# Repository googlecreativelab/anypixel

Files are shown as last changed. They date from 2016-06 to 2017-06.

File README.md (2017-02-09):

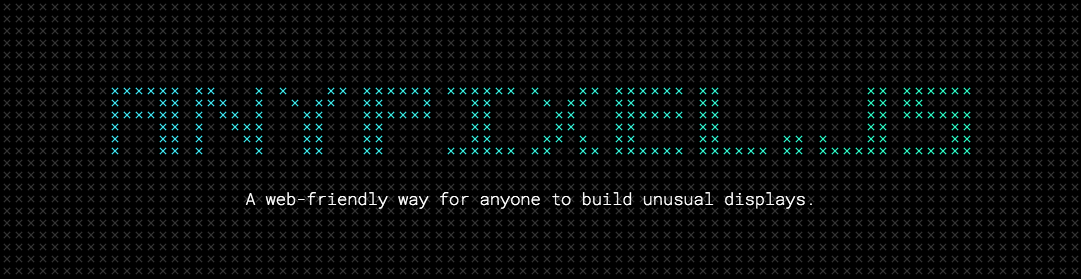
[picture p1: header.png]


[AnyPixel.js](http://googlecreativelab.github.io/anypixel) is an open-source software and hardware library that makes it possible to use the web to create big, unusual, interactive displays. Anyone can fork the code and the schematics to create their own display at any scale.

The first display using this platform is in the 8th Avenue lobby at the Google NYC office. To create this installation, we used 5880 off-the-shelf arcade buttons with LEDs inside them as our pixels. AnyPixel.js’ straightforward hardware/software framework makes it easy to build any display where each pixel is an interactive element.

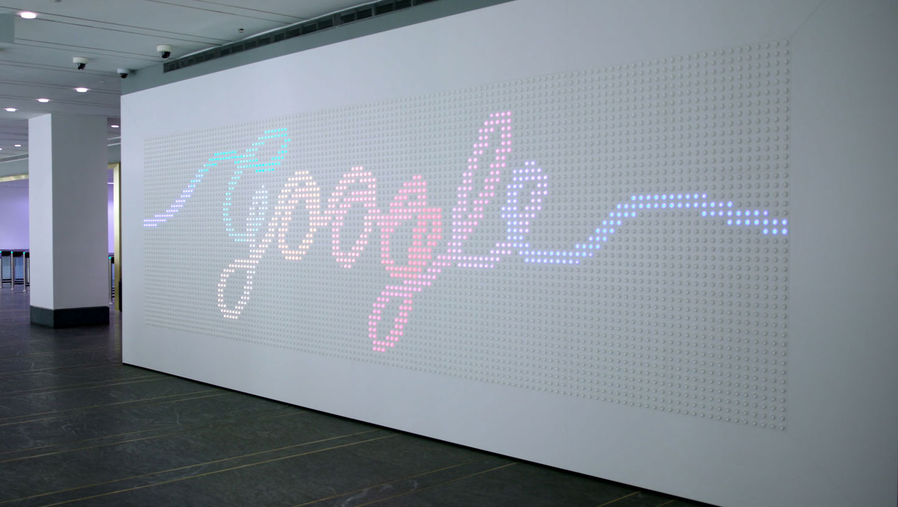
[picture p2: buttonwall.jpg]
buttonwall


## What You'll Find
- **/hardware** - EAGLE schematics, board layouts, CAD files, wiring diagrams, and blueprints.
- **/firmware** - microcontroller code, written for the STM32 family of devices.
- **/backend** - node.js and chrome applications for communicating with the hardware.
- **/frontend** - the app framework, an in-browser previewer, and 12 example apps written by Googlers and friends worldwide.
- **/rpi-example** - a simple starter example connecting a Raspberry Pi with AnyPixel to a single button for round trip communication.

## Getting Started

### Check out the examples 
We've included 12 example apps written by Googlers and friends for the 8th Avenue lobby display in NYC. To check them out, install the [previewer](https://github.com/googlecreativelab/anypixel/tree/master/frontend/previewer) and run one of the [examples](https://github.com/googlecreativelab/anypixel/tree/master/frontend/examples).

### Build your own app 
Building your own app is easy with the Anypixel framework. To get started, check out the [framework documentation](https://github.com/googlecreativelab/anypixel/tree/master/frontend/framework) and the [example app](https://github.com/googlecreativelab/anypixel/tree/master/frontend/examples/getting-started):

```js
var anypixel = require('anypixel'); 
var ctx = anypixel.canvas.getContext2D();

var colors = ['#F00', '#0F0', '#00F'];

/**  
 * * Listen for onButtonDown events and draw a 2x2 rectangle at the event site
 */
document.addEventListener('onButtonDown', function(event) {   
	ctx.fillStyle = colors[Math.floor(Math.random() * colors.length)];
	ctx.fillRect(event.detail.x - 1, event.detail.y - 1, 2, 2);
}); 
```

## Contributors
- [Jeremy Abel](https://github.com/jeremyabel)
- [Kyle Phillips](https://github.com/hapticdata)
- [Nick Fox-Gieg](https://github.com/n1ckfg)
- [Jeramy Morrill](https://github.com/theceremony)
- [Manny Tan](https://github.com/mannytan)
- [Felix Woitzel](https://github.com/flexi23)
- [Anders Hoff](https://github.com/inconvergent)
- [Dimitry Bentsionov](https://github.com/dimitry)
- [Nick Stahlnecker](https://github.com/Stahlneckr)
- [Nick Jonas](https://github.com/nick-jonas)
- [Patrick Miller](https://github.com/patrickdmiller)

## Note
Third party directories may have different (non-Apache 2.0) licenses.

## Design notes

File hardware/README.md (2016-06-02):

## Hardware

- **/mechanical** - CAD files, engineering drawings, and assembly diagrams for the buttonwall installation in NYC.
- **/pcb** - EAGLE files and PDFs for 7x7 LED grid and network controller board.
- **/wiring** - Wiring harness and power diagrams for buttonwall installation in NYC.

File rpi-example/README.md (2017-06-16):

# Starter Example: AnyPixel with Raspberry Pi (1st gen)

We heard your requests for a starter example using the AnyPixel framework. This documentation outlines how to connect a Raspberry Pi to a single LED button for roundtrip communication. 

By the end of this documentation, your Raspberry Pi with AnyPixel will control a red blinking LED and upon interaction turn the light blue. Simple and straightforward.

We hope you scale this project to make other more complex grids at home. If you do, please share!

# Getting Started

You will need to create an LED button [using these steps from Adafruit](https://learn.adafruit.com/neopixel-arcade-button?view=all).

With one LED button, your hardware setup should look like this:

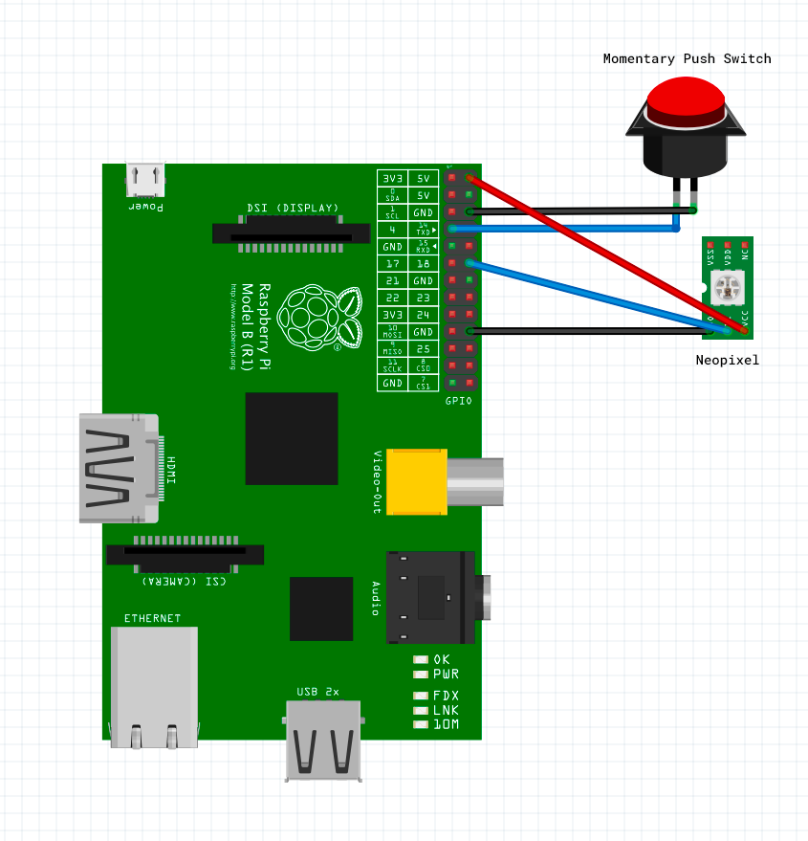
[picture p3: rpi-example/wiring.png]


*<b>NOTE:</b> this example is only known to work on the first generation Raspberry Pi, the libraries used for controlling the WS281x LEDs has not been confirmed to work with Pi 2 hardware.*

*<b>NOTE:</b> If you plan on scaling this example, keep in mind that you may require additional hardware - port expander(s), level shifter(s), and possibly a power supply that supplies a higher amperage (here we're using 5 volts, 2 amps).*

# 1. Setting up Raspberry Pi

### 1. Flash Raspbian

Link for Raspbian images & instructions can be found [here](https://www.raspberrypi.org/downloads/raspbian/)

### 2. Install node.js

#### Download Node.js source Raspberry Pi Model A, B, B+
```
wget https://nodejs.org/dist/v4.0.0/node-v4.0.0-linux-armv6l.tar.gz 
tar -xvf node-v4.0.0-linux-armv6l.tar.gz 
cd node-v4.0.0-linux-armv6l
```

### 3. Run the application

Take the ```/rpi-example``` directory and transfer it to your RPi. You can simply clone this repo on your RPi to get it there easily.  
Run ```npm install``` in that directory.  This will install the GPIO driver dependencies for the app.  
Then run ```sudo node unit.js``` to start listening to the UDP packets that will be sent in the next step.   

# 2. Running the app from host computer

### Install Sample App
Copy and paste ```frontend/examples/getting-started-rpi``` into ```appserver/public/apps/``` and then:

```
cd appserver/public/apps/getting-started-rpi
npm install
npm run build
```

### Install Emulator

```
cd /backend/emulator
npm run build
```
Open Chrome and visit chrome://extensions and click "Load unpackaged extension", and navigate to & select the ```/backend/emulator``` folder.  This should enable the extension with confirmation in Chrome as follows:



### Install & Run UDP Manager

```
cd /backend/udp-manager
npm install
npm start
```

### Install & Run App Server

```
cd /backend/appserver 
mkdir -p public/js
npm install
npm install anypixel
npm run build
npm start
```

### Install ChromeBridge

```
cd /backend/chromebridge
npm install
```

Open Chrome and visit chrome://extensions and click "Load unpackaged extension", and navigate to & select the ```/backend/chromebridge``` folder.  This should enable the extension with confirmation in Chrome as follows:
##### ChromeBridge Enabled


When you launch ChromeBridge, you should see the "Getting Started RPi" application in the dropdown menu, with a black square that turns blue every second.  When you launch the emulator, it should also show up there.
##### ChromeBridge Working
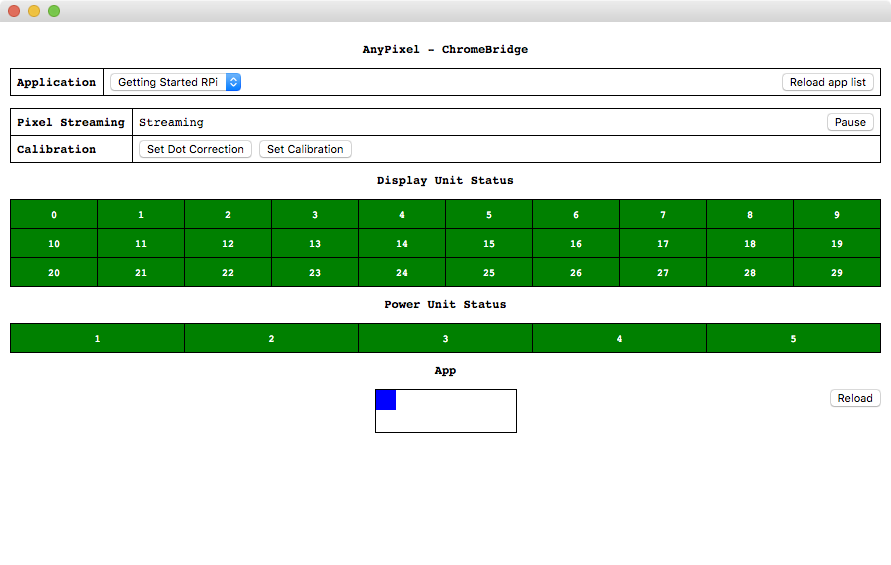
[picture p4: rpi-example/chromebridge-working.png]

##### Emulator Working
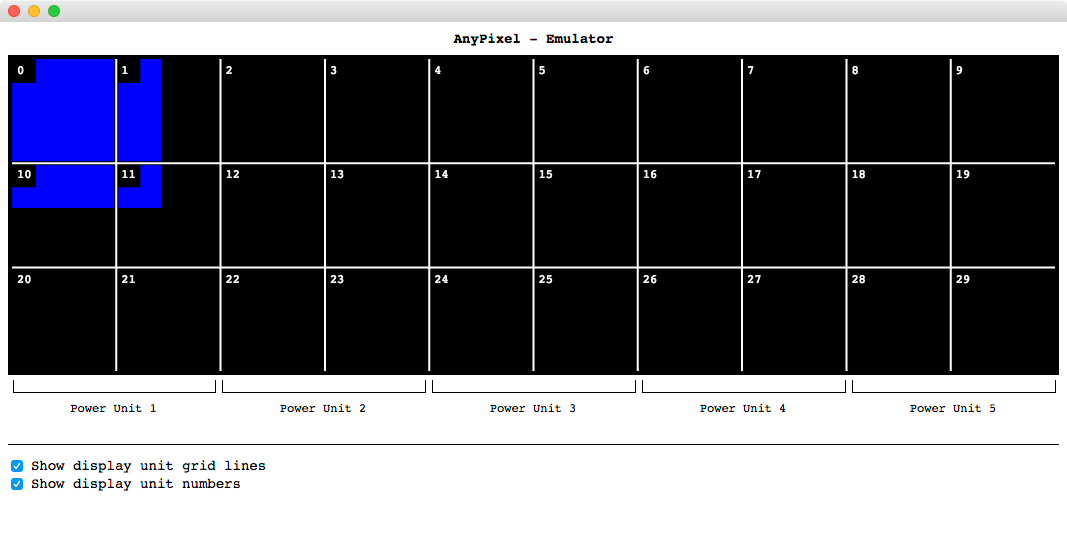
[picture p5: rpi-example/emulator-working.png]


### Point data to Raspberry Pi
Once you confirm that the emulator is working, you can quit it. Now we will start to point messages to the Raspberry Pi.  

Once you have the IP address of the RPi, change out the first unit address in ```backend/config/config.emulator.js```, and match the port set on the RPi server (unless changed, it's set to 3001).  It should look like this, but with your IP address for the first entry:

```
var EmulatorConfig = module.exports = {

  unitAddresses: [
    [
      {ip: '10.0.1.4', port: 3001},
      {ip: '127.0.0.1', port: 3002},
      {ip: '127.0.0.1', port: 3003},
      {ip: '127.0.0.1', port: 3004},
      {ip: '127.0.0.1', port: 3005},
      {ip: '127.0.0.1', port: 3006},
      {ip: '127.0.0.1', port: 3007},
      {ip: '127.0.0.1', port: 3008},
      {ip: '127.0.0.1', port: 3009},
      {ip: '127.0.0.1', port: 3010}
    ],
    [
      {ip: '127.0.0.1', port: 3011},
      {ip: '127.0.0.1', port: 3012},
      {ip: '127.0.0.1', port: 3013},
      {ip: '127.0.0.1', port: 3014},
      {ip: '127.0.0.1', port: 3015},
      {ip: '127.0.0.1', port: 3016},
      {ip: '127.0.0.1', port: 3017},
      {ip: '127.0.0.1', port: 3018},
      {ip: '127.0.0.1', port: 3019},
      {ip: '127.0.0.1', port: 3020}
    ],
    [
      {ip: '127.0.0.1', port: 3021},
      {ip: '127.0.0.1', port: 3022},
      {ip: '127.0.0.1', port: 3023},
      {ip: '127.0.0.1', port: 3024},
      {ip: '127.0.0.1', port: 3025},
      {ip: '127.0.0.1', port: 3026},
      {ip: '127.0.0.1', port: 3027},
      {ip: '127.0.0.1', port: 3028},
      {ip: '127.0.0.1', port: 3029},
      {ip: '127.0.0.1', port: 3030}
    ]
  ],

  powerUnitAddresses: [
    {ip: '127.0.0.1', port: 3031},
    {ip: '127.0.0.1', port: 3032},
    {ip: '127.0.0.1', port: 3033},
    {ip: '127.0.0.1', port: 3034},
    {ip: '127.0.0.1', port: 3035}
  ]
};
```

*<b>NOTE</b>: Normally, the previous step requires changing ```config.physical.js``` instead of ```config.emulator.js```. However, there is a bug at the moment that prevents this. We are working on resolving that bug but it will work as described.*

Rebuild the chromebridge by running ```npm run build``` in ```/backend/chromebridge```, and reload the ChromeBridge app in Chrome.  You should now see your LED button blink blue. When you press it, the button turns red for 1 second. You should also see a red square show up at the top left of your ChromeBridge.   

## At this point you have a full, round-trip connection!  Hack away friends.

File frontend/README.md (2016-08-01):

# Anypixel - Frontend 
The AnyPixel frontend consists of the interactive apps which run on the AnyPixel display, and the framework used for building them. Because the display is a physical installation, a previewer is also provided for testing your apps. The previewer simulates the look and feel of the physical buttonwall in the 8th Avenue lobby in NYC.

## Getting Started

### Check out the examples 
We've included 12 example apps written by Googlers and friends for the 8th Avenue lobby display in NYC. To check them out, install the [previewer](https://github.com/googlecreativelab/anypixel/tree/master/frontend/previewer) and run one of the [examples](https://github.com/googlecreativelab/anypixel/tree/master/frontend/examples).

### Build your own app 
Building your own app is easy with the Anypixel framework. To get started, check out the [framework documentation](https://github.com/googlecreativelab/anypixel/tree/master/frontend/framework) and the [example app](https://github.com/googlecreativelab/anypixel/tree/master/frontend/examples/getting-started):

``` js
var anypixel = require('anypixel'); 
var ctx = anypixel.canvas.getContext2D();

var colors = ['#F00', '#0F0', '#00F'];

/**  
 * * Listen for onButtonDown events and draw a 2x2 rectangle at the event site
 */
document.addEventListener('onButtonDown', function(event) {   
	ctx.fillStyle = colors[Math.floor(Math.random() * 3)];
	ctx.fillRect(event.detail.x - 1, event.detail.y - 1, 2, 2);
}); 
```

## What You'll Find 
- **/examples** - 12 example apps written by Googlers and friends 
- **/framework** - the framework for building your own Anypixel apps 
- **/previewer** - an in-browser previewer for testing your apps

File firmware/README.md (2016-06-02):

# Anypixel - Firmware

## What You'll Find
- **/controller** - firmware for the controller PCB, written for the STM32F407 microcontroller
- **/display** - firmware for the LED grid display PCB, written for the STM32F030 microcontroller

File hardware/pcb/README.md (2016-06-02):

# Electronics Overview

## Power

24v power is delivered from the power supply boxes to the LED boards through a 4A fuse. On each LED
board the 24v rail powers three identical 5v buck converters (or alternatively a single 1/4 brick
supply with the three 5v rails bridged together) which provide power to the LEDs and is further
stepped down to 3.3v to power the microcontrollers.  There is also a power supply that steps the 24v
down to 12v to power the cooling fan. The 24v rail is also connected to the RJ12 connection which
goes to the IP controller.

The IP controller has a diode ORing arrangement, accepting power from any of the 4 LED boards and/or
an additional external supply via a barrel connector. There are two switching supplies on the IP
controller board, one with a 3.3v output to power all the onboard electronics, and a 5v output
device for powering accessories through a 2 pin header.

## Data Flow

The IP controller board contains a 3 port 100Mbit Ethernet switch with two ports exposed as RJ45
connectors which allows for daisy chaining boards together eliminating the need for long cable runs
back to a single large switch. The third port of this switch is connected to the STM32F407
microcontroller on the IP controller which takes in packets containing data for a complete 14x14
button panel. The firmware divides this data into 4 smaller packets and send these to the 4
connected 7x7 LED boards.

Communication to the LED boards is over asynchronous serial with a baud rate of 1Mbit.  There are 5
STM32F030 microcontrollers on each LED board that each control 9 or 10 RGB LEDs and have the same
number of thermistors and switches as input.  The thermistors are used to report the temperature of
each LED, and the switch is used for user input. The microcontrollers are connected in a chain, with
the TX from the IP controller connected to the first microcontroller's RX, and then the first
microcontroller's TX to the second microcontroller's RX and so on until the 5th microcontroller's TX
connects back to the IP controller's RX.  This configuration and the firmware make the LED board
behave like a large shift register, with each processor gathering its input and replacing it with
its output in the appropriate location in each packet based on its address as the stream of data is
shifted through it.  The packets are delimited by an idle state on the serial line (no signal edges
occur in the time it takes to transmit a complete byte, or about 10 microseconds).

The interface from the STM32F030 microcontrollers to the two TLC59401 LED drivers it controls is
like a shift register as well.  The two TLC59401 chips are connected in series.  There are
additional connections to the TLC59401 to facilitate the PWM signal generation, these include a
grayscale clock and a blanking signal.

## LED drive

The TLC59401 chip is a 16 channel constant current supply PWM controlled LED driver.  The device has
a global reference resistor to set the maximum channel current.  Each channel then has an analog dot
correct circuit which controls the current reference in 64 steps.  This dot correction feature is
used for rough calibration and is not changed during operation.  The global reference combined with
the dot correction circuit provide for a constant current output to drive the LEDs.

The TLC59401 also has PWM to toggle the constant current outputs on and off with a programmable duty
cycle. This is a 12-bit PWM system yielding 4096 discrete intensities for the output on top of the
5-bit/64 value dot correction values, which provides a 17-bit range for the system.  The firmware
implements a lookup table for converting from the typical 8-bits per channel input media to the
12-bit PWM values. Due to memory constrains the lookup table has only 65 entries and uses linear
interpolation to map the complete 256-value/8-bit input range to appropriate output values.

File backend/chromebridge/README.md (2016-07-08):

# Backend - ChromeBridge

ChromeBridge is a [Chrome App](https://developer.chrome.com/apps) which acts as an interface between **Anypixel apps** and the **physical hardware**, as well as a user interface for monitoring and controlling the state of the physical hardware.

## Getting Started

To install:

1. **Install node components** - `$ npm install`

2. **Open the Chrome Extensions page** - In the Chrome browser, navigate to `chrome://extensions`

3. **Enable Developer mode:**


4. **Load the extension** - Click the "Load unpacked extension..." button and select the 
/chromebridge folder. The ChromeBridge app will be added to the top of the extensions list.

4. **Ensure the AppServer and the Emulator are running** - or plug in your physical display hardware.

5. **Launch the app** - click the "Launch" button under the extension title:


To build:

```sh
$ npm run build
```

# Hardware Interface

#### Pixel Data

Each frame, ChromeBridge receives a full frame of raw pixel data from the app currently hosted by the AppServer. This data is split up according to which **display unit** is responsible for displaying the corresponding section of the app canvas. 

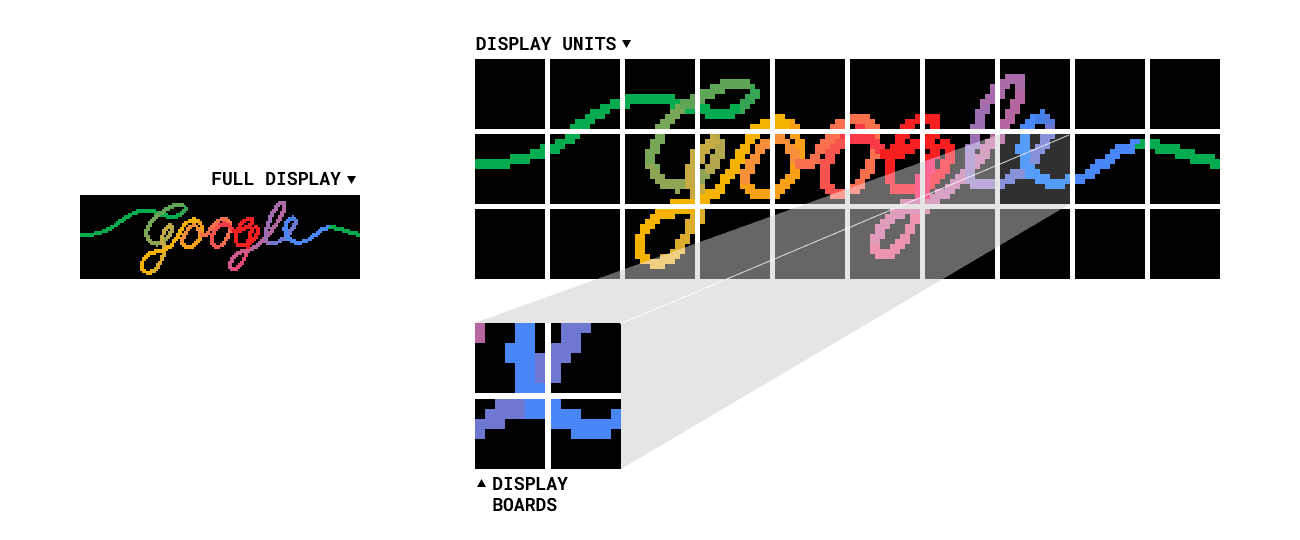
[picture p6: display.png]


Each display unit's pixel data is then moved into a data packet and assigned an IP address and a port corresponding to the address of the matching display unit controller board. To speed things up, several display units' packets are **bundled** into a single UDP packet and are sent to the **udp-manager** to be unbundled and distributed to the IP address stored in each packet.

#### Button Inputs

Every 33ms, the control boards send a list of button input states. ChromeBridge finds the inputs that have changed since the previous frame, and dispatches corresponding input events to the current app.

# User Interface

#### App Status Monitoring

The current application can be changed by choosing an option from the Application dropdown. The dropdown list is populated when ChromeBridge first starts, so if you add any new apps, click the **Reload app list** button to update the list.

#### Pixel Streaming

Pause or resume the sending of pixel data to the display hardware using the **Pause** button. Sometimes pixel streaming will be automatically paused to allow the transmission of calibration or dot correction data.  

#### Hardware Status Monitoring

Every second or so, the hardware will send status data containing information about the overall health of each piece of the system. This includes information like the temperature of each LED, the MAC address of each board, how long each board has been running for, and whether the power supplies are working correctly.

#### Display Unit Monitoring / Control

The overall health of each display unit is shown in a grid. Display units which are not working correctly will be colored in red, while ones that are stable are in green. 

Clicking on a display unit will bring up more detailed information, including a per-pixel temperature display, board MAC addresses, and uptime information. You can also set the dot correction and calibration data for the individual display unit.

#### Power Unit Monitoring / Control

Below the display unit grid is the power unit status display. Each power unit powers the 6 display units above it. Like the display units, green = good, red = bad. Clicking on a power unit will bring up more detailed information about the state of each part of the power supply, and provides controls for switching the power relays on and off.

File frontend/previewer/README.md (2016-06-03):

# Anypixel - Previewer
An in-browser previewer which simulates the look and feel of the physical LED button wall. 
It emulates button events using both mouse and touch inputs, including multi-touch.

### Installation
```sh
$ npm install -g browserify
$ npm install -g https://anypixel-storage.appspot.com/npm/anypixel-previewer.tar.gz
```

### Check out the examples 
We've included 12 example apps written by Googlers and friends for the 8th Avenue lobby display in NYC. After installing the previewer, run one of the [examples](https://github.com/googlecreativelab/anypixel/tree/master/frontend/examples).

### Usage
```
Usage:
  preview [OPTIONS] [ARGS]
  
Options: 
  -f, --file [FILE]        Use this file as the entry point. File path is relative 
                           to the current working directory  (Default is index.js)
  -p, --port [NUMBER]      Run the server on this port  (Default is 9000)
  -b, --background [FILE]  Use this file as the background image. File path is 
                           relative to the current working directory  (Default is lobby.jpg)
  -s, --spacing [NUMBER]   Space between the centers of each button, in pixels  (Default is 14)
  -r, --radius [NUMBER]    Radius of each button, in pixels  (Default is 4.4)
  -x [NUMBER]              Horizontal starting position for the button grid, in 
                           pixels  (Default is 418)
  -y [NUMBER]              Vertical starting position for the button grid, in 
                           pixels  (Default is 470)
  -h, --help               Displays this message
```

### In The Browser

- The page will automatically refresh when the entry file is changed.

- The **Pointer** button is the default input mode: one cursor, one button input at a time.

- The **Hand** button simulates a flat hand pushing against the wall. The shape of the hand is 
randomly generated in a 5x5 grid, and the timing of the inputs is fuzzed to simulate the variations 
of human behavior.

- The **Eye** button toggles an overlay which displays the button events as black squares.

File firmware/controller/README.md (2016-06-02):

# Firmware - Controller

You have to set the correct memory layout for your device in the linker script.
Please check the FLASH and SRAM length.

e.g.

```
MEMORY
{
  FLASH (rx) : ORIGIN = 0x08000000, LENGTH = 0x08000   /* 32k */
  RAM (rwx)  : ORIGIN = 0x20000000, LENGTH = 0x01000   /*  4k */
}
```

This project contains the following third party software located in the ThirdParty subdirectory

- LwIP Lightweight TCP/IP protocol stack
- ST STM32F4 Standard Peripheral Library
- ST STM32F4x7 Ethernet driver (See Application Note AN3966)
- ARM csmis header files (provided with ST Standard Peripheral Library)

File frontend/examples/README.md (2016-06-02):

# Anypixel - Examples

## Getting Started 
To run an example, make sure you install the [previewer app](https://github.com/googlecreativelab/anypixel/tree/master/frontend/previewer), then open any example and do: 

``` 
$ npm install 
$ npm run build 
$ preview 
```

## The Examples
In alphabetical order...

* **Automata** by [Nick Fox-Gieg](https://github.com/n1ckfg) - A simple cellular-automota experiment.

* **Ballpit** by [Kyle Phillips](https://github.com/hapticdata) - A 2d ballpit mural with physics simulation.
	
* **Blocksquish** by [Jeremy Abel](https://github.com/jeremyabel) - The Google logo redrawn as giant squishy rectangles. Touch a letter and it will spring to life.

* **Bouncetype** by [Jeremy Abel](https://github.com/jeremyabel) - Each letter in this bouncy Google logo grow and shrink on 
touch.

* **Heatmap** by [Jeremy Abel](https://github.com/jeremyabel) - An interactive fluid and convention simulation. Touch a button to increase the temperature and watch the fluid curl around the Google logo.

* **Hyperspace** by [Jeremy Abel](https://github.com/jeremyabel) - A leisurely flight through the cosmos. Tap to generate a 
shower of stars or hold to jump to hyperspeed.

* **Inconvergent** by [Anders Hoff](https://github.com/inconvergent) - Randomly spawning particles interact with a colorful wave-like particle spawn generated on touch.

* **Iridescent Life** by [Felix Woitzel](https://github.com/flexi23) - A Bezier spline script drawing animation that writes a scripted Google mixed with an implementation of Conway’s Game of Life and a fluid simulation in WebGL shader code.

* **Reaction** by [Jeremy Abel](https://github.com/jeremyabel) - A simulation of two virtual chemicals interacting according to the rules of a Reaction-Diffusion system.

* **Rope** by [Jeremy Abel](https://github.com/jeremyabel) - A colorful rope traces an undulating hand-drawn “Google” script 
across the screen. Touch and the rope forms a loop around your finger.

* **Squishy** by [Jeramy Morrill](https://github.com/theceremony) - A liquid simulation creates gelatinous, squishy letters that can be thrown around the board. Built using Box2D and Liquidfun.

* **Subway** by [Manny Tan](https://github.com/mannytan) - MTA Subway map inspired design. Press to reroute the trains.

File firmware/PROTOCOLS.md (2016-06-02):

# Comms Protocols

16-bit header, followed by the payload

## PC to Controllers

### Header

| Offset | Size (Bytes) | Field Name | Purpose |
|---|---|---|---|
| 0x00 | 1 | Command ID | Identifies the command to be performed, listed below. |
| 0x01 | 7 | Reserved | Reserved (see command 0x05) |
| 0x08 | 1 | Unit Address | Physical address of the target control board, calculated as 20 + 10 * row + column (zero indexed)
| 0x09 | 1 | Sequence Number | TODO |
| 0x0A | 4 | IP Address | IP address of the target board |
| 0x0C | 2 | Port | TODO |

### Commands

#### 0x01 - Set RGB (8-bit)
**Description:** Sets the colors of all 49 LEDs on a board, using the calibration mapping. Order is 
top-left to bottom-right, row by row. Format is RGB888 (8-bit RGB).

**Payload:**

| Byte | 0 | 1 | 2 | 3 | 4 | 5 | 6 | ... |
|---|:-:|:-:|:-:|:-:|:-:|:-:|:-:|:---:|
| | R | G | B | R | G | B | R | ... |

----------

#### 0x02 - Set RGB (12-bit)
**Description:** Sets the colors of all 49 LEDs on a board, using the calibration mapping. Order is 
top-left to bottom-right, row by row. Format is compacted 12-bit

----------

#### 0x03 - Dot correction (12-bit)
**Description:**

----------

#### 0x04 - Set RGB raw (8-bit)
**Description:**

----------

#### 0x05 - Set calibration lookup table
**Description:**

----------

#### 0x06 - Dot correction (8-bit)
**Description:**

----------

#### 0x07 - Dot correction (6-bit)
**Description:**

----------

#### 0x08 - Calibration lookup table request
**Description:**

----------

#### 0x09 - Set fan speed / mode
**Description:**

----------

#### 0x10 - Relay enable
_Only applies to the control boards in the power box_

**Description:** Flags for enabling the two AC power relays. Set to enable, clear to disable.

**Payload:**

| Byte | 0 | 1 |
|---|:---:|:---:|
| | Relay 1 EN | Relay 2 EN |

----------

#### 0xF0 - Reboot board
**Description:** Triggers a reboot of the controller and/or LED boards. The first four bytes are a 
checksum to prevent accidental reboots. The last byte contains 5 flags: 

|Bit|  7  |  6  |  5  | 4  | 3 | 2 | 1 | 0 |
|---|:---:|:---:|:---:|:----:|:---:|:---:|:---:|:---:|
| |  -  |  -  |  -  | CTRL | LED NW | LED SW | LED SE | LED NE |

Setting the **CTRL** flag will reboot the target control board. Setting each **LED** flag will 
reboot the LED board in the given quadrant.

**Payload:**

| Byte | 0  | 1  | 2  | 3  | 4 |
|---|:----:|:----:|:----:|:----:|:---:|
| |`0x81`|`0x6A`|`0x4E`|`0xB2`|`0b000xxxxx`|

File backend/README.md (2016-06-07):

# AnyPixel - Backend
The AnyPixel backend consists of four applications which work together to provide an interface 
between the javascript-driven AnyPixel apps (the [_frontend_](https://github.com/googlecreativelab/anypixel/tree/master/frontend)) and the physical display 
[hardware](https://github.com/googlecreativelab/anypixel/tree/master/hardware). 

- **AppServer** - A node.js server which locally hosts the AnyPixel apps.

- **ChromeBridge** - A Chrome app which displays AnyPixel apps and handles the communication between the AppServer apps and the physical display hardware. 

- **UdpManager** - A node.js app which distributes data packets from ChromeBridge to the individual hardware components.

- **Emulator** - A Chrome app for debugging, which simulates the network communications 
between ChromeBridge and the physical display hardware.

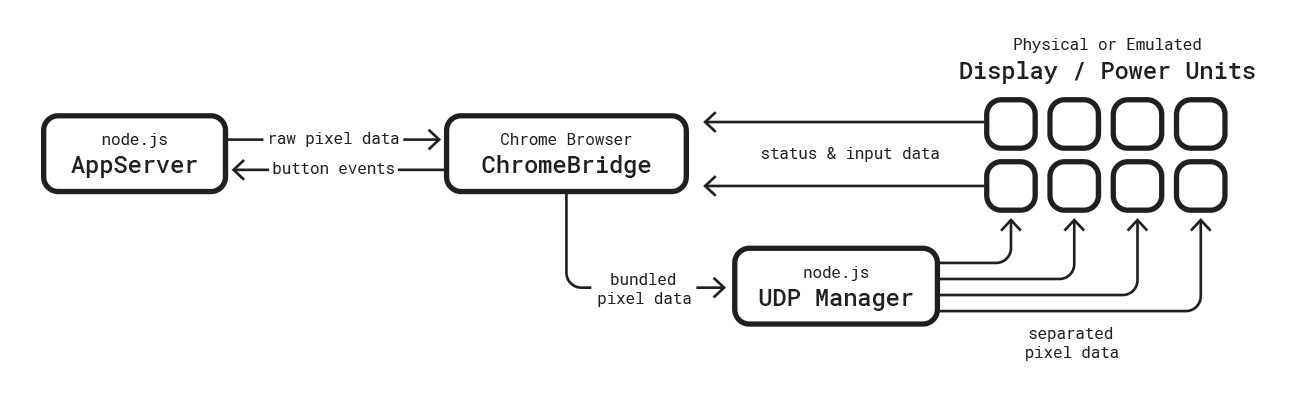
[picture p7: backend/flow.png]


## Installation & Startup
_These instructions assume a basic familiarity with the command line of your particular system. 
For a good introduction to the command line, check out 
[The Command Line Crash Course](http://cli.learncodethehardway.org/book/)._

### Getting Started
1. **Download and install [node.js](https://nodejs.org/en/).**

2. **Install [browserify](http://browserify.org/)** - `$ npm install -g browserify`

---------

### AppServer
1. **Install node components** - In the /appserver directory, do: `$ npm install`

2. **Start the server** - In the /appserver directory, do `$ npm start`

To stop the server, do `$ npm stop`

_For more info on adding your own apps to the AppServer, see the [AppServer README](https://github.com/googlecreativelab/anypixel/tree/master/backend/appserver)._

---------

### UdpManager
1. **Install node components** - In the /udp-manager directory, do: `$npm install`

2. **Start the manager** - In the /udp-manager directory, do `$ npm start`

To stop the manager, do `$ npm stop` 

---------

### Emulator
1. **Install node components** - In the /emulator directory, do: `$ npm install`

2. **Install and launch the Chrome app** - Follow the ChromeBridge installation instructions above, 
except when loading the extension, select the **/emulator** folder instead.

---------

### ChromeBridge
1. **Install node components** - In the /chromebridge directory, do: `$ npm install`

2. **Open the Chrome Extensions page** - In the Chrome browser, navigate to `chrome://extensions`

3. **Enable Developer mode:**


4. **Load the extension** - Click the "Load unpacked extension..." button and select the 
/chromebridge folder. The ChromeBridge app will be added to the top of the extensions list.

4. **Ensure the AppServer and the Emulator are running** - or plug in your physical display hardware.

5. **Launch the app** - click the "Launch" button under the extension title:


_For more info on using the ChromeBridge app, see the [ChromeBridge README](https://github.com/googlecreativelab/anypixel/tree/master/backend/chromebridge)_.

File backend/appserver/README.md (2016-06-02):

# Backend - AppServer
AppServer is a node.js app which runs Anypixel apps from an [Express](http://expressjs.com/) server. This is what holds the canvas that your Anypixel app will draw on. Each frame it will send the pixel data from this canvas to ChromeBridge, where it will be sent on to the physical display itself. It also provides a RESTful API for changing the current app and for listing the available apps.

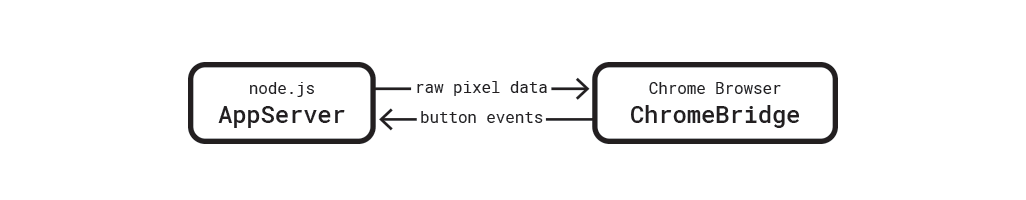
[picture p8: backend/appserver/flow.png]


## Getting Started

1. **Install node components** - `$ npm install`

2. **Start the server** - `$ npm start`

To stop the server, do `$ npm stop` <br />

**To add your own apps:** <br />
Copy your app folder into `/public/apps` and make sure you have an index.js file in your root app directory.

## API

### Get App
Renders an HTML page containing the requested app.

* **URL:** <br />
  /app/:app_name

* **Method:** <br />
  `GET`

* **URL Parameters:** <br />
  `app_name=[string]`

* **Success Response:**
  * **Code:** 200 <br />
    **Content:** Rendered EJS template HTML containing the requested app.
    
* **Error Response:**
  * **Code:** 404 <br />
    **Content:** `Invalid app name`

### Get Available Apps
Returns an array of the valid app names and directories

* **URL:** <br />
  /api/apps

* **Method:** <br />
  `GET`

* **URL Parameters:** <br />
  None

* **Success Response:**
  * **Code:** 200 <br />
   **Content:** <br />
   ```
   {
	    success: true,
	    apps: [
		    {
			    name: "My App",
			    path: "myApp"
		    }
	   ]
   }
   ```

* **Error Response:** <br />
None

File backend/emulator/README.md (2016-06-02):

# Backend - Emulator

The emulator is a [Chrome App](https://developer.chrome.com/apps) which simulates the network communications of the physical display hardware. Each [display unit](#TODO) listens for UDP packets on a separate port, just as the physical display units each have individual IP addresses.

To configure the IP address and port settings for the emulator, see [config/config.emulator.js](https://github.com/googlecreativelab/anypixel/blob/master/backend/config/config.emulator.js). Changes to the config files will require rebuilding both the emulator and [ChromeBridge](https://github.com/googlecreativelab/anypixel/tree/master/backend/chromebridge).

## Getting Started

To install:

1. **Install node components** - `$ npm install`

2. **Open the Chrome Extensions page** - In the Chrome browser, navigate to `chrome://extensions`

3. **Enable Developer mode:**


4. **Load the extension** - Click the "Load unpacked extension..." button and select the 
/emulator folder. The Emulator app will be added to the top of the extensions list.

4. **Launch the app** - click the "Launch" button under the extension title:


To build:

```sh
$ npm run build
```

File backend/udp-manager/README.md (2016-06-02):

# Backend - UDP Manager
UDP Manager is a node.js app which receives pixel data from ChromeBridge and distributes it to each [display unit](#).

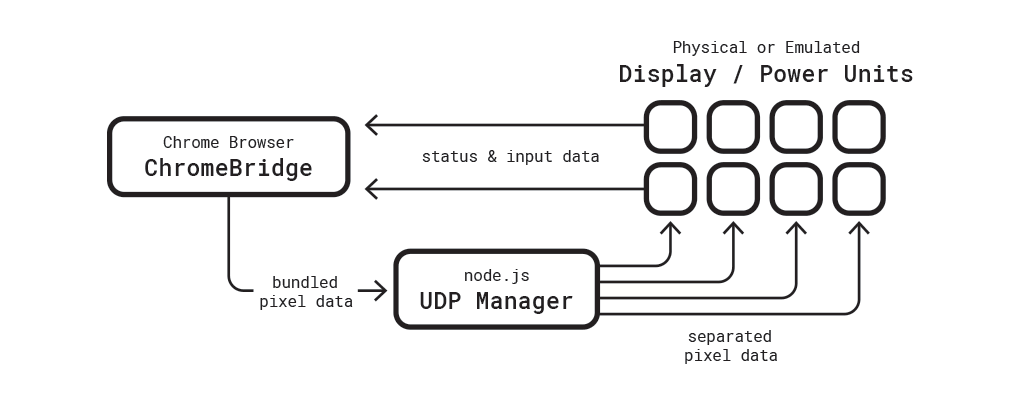
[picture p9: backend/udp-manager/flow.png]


Multiple display unit data is bundled into the packets from ChromeBridge, and these packets are unbundled and sent off to the correct display unit here.

## Getting Started

1. **Install node components** - `$npm install`

2. **Start the manager** - `$ npm start`

To stop the manager, do `$ npm stop`

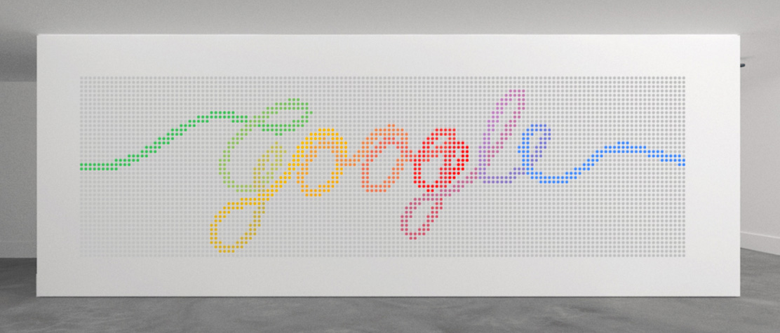
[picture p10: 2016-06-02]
frontend/examples/rope/preview.jpg

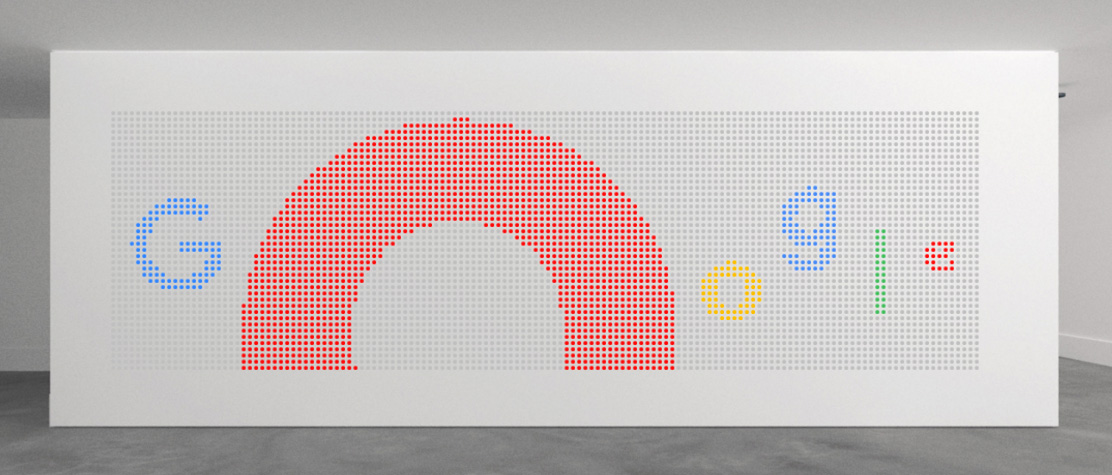
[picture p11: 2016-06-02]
frontend/examples/bouncetype/preview.jpg

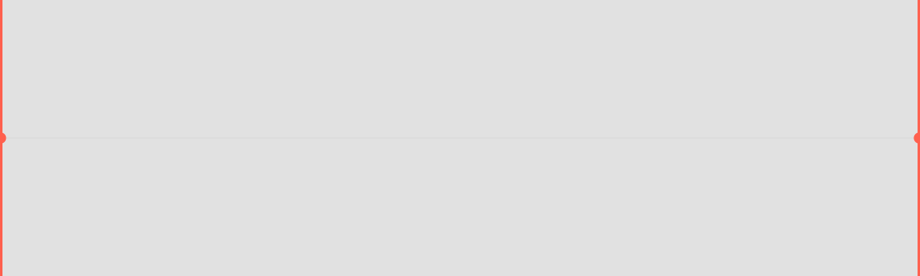
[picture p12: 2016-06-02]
frontend/examples/rope/tangentcircle.gif

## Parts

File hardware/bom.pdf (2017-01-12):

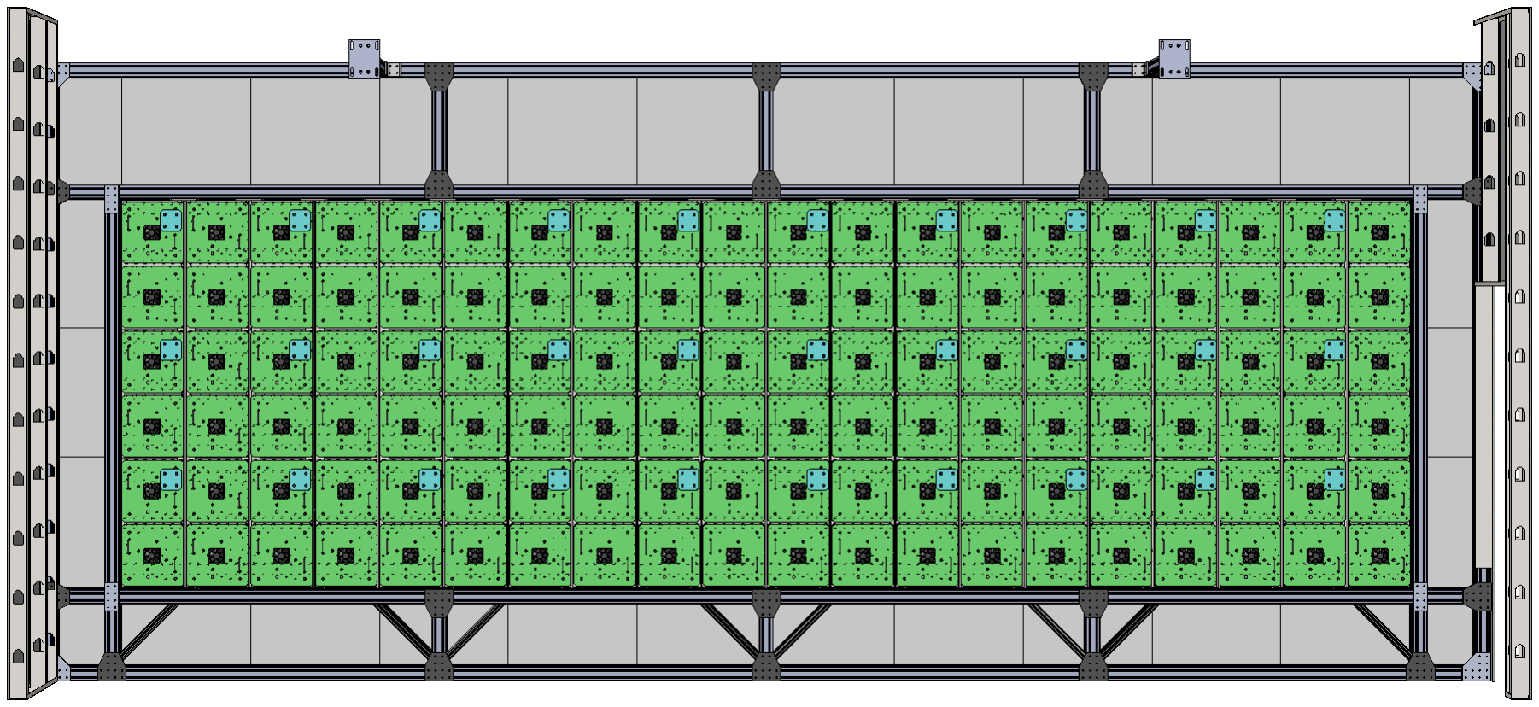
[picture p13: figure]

### GBW - 110 Assembly : Total System

Model Name | MFG Part # | Description | QTY
GBW-102 GBW-200 | GBW-209 GBW-200 | Main Structural Frame Assembly 14 X 14 Button Array Assembly | 1 30

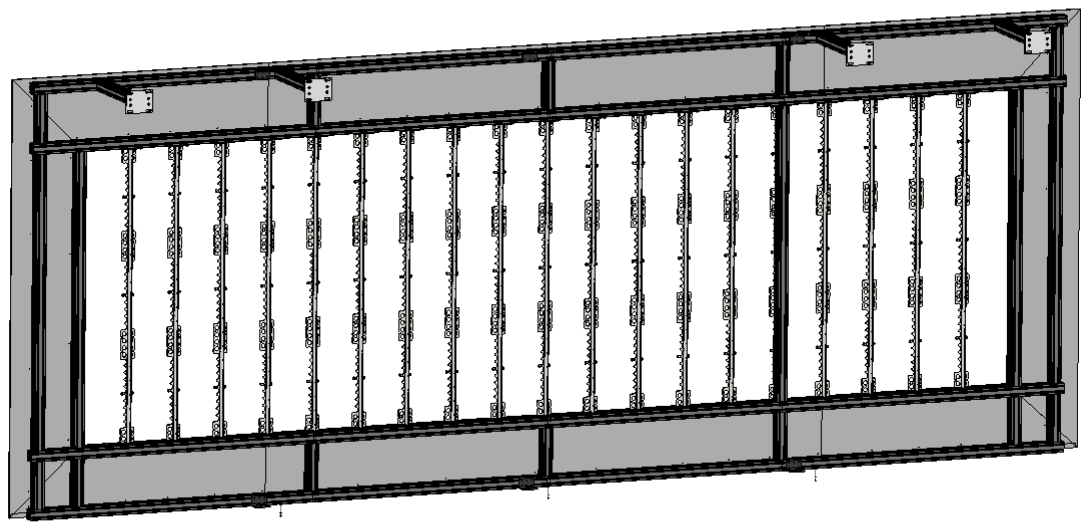
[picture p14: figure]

### GBW - 209 Assembly : Main Structural Frame

| Model Name | MFG Part # | Description | Link | QTY
DEEPLOCAL | GBW-308 GBW-204 | GBW-308 GBW-204 | Corian Wall Face Sheets (see cutlist) Vertical Panel Mount Rib Assembly | | 1 20
8020 | GBW-320 GBW-321 3370 3097 2410 2577 | GBW-320 GBW-321 3370 - Black 3097 2410 - Black 2577 - Black | End Strucutral Section Assembly (see cutlist) Middle Strucutral Section Assembly (see cutlist) Butt Fastner Assembly Long Double Anchor Assembly Mounting Base 45deg Support | link (https://8020.net/3370-black.html) link (https://8020.net/3097.html) link (https://8020.net/2410-black.html) link (https://8020.net/2577-black.html) | 2 2 48 78 2 8

McMasterCarr

Client | GBW-309 GBW-311 & 310 | | Drywall Return Walls + Doorway C- Strut Wall Studs

### GBW - 200 Assembly : 14 x 14 Button Array w/Control PCBs and Corian Face (QTY: 30 in total system)

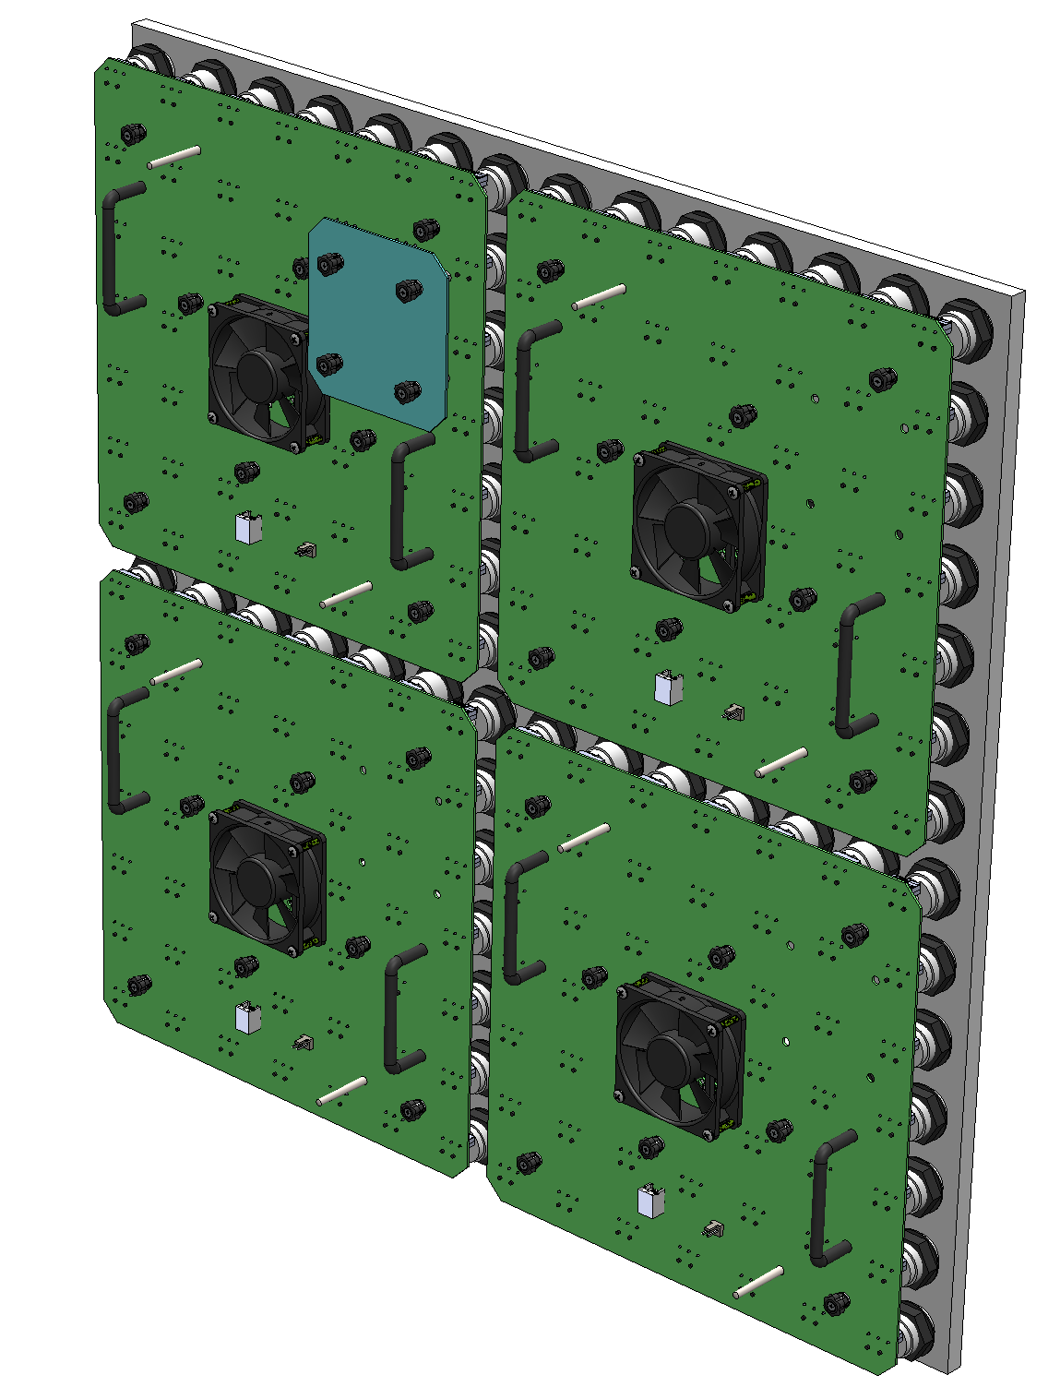
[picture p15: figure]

| Model Name | MFG Part # | Description | Link | QTY
DEEPLOCAL | GBW-001 GBW-002 GBW-002 | | 7x7 Array Main PCB Assembly IP Module PCB Assembly Glacier White Corian® (700 x 700 x 12.7)mm Machined Panel | N/A N/A N/A | 120 30 30
CWC | Delta AUB0812VH (http://partner.delta-corp.com/Products/FANUploads/Specification/AUB0812VH-SP00-REV05.pdf) | AUB0812VH | 80mm Fan 42CFM 39dBA (4-pin) | link (http://www.cwc-group.com/) | 120

McMasterCarr

93505A129 | 93505A129 | Panel Standoff #6-32 x 1.5" | link (http://www.mcmaster.com/mv1447969258/#93505A127) | 960
93505A446 | 93505A446 | IP Module Standoff #6-32 x 1" | link (http://www.mcmaster.com/mv1447360089/#93505A446) | 120
96562A201 | 96562A201 | Fan Screws #8-32 x 1 1/4" | link (http://www.mcmaster.com/mv1447360089/#96562A201) | 480
92284A255 | 92284A255 | PCB Alignment Pins | link (http://www.mcmaster.com/mv1447360089/#92284A255) | 240
93505A027 | 93505A027 | Standoffs for Alignment Pins | link (http://www.mcmaster.com/mv1447969258/#93505A027) | 240

92395A515 | 92395A515 | #10-32 Threaded Inserts | link (http://www.mcmaster.com/mv1447969258/#92395A515) | 480
92395A113 | 92395A113 | #6-32 Threaded Inserts | link (http://www.mcmaster.com/#92395a113/=zydga1) | 960
1568A43 | 1568A43 | PCB Handles | link (http://www.mcmaster.com/mv1447360089/#1568A43) | 240
96562A192 | 96562A192 | Handle Screws | link (http://www.mcmaster.com/mv1447360089/#96562A192) | 480
SuzzoHapp | 58-0091-SH | 58-0091-SH | Bezel Assembly with Nut, No Switch | link (https://na.suzohapp.com/products/arcade_game_parts/58-0091-SH) | 5880
Elma | 1216.1005 | 1216.1005 | Mentor 5mm Light Pipe and Holder (cut to length) | link (http://www.mentor-bauelemente.de/produktpdf/?katalog=ll&pdf=ll13-40.pdf&id=33) | 5880
PEM Engineering | PSHP-632-0L001 SMTSO-832-2ET SMTSO-632-2ET | SMTPR-6-1 PSHP-632-0L001 SMTSO-832-2ET SMTSO-632-2ET | Panel Screw Retainer Panel Screw Fan Screw Mounts IP Module Mounts | link (http://catalog.pemnet.com/keyword/?plpver=1018&key=all&keycateg=100&SchType=1&keyword=smtpr-6-1) link (http://catalog.pemnet.com/keyword/?plpver=1018&key=all&keycateg=100&SchType=1&keyword=PSHP-632) link (http://catalog.pemnet.com/item/uts-and-spacers-standoffs-surface-mount-type-smtso/t-nuts-and-spacers-standoffs-br-type-smtso-unified/smtso-832-2et) link (http://catalog.pemnet.com/item/uts-and-spacers-standoffs-surface-mount-type-smtso/t-nuts-and-spacers-standoffs-br-type-smtso-unified/smtso-632-2et) | 1080 1080 480 120

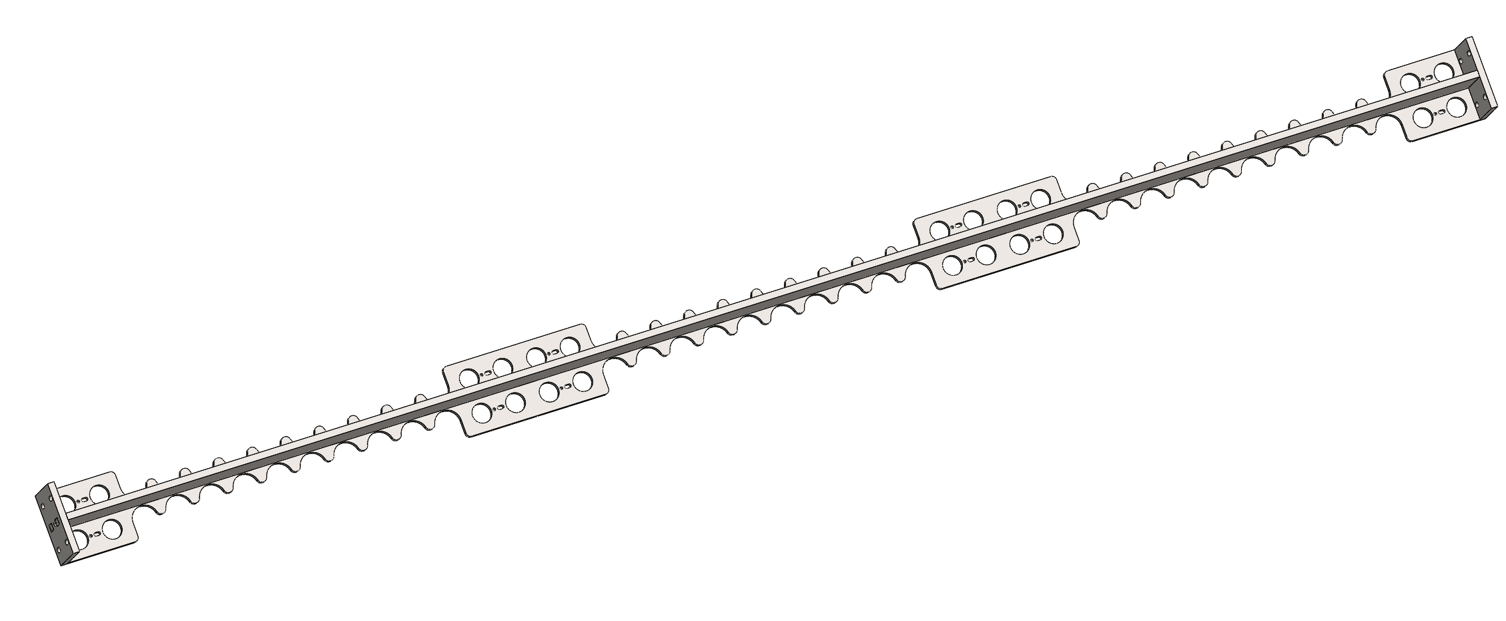
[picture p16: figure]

### GBW - 204 Assembly : Vertical Panel Mount Rib (QTY: 20 in total system)

| Model Name | Sub Part # | Description | Link | QTY
DEEPLOCAL | GBW-300 | End Plates Flange Plate Wed Plate | 1/4" Plate w/mounting holes 1/4" Plate w/button cutouts + tabs 1/4" Plate w/tabs | | 40 20 20
Weldment Fabrication | | | | | 20
Powdercoating | | | | | 20
McMasterCarr | 94579A300 91255A265 92845A335 | 94579A300 91255A265 92845A335 | #10-32 Weld Nut #10-32 x 1/2" Button Screw #10-32 x 3/8" Set Screw | link (http://www.mcmaster.com/mv1447969258/#94579A300) link (http://www.mcmaster.com/mv1447969258/#91255A265) link (http://www.mcmaster.com/mv1447969258/#92845A335) | 240 240 240

### GBW -EE - 200 Assembly : Power Box Assembly (QTY: 5 in total system)

| Model Name | MFG Part # | Description | Link | QTY
Deeplocal | GBW-EE-200 | GBW-EE-200 | Power Box Assembly | GBW_EE_200 | 5
Digi-Key | Molex Molex Qualtek | 50579410 16020103 08172 | 10 Pin locking Connector 24-22AWG Crimp 14" DIN Rail Fan Finger Guard | Digikey (http://www.digikey.com/product-search/en?vendor=0&keywords=50579410) Digikey (http://www.digikey.com/product-search/en?keywords=WM2512-ND) DK (http://www.digikey.com/product-detail/en/08172/CR229-ND/50307) | 10 100 10 5
Powerwerx | Anderson Power | 1462G1 | Powerpole Panel Bracket | Powerwerx (http://www.powerwerx.com/powerpole-accessories/1463G1-75-amp-mounting-clamp-set.html) | 10
McMaster | 7335K24 7335K44 | 7335K24 7335K44 | Fibox Power Box Enclosure Enclosure Panel | link (http://www.mcmaster.com/#7335k24/=10a6gp9) link (http://www.mcmaster.com/#catalog/121/891/=10a6ioh) | 5 5
SF Cable | GBW_EE_104 | SF-1618-06B | Nema 6-20P to IEC C19 | SF Cable (http://www.sfcable.com/SF-1618-06B.html) | 5

### GBW_EE_101/2/3 Assembly : Panel Power Harness (QTY: 30 in total system)

| Model Name | MFG Part # | Description | Link | QTY
DEEPLOCAL | GBW_EE_101 GBW_EE_102 GBW_EE_103 | GBW_EE_101 GBW_EE_102 GBW_EE_103 | Short Panel Power Wire Harness Medium Panel Power Wire Harness Long Panel Power Wire Harness | GBW_EE_101 GBW_EE_102 GBW_EE_103 | 5 5 5

### GBW_EE_105 Assembly : LED PCB Power Harness (QTY: 30 in total system)

| Model Name | MFG Part # | Description | Link | QTY
DEEPLOCAL | GBW_EE_105 | GBW_EE_105 | Panel Harness | GBW_EE_105 | 30

### GBW_EE_10X Assembly : Wire Harness List

| Model Name | MFG Part # | Description | Link | QTY
Cable Wholesale | GBW_EE_106 | 8102-66101 | Control Harness NW - 12" RJ12 6P6C Straight | | 30
Cables on Demand | GBW_EE_107/8 GBW_EE_109 GBW_EE_110 | MP-5FRJ12STWS-002 Control Harness SW/NE - 24" RJ12 6P6C Straight MP-5FRJ12STWS-003 Control Harness SE - 36" RJ12 6P6C Straight MP-5ERJ45UNNK-003 Control to Control Ethernet Jumper | | | 60 30 30

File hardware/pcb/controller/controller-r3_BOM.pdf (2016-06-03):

Qty | Value | Part Num | Package | Parts | Mfg Name | VID | Vendor Part Num | Description | Pkg Code
24 | .1uF | CGA3E2X7R1H104K080A | C0603B | C5, C6, C8, C9, C10, C11, C15, C16, C18, C20, C21, C24, C25, C27, C28, C33, C34, C35, C36, C39, C42, C43, C44, C45 | TDK Corporation | DK | 445-5666-1-ND | CAP CER 0.1UF 50V 10% X7R 0603 | 0603 (1608 Metric)
1 | 0R | CRCW06030000Z0EA | R0603B | R24 | Vishay Dale | DK | 541-0.0GCT-ND | RES 0.0 OHM 1/10W JUMP 0603 SM | 0603 (1608 Metric)
1 | 1A fuse | 0001.2504 | * | PH1 | Schurter Inc. | DK | 486-1782-ND | FUSE CERM 1A 250VAC 300VDC 5X | 5mm x 20mm
1 | 1X2_70543 | 0705430001 | MOLEX_70543-000 | J5 | Molex, LLC | DK | WM4800-ND | CONN HEADER 2POS .100 VERT GO | None
5 | 1k | CRCW06031K00FKEA | R0603B | R10, R16, R20, R27, R30 | Vishay Dale | DK | 541-1.00KHCT-ND | RES 1.00K OHM 1/10W 1% 0603 SMD | 0603 (1608 Metric)
1 | 1k1 | CRCW06031K10FKEA | R0603B | R33 | Vishay Dale | DK | 541-1.10KHCT-ND | RES SMD 1.1K OHM 1% 1/10W 0603 | 0603 (1608 Metric)
2 | 1uF | CGA3E3X5R1H105K080A | C0603B | C23, C26 | TDK Corporation | DK | 445-7878-1-ND | CAP CER 1UF 50V 10% X5R 0603 | 0603 (1608 Metric)
2 | 2.2uF | C1608X5R1V225K080AC | C0603B | C22, C32 | TDK Corporation | DK | 445-8025-1-ND | CAP CER 2.2UF 35V 10% X5R 0603 | 0603 (1608 Metric)
1 | 2x1 housing | 0050579402 | * | PH6 | Molex, LLC | DK | WM2900-ND | CONN HOUSING 2POS .100 W/LATC | None
1 | 2x8 header | SBH11-PBPC-D08-ST-BK | ML16 | J2 | Sullins Connector Solutions | DK | S9171-ND | CONN HEADER 2.54MM 16POS GOL | None
1 | 2x8 ribbon cable | H3CCH-1606G | * | PH7 | Assmann WSW Components | DK | H3CCH-1606G-ND | IDC CABLE - HKC16H/AE16G/HKC16 | None
6 | 4k75 | CRCW06034K75FKEA | R0603B | R12, R13, R15, R17, R29, R31 | Vishay Dale | DK | 541-4.75KHCT-ND | RES 4.75K OHM 1/10W 1% 0603 SMD | 0603 (1608 Metric)
2 | 5pF | CGA3E2C0G1H050C080A | C0603B | C29, C30 | TDK Corporation | DK | 445-5622-1-ND | CAP CER 5PF 50V NP0 0603 | 0603 (1608 Metric)
1 | 5x20 | 64900001039 | 649 | FUSE1 | Littelfuse Inc | DK | WK0011-ND | FUSE BLOCK CART 250V 6.3A PCB | None
2 | 10X1_70553-0009 | 0705530009 | MOLEX_70553-(10) | J1, J3 | Molex, LLC | DK | WM4908-ND | CONN HEADER 10POS .100 R/A GOL | None
14 | 10k | CRCW060310K0FKEA | R0603B | R11, R32, R41, R42, R43, R44, R45, R46, R47, R48, R49, R50, R51, R52 | Vishay Dale | DK | 541-10.0KHCT-ND | RES 10.0K OHM 1/10W 1% 0603 SMD | 0603 (1608 Metric)
5 | 10uF | C1608X6S1A106M080AC | C0603B | C2, C7, C13, C38, C40 | TDK Corporation | DK | 445-9019-1-ND | CAP CER 10UF 10V 20% X6S 0603 | 0603 (1608 Metric)
2 | 10uF 50v | CL31A106KBHNNNE | C1206B | C37, C41 | Samsung Electro-Mechanics America, In | DK | 1276-2876-1-ND | CAP CER 10UF 50V 10% X5R 1206 | 1206 (3216 Metric)
2 | 10x1 housing | 0050579410 | * | PH2 | Molex Inc | DK | WM2908-ND | CONN HOUSING 10POS .100 W/LAT | None
1 | 12k1 | CRCW060312K1FKEA | R0603B | R1 | Vishay Dale | DK | 541-12.1KHCT-ND | RES 12.1K OHM 1/10W 1% 0603 SMD | 0603 (1608 Metric)
2 | 18pF | CGA3E2C0G1H180J080A | C0603B | C12, C14 | TDK Corporation | DK | 445-5631-1-ND | CAP CER 18PF 50V 5% NP0 0603 | 0603 (1608 Metric)
1 | 20MHz | 7A-20.000MAHE-T | 5X3.2 | Y2 | TXC CORPORATION | DK | 887-1766-1-ND | CRYSTAL 20MHZ 12PF SMD | 2-SMD
5 | 22uF | 293D226X96R3B2TE3 | B/3528-21R | C3, C4, C17, C19, C31 | Vishay Sprague | DK | 718-1140-1-ND | CAP TANT 22UF 6.3V 10% 1411 | 1411 (3528 Metric)
1 | 24AA02E48T-I/OT | 24AA02E48T-I/OT | SOT-23-5 | IC3 | Microchip Technology | DK | 24AA02E48T-I/OTCT-N | IC EEPROM 2KBIT 400KHZ SOT23-5 | SC-74A, SOT-753
1 | 25MHz | 7A-25.000MAHE-T | 5X3.2 | Y1 | TXC CORPORATION | DK | 887-1771-1-ND | CRYSTAL 25MHZ 12PF SMD | 2-SMD
2 | 33R2 | CRCW060333R2FKEA | R0603B | R14, R18 | Vishay Dale | DK | 541-33.2HCT-ND | RES 33.2 OHM 1/10W 1% 0603 SMD | 0603 (1608 Metric)
1 | 47R5 | CRCW060347R5FKEA | R0603B | R21 | Vishay Dale | DK | 541-47.5HCT-ND | RES 47.5 OHM 1/10W 1% 0603 SMD | 0603 (1608 Metric)
8 | 49R9 | CRCW060349R9FKEA | R0603B | R2, R3, R4, R5, R6, R7, R8, R9 | Vishay Dale | DK | 541-49.9HCT-ND | RES 49.9 OHM 1/10W 1% 0603 SMD | 0603 (1608 Metric)
6 | 61k9 | CRCW060361K9FKEA | R0603B | R19, R22, R23, R25, R26, R28 | * | * | * | * | *
5 | 100R | MPZ1608S101A | R0603B | L1, L2, L3, L4, L5 | TDK Corporation | DK | 445-1564-1-ND | FERRITE CHIP 100 OHM 3A 0603 | 0603 (1608 Metric)
1 | 100uF | EEU-FM1H101 | E3,5-8 | C100 | Panasonic Electronic Components | DK | P12392-ND | CAP ALUM 100UF 20% 50V RADIAL | Radial, Can
4 | 120R | CRCW1206120RFKEA | R1206B | R37, R38, R39, R40 | Vishay Dale | DK | 541-120FCT-ND | RES SMD 120 OHM 1% 1/4W 1206 | 1206 (3216 Metric)
1 | 220R | 742C083221JP | CTS_742-4 | RN1 | CTS Resistor Products | DK | 742C083221JPCT-ND | RES ARRAY 220 OHM 4 RES 1206 | 1206 (3216 Metric), Concave, Long Side Terminals
3 | 475R | CRCW0603475RFKEA | R0603B | R34, R35, R36 | Vishay Dale | DK | 541-475HCT-ND | RES 475 OHM 1/10W 1% 0603 SMD | 0603 (1608 Metric)
5 | 1000 Ohm | MMZ1608R102A | R0603B | L6, L7, L8, L9, L10 | TDK Corporation | DK | 445-1548-1-ND | FERRITE CHIP 1000 OHM 400MA 060 | 0603 (1608 Metric)
1 | 1000pF 2kV | 202R18W102KV4E | C1206B | C1 | Johanson Dielectrics Inc | DK | 709-1036-1-ND | CAP CER 1000PF 2KV 10% X7R 1206 | 1206 (3216 Metric)
7 | CDBM140-G | CDBM140-G | SOD-123 | D2, D10, D11, D12, D13, D14, D15 | Comchip Technology | DK | 641-1325-1-ND | DIODE SCHOTTKY 40V 1A MINISMA | SOD-123F
1 | KSZ8863MLLI | KSZ8863MLLI | TQFP48 | IC1 | Microchip Technology | DK | 576-3751-ND | IC ETHERNET SWITCH 3PORT 48-L | 48-LQFP
4 | LTC2863 | LTC2863IS8-1#PBF | SO08 | IC4, IC5, IC6, IC7 | Linear Technology | DK | LTC2863IS8-1#PBF-ND | IC TRANSCEIVER RS485 8-SOIC | 8-SOIC (0.154"", 3.90mm Width)
2 | MAGJACK-SI-60062-F | SI-60062-F | SI-60062-F | J102, J103 | Stewart Connector | DK | 380-1106-ND | CONN MAGJACK 1PORT 100 BASE- | None
2 | NFET-IRLML0060-SOT23 | IRLML0060TRPBF | SOT-23 | Q2, Q9 | Infineon Technologies Americas Corp. | DK | IRLML0060TRPBFCT-N | MOSFET N-CH 60V 2.7A SOT-23-3 | TO-236-3, SC-59, SOT-23-3
1 | OKI-78SR-3.3/1.5-W36-C | OKI-78SR-3.3/1.5-W36-C | OKI-78SR-V | IC101 | Murata Power Solutions Inc. | DK | 811-2195-5-ND | CONV DC/DC 4.95W 36VIN 3.3VOUT | 3-SIP Module
1 | OKI-78SR-5/1.5-W36-C | OKI-78SR-5/1.5-W36-C | OKI-78SR-V | IC100 | Murata Power Solutions Inc. | DK | 811-2196-5-ND | CONV DC/DC 7.5W 36VIN 5VOUT | 3-SIP Module
1 | PJ-102AH | PJ-102AH | PJ-102(DC_JACK) | J100 | CUI Inc | DK | CP-102AH-ND | CONN PWR JACK 2.1X5.5MM HIGH | None
4 | RJ-12 plug | 940-SP-3066 | * | PH4 | Stewart Connector | DK | 380-1004-ND | CONN MOD PLUG 6P6C UNSHIELDE | None
1 | RJ-12 wire | * | * | PH5 | * | * | * | * | *
1 | RJ12-QUAD | SS-666604-NF | SS-666604-NF | J101 | Stewart Connector | DK | 380-1032-ND | CONN MOD JACK 6P6C R/A UNSHL | None
4 | SCREW-632-0-PSHP | * | SMTPR-6-1 | SCREW1, SCREW2, SCREW3, SCREW4 | * | * | * | * | *
2 | SH-7050TA | SH-7050TA | SH-7050TA | S1, S2 | Copal Electronics Inc | DK | 563-1213-1-ND | SWITCH ROTARY HEX 16POS SMD | None
1 | STM32-SW-DF13V | DF13C-6P-1.25V(20) | DF13-6P-1.25V | J4 | Hirose Electric Co Ltd | DK | H2211-ND | CONN HEADER 6POS 1.25MM SMD | None
1 | STM32F407VGT6 | STM32F407VGT6 | LQFP-100 | IC2 | STMicroelectronics | DK | 497-11605-ND | IC MCU 32BIT 1MB FLASH 100LQFP | 100-LQFP
22 | contact for c-grid 22-24awg gol | 0016020103 | * | PH3 | Molex, LLC | DK | WM2512-ND | CONN TERM FEMALE 22-24AWG GO | None
8 | green | LTST-C190KGKT | CHIPLED_0603 | LED1, LED3, LED4, LED5, LED6, POWER, POWER1, POWER2 | Lite-On Inc | DK | 160-1435-1-ND | LED GREEN CLEAR 0603 SMD | 0603 (1608 Metric)
1 | red | LTST-C190KRKT | CHIPLED_0603 | LED2 | Lite-On Inc | DK | 160-1436-1-ND | LED SUPER RED CLEAR 0603 SMD | 0603 (1608 Metric)

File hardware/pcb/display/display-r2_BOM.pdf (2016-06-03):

Qty | Value | Part Num | Package | Parts | Mfg Name | VID | Vendor Part Num | Description | Pkg Code
6 | | LTW-006DCG-E2 | LTW-006DCG | LED50, LED51, LED52, LED53, LED54, LED55 | Lite-On Inc. | DK | 160-1870-1-ND | LED WHITE 2SMD R/A | 2-SMD, No Lead
3 | .1uF | * | C0603B | C23, C26, C80 | * | * | * | * | *
40 | .1uF | CGA3E2X7R1H104K080AA | C0603B | C1, C2, C4, C8, C9, C10, C11, C14, C24, C25, C36, C38, C40, C42, C43, C44, C45, C47, C50, C51, C52, C53, C55, C59, C60, C62, C66, C67, C68, C69, C71, C78, C79, C83, C84, C86, C90, C91, C92, C93 | TDK Corporation | DK | 445-5666-1-ND | CAP CER 0.1UF 50V 10% X7R 0603 | 0603 (1608 Metric)
9 | 1R5 | CRCW06031R50FKEA | R0603B | R19, R20, R24, R29, R36, R37, R84, R86, R92 | Vishay Dale | DK | 541-1.50HHCT-ND | RES SMD 1.5 OHM 1% 1/10W 0603 | 0603 (1608 Metric)
1 | 1X2-MTA156 | 640445-2 | 640445-2 | J1 | TE Connectivity | DK | A1971-ND | CONN HEADER VERT 2POS .156 TIN | None
11 | 1uF | CGA3E3X5R1H105K080AB | C0603B | C12, C17, C18, C31, C32, C41, C54, C73, C74, C75, C94 | TDK Corporation | DK | 445-7878-1-ND | CAP CER 1UF 50V 10% X5R 0603 | 0603 (1608 Metric)
3 | 2.2uF | C1608X5R1V225K080AC | C0603B | C16, C33, C72 | TDK Corporation | DK | 445-8025-1-ND | CAP CER 2.2UF 35V 10% X5R 0603 | 0603 (1608 Metric)
10 | 2k2 | CAY16-2201F4LF | CAY16 | RN1, RN2, RN3, RN4, RN5, RN6, RN7, RN8, RN9, RN10 | Bourns Inc. | DK | CAY16-2201F4LFCT-N | RES ARRAY 4 RES 2.2K OHM 1206 | 1206 (3216 Metric), Convex, Long Side Terminals
11 | 2k2 | CRCW06032K20FKEA | R0603B | R2, R14, R15, R38, R39, R65, R66, R80, R81, R105, R106 | Vishay Dale | DK | 541-2.20KHCT-ND | RES SMD 2.2K OHM 1% 1/10W 0603 | 0603 (1608 Metric)
3 | 2k49 | CRCW06032K49FKEA | R0603B | R25, R28, R90 | Vishay Dale | DK | 541-2.49KHCT-ND | RES SMD 2.49K OHM 1% 1/10W 0603 | 0603 (1608 Metric)
5 | 3.3V | TC2185-3.3VCTTR | SOT-23-5 | IC1, IC8, IC11, IC16, IC23 | Microchip Technology | DK | TC2185-3.3VCCT-ND | IC REG LDO 3.3V 0.15A SOT23-5 | SC-74A, SOT-753
3 | 3.3uH | SRP1265A-3R3M | SRP1265A | L1, L2, L3 | Bourns Inc. | DK | SRP1265A-3R3MCT-N | FIXED IND 3.3UH 18A 6.8 MOHM SMD | Nonstandard
6 | 4.7uF | UMK316AB7475KL-T | C1206NT | C20, C21, C28, C29, C76, C77 | Taiyo Yuden | DK | 587-2994-1-ND | CAP CER 4.7UF 50V X7R 1206 | 1206 (3216 Metric)
1 | 4A | 64900001039 | 649 | FUSE1 | Littelfuse Inc | DK | WK0011-ND | FUSE BLOCK CART 250V 6.3A PCB | None
1 | 4A Fuse | BK1-S505H-4-R | * | PH1 | Eaton Bussmann | DK | 283-3533-ND | FUSE CERM 4A 600VAC 400VDC 5X20 | 5mm x 20mm
3 | 4k75 | CRCW06034K75FKEA | R0603B | R51, R52, R54 | Vishay Dale | DK | 541-4.75KHCT-ND | RES 4.75K OHM 1/10W 1% 0603 SMD | 0603 (1608 Metric)
56 | 10k | CRCW060310K0FKEA | R0603B | R4, R5, R6, R7, R9, R10, R11, R12, R13, R17, R22, R23, R30, R31, R32, R33, R40, R42, R43, R45, R46, R47, R49, R50, R55, R56, R57, R58, R59, R60, R61, R62, R64, R68, R71, R72, R73, R74, R76, R77, R78, R79, R82, R85, R87, R88, R95, R96, R97, R98, R100, R101, R102, R103, R104, R108 | Vishay Dale | DK | 541-10.0KHCT-ND | RES 10.0K OHM 1/10W 1% 0603 SMD | 0603 (1608 Metric)
49 | 10k | NCP18XH103F03RB | R0603Y | RT1, RT2, RT3, RT4, RT5, RT6, RT7, RT8, RT9, RT10, RT11, RT12, RT13, RT14, RT15, RT16, RT17, RT18, RT19, RT20, RT21, RT22, RT23, RT24, RT25, RT26, RT27, RT28, RT29, RT30, RT31, RT32, RT33, RT34, RT35, RT36, RT37, RT38, RT39, RT40, RT41, RT42, RT43, RT44, RT45, RT46, RT47, RT48, RT49 | Murata Electronics North America | DK | 490-4800-1-ND | THERMISTOR 10K OHM NTC 0603 SMD | 0603 (1608 Metric)
10 | 10uF | C1608X6S1A106M080AC | C0603B | C3, C5, C35, C37, C46, C48, C61, C63, C85, C87 | TDK Corporation | DK | 445-9019-1-ND | CAP CER 10UF 10V 20% X6S 0603 | 0603 (1608 Metric)
1 | 10uF 16v | CGA4J1X5R1C106K125AC | C0805B | C57 | TDK Corporation | DK | 445-7883-1-ND | CAP CER 10UF 16V 10% X5R 0805 | 0805 (2012 Metric)
1 | 10uF 50V | CL31A106KBHNNNE | C1206B | C58 | Samsung Electro-Mechanics America, In | DK | 1276-2876-1-ND | CAP CER 10UF 50V 10% X5R 1206 | 1206 (3216 Metric)
1 | 12V | P7805-Q24-S12-S | P7805 | IC15 | CUI Inc. | DK | 102-2708-ND | CONVERT DC/DC 0.5A 12V OUT | 3-SIP Module
1 | 24V | 4.0SMDJ24A | SMC/DO214AB | TVS1 | Littelfuse Inc. | DK | F6499CT-ND | TVS DIODE 24VWM 38.9VC DO-214AB | DO-214AB, SMC
5 | 47R5 | CRCW060347R5FKEA | R0603B | R3, R44, R48, R70, R89 | Vishay Dale | DK | 541-47.5HCT-ND | RES 47.5 OHM 1/10W 1% 0603 SMD | 0603 (1608 Metric)
3 | 68uF | PLV1H680MDL1 | E5-10,5 | C19, C30, C82 | Nichicon | DK | 493-14182-ND | CAP POLYMER 68UF 20% 50V T/H | Radial, Can
1 | 120R | CRCW1206120RFKEA | R1206B | R94 | Vishay Dale | DK | 541-120FCT-ND | RES SMD 120 OHM 1% 1/4W 1206 | 1206 (3216 Metric)
3 | 220uF | 16SEPC220MD | E3,5-8 | C15, C34, C70 | Panasonic Electronic Components | DK | P16296-ND | CAP POLYMER 220UF 20% 16V T/H | Radial, Can
1 | 274R | CRCW0805274RFKEA | R0805B | R1 | Vishay Dale | DK | 541-274CCT-ND | RES SMD 274 OHM 1% 1/8W 0805 | 0805 (2012 Metric)
10 | 324R | CRCW0603324RFKEA | R0603B | R8, R16, R18, R41, R67, R69, R75, R83, R99, R107 | Vishay Dale | DK | 541-324HCT-ND | RES SMD 324 OHM 1% 1/10W 0603 | 0603 (1608 Metric)
3 | 475R | CRCW0603475RFKEA | R0603B | R26, R27, R91 | Vishay Dale | DK | 541-475HCT-ND | RES 475 OHM 1/10W 1% 0603 SMD | 0603 (1608 Metric)
1 | 1000 Ohm | MMZ1608R102A | R0603B | L4 | TDK Corporation | DK | 445-1548-1-ND | FERRITE CHIP 1000 OHM 400MA 0603 | 0603 (1608 Metric)
10 | 1000uF | EKZN160ELL102MJ16S | E5-10,5 | C6, C7, C13, C39, C49, C56, C64, C65, C88, C89 | United Chemi-Con | DK | 565-4236-ND | CAP ALUM 1000UF 20% 16V RADIAL | Radial, Can
1 | COMP_FAN-47053 | 0470531000 | 47053 | J8 | Molex, LLC | DK | WM4330-ND | CONN 4 PIN HEADER | None
1 | DS2411R or 11AA02E48 | 11AA02E48T-I/TT | SOT-23 | IC20 | Microchip Technology | DK | 11AA02E48T-I/TTCT-N | IC EEPROM 2KBIT 100KHZ SOT23-3 | TO-236-3, SC-59, SOT-23-3
49 | LED_RGB-LRTB-D | LRTBC9TP-CWD5-1+D5E7-25+ | LRTB_C9TP-D | LED1, LED2, LED3, LED4, LED5, LED6, LED7, LED8, LED9, LED10, LED11, LED12, LED13, LED14, LED15, LED16, LED17, LED18, LED19, LED20, LED21, LED22, LED23, LED24, LED25, LED26, LED27, LED28, LED29, LED30, LED31, LED32, LED33, LED34, LED35, LED36, LED37, LED38, LED39, LED40, LED41, LED42, LED43, LED44, LED45, LED46, LED47, LED48, LED49 | OSRAM Opto Semiconductors Inc. | DK | 475-2898-1-ND | LED RED/GREEN/BLUE DIFF SMD | 6-SMD, No Lead
1 | LTC2863 | LTC2863IS8-1#PBF | SO08 | IC22 | Linear Technology | DK | LTC2863IS8-1#PBF-ND | IC TRANSCEIVER RS485 8-SOIC | 8-SOIC (0.154"", 3.90mm Width)
3 | MIC26901 | MIC26901YJL-TR | MLF28_5X6 | IC6, IC7, IC21 | Microchip Technology | DK | 576-3957-1-ND | IC REG BUCK ADJ 9A SYNC 28MLF | 28-PowerVQFN Variant, 28-MLF®
5 | MMZ1608R102A | MMZ1608R102A | R0603B | FB1, FB2, FB3, FB4, FB5 | TDK Corporation | DK | 445-1548-1-ND | FERRITE CHIP 1000 OHM 400MA 0603 | 0603 (1608 Metric)
1 | NFET-2N7002P,215-SOT2 | 2N7002P,215 | SOT-23 | Q1 | NXP Semiconductors | DK | 568-5818-1-ND | MOSFET N-CH 60V 0.36A SOT-23 | TO-236-3, SC-59, SOT-23-3
4 | NUTSMTSO-632 | * | SMTSO-632-2ET | NUT1, NUT2, NUT3, NUT4 | * | * | * | * | *
4 | NUTSMTSO-832 | * | SMTSO-832-2ET | NUT5, NUT6, NUT7, NUT8 | * | * | * | * | *
1 | RJ12-JACK-RJE01 | RJE0166001 | RJE01-660-01 | J2 | Amphenol Commercial Products | DK | RJE0166001-ND | CONN MOD JACK 6P6C R/A UNSHLD | None
8 | SCREW-632-0-PSHP | * | SMTPR-6-1 | SCREW1, SCREW2, SCREW3, SCREW4, SCREW5, SCREW6, SCREW7, SCREW8 | * | * | * | * | *
3 | SD103AW | SD103AWS-7-F | SOD-323 | D1, D2, D3 | Diodes Incorporated | DK | SD103AWS-FDICT-ND | DIODE SCHOTTKY 40V 350MA SOD323 | SC-76, SOD-323
49 | SPDTDB2CC1AA | DB2CC1AA | DB2CC1AA | S1, S2, S3, S4, S5, S6, S7, S8, S9, S10, S11, S12, S13, S14, S15, S16, S17, S18, S19, S20, S21, S22, S23, S24, S25, S26, S27, S28, S29, S30, S31, S32, S33, S34, S35, S36, S37, S38, S39, S40, S41, S42, S43, S44, S45, S46, S47, S48, S49 | Cherry | DK | CH883-ND | SWITCH SNAP SPDT 10A PC MNT 125V | None
5 | STM32F030C8 | STM32F030C8T6 | LQFP-48 | IC3, IC9, IC13, IC18, IC25 | STMicroelectronics | DK | 497-14043-ND | IC MCU ARM 64K FLASH 48LQFP | 48-LQFP
10 | TLC59401PWP | TLC59401PWPR | TSSOP28_PAD | IC2, IC4, IC5, IC10, IC12, IC14, IC17, IC19, IC24, IC26 | Texas Instruments | DK | 296-25565-1-ND | IC LED Driver Linear 120mA Backlight, Signage 28-HTSS | REF374
5 | TP-CIR30 | * | SMD_CIR30 | TP1, TP2, TP3, TP4, TP5 | * | * | * | * | *
1 | Wire mount connector | 3-644465-2 | * | PH2 | TE Connectivity AMP Connectors | DK | A31372-ND | CONN RECEPT 2POS 18AWG MTA156 | None
3 | dnp | * | C0603B | C22, C27, C81 | * | * | * | * | *
1 | dnp | * | PWR-1/4-BRICK | PWR1 | * | * | * | * | *
4 | dnp | * | R0603B | R21, R34, R53, R93 | * | * | * | * | *
2 | dnp | * | R0805B | R35, R63 | * | * | * | * | *
5 | dnp | * | TC2030-IDC-NL | J3, J4, J5, J6, J7 | * | * | * | * | *
3 | red | LTST-C190KRKT | CHIPLED_0603 | 5V-A_FAIL, 5V-B_FAIL, 5V-C_FAIL | Lite-On Inc | DK | 160-1436-1-ND | LED SUPER RED CLEAR 0603 SMD | 0603 (1608 Metric)
1 | strain relief | 643071-2 | * | PH3 | TE Connectivity AMP Connectors | DK | A19780-ND | CONN STRAIN RELIEF COVER 2POS | None

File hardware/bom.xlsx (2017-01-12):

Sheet: BOM
GBW - 110 Assembly : Total System
 | Model Name | MFG Part # | Description | QTY
 | GBW-102 | GBW-209 | Main Structural Frame Assembly | 1
 | GBW-200 | GBW-200 | 14 X 14 Button Array Assembly | 30
GBW - 209 Assembly : Main Structural Frame
 | Model Name | MFG Part # | Description | Link | QTY
DEEPLOCAL | GBW-308 | GBW-308 | Corian Wall Face Sheets (see cutlist) |  | 1
 | GBW-204 | GBW-204 | Vertical Panel Mount Rib Assembly |  | 20
8020 | GBW-320 | GBW-320 | End Strucutral Section Assembly (see cutlist) |  | 2
 | GBW-321 | GBW-321 | Middle Strucutral Section Assembly (see cutlist) |  | 2
 | 3370 | 3370 - Black | Butt Fastner Assembly | link (https://8020.net/3370-black.html) | 48
 | 3097 | 3097 | Long Double Anchor Assembly | link (https://8020.net/3097.html) | 78
 | 2410 | 2410 - Black | Mounting Base | link (https://8020.net/2410-black.html) | 2
 | 2577 | 2577 - Black | 45deg Support | link (https://8020.net/2577-black.html) | 8
McMasterCarr
Client | GBW-309 |  | Drywall Return Walls + Doorway
 | GBW-311 & 310 |  | C- Strut Wall Studs
GBW - 200 Assembly : 14 x 14 Button Array w/Control PCBs and Corian Face (QTY: 30 in total system)
 | Model Name | MFG Part # | Description | Link | QTY
DEEPLOCAL | GBW-001 |  | 7x7 Array Main PCB Assembly | N/A | 120
 | GBW-002 |  | IP Module PCB Assembly | N/A | 30
 | GBW-002 |  | Glacier White Corian® (700 x 700 x 12.7)mm Machined Panel | N/A | 30
CWC | Delta AUB0812VH (http://partner.delta-corp.com/Products/FANUploads/Specification/AUB0812VH-SP00-REV05.pdf) | AUB0812VH | 80mm Fan 42CFM 39dBA (4-pin) | link (http://www.cwc-group.com/) | 120
McMasterCarr | 93505A129 | 93505A129 | Panel Standoff #6-32 x 1.5" | link (http://www.mcmaster.com/mv1447969258/) | 960
 | 93505A446 | 93505A446 | IP Module Standoff #6-32 x 1" | link (http://www.mcmaster.com/mv1447360089/) | 120
 | 96562A201 | 96562A201 | Fan Screws #8-32 x 1 1/4" | link (http://www.mcmaster.com/mv1447360089/) | 480
 | 92284A255 | 92284A255 | PCB Alignment Pins | link (http://www.mcmaster.com/mv1447360089/) | 240
 | 93505A027 | 93505A027 | Standoffs for Alignment Pins | link (http://www.mcmaster.com/mv1447969258/) | 240
 | 92395A515 | 92395A515 | #10-32 Threaded Inserts | link (http://www.mcmaster.com/mv1447969258/) | 480
 | 92395A113 | 92395A113 | #6-32 Threaded Inserts | link (http://www.mcmaster.com/) | 960
 | 1568A43 | 1568A43 | PCB Handles | link (http://www.mcmaster.com/mv1447360089/) | 240
 | 96562A192 | 96562A192 | Handle Screws | link (http://www.mcmaster.com/mv1447360089/) | 480
SuzzoHapp | 58-0091-SH | 58-0091-SH | Bezel Assembly with Nut, No Switch | link (https://na.suzohapp.com/products/arcade_game_parts/58-0091-SH) | 5880
Elma | 1216.1005 | 1216.1005 | Mentor 5mm Light Pipe and Holder (cut to length) | link (http://www.mentor-bauelemente.de/produktpdf/?katalog=ll&pdf=ll13-40.pdf&id=33) | 5880
PEM Engineering | PSHP-632-0L001 | SMTPR-6-1 | Panel Screw Retainer | link (http://catalog.pemnet.com/keyword/?plpver=1018&key=all&keycateg=100&SchType=1&keyword=smtpr-6-1) | 1080
 |  | PSHP-632-0L001 | Panel Screw | link (http://catalog.pemnet.com/keyword/?plpver=1018&key=all&keycateg=100&SchType=1&keyword=PSHP-632) | 1080
 | SMTSO-832-2ET | SMTSO-832-2ET | Fan Screw Mounts | link (http://catalog.pemnet.com/item/uts-and-spacers-standoffs-surface-mount-type-smtso/t-nuts-and-spacers-standoffs-br-type-smtso-unified/smtso-832-2et) | 480
 | SMTSO-632-2ET | SMTSO-632-2ET | IP Module Mounts | link (http://catalog.pemnet.com/item/uts-and-spacers-standoffs-surface-mount-type-smtso/t-nuts-and-spacers-standoffs-br-type-smtso-unified/smtso-632-2et) | 120
GBW - 204 Assembly : Vertical Panel Mount Rib (QTY: 20 in total system)
 | Model Name | Sub Part # | Description | Link | QTY
DEEPLOCAL | GBW-300 | End Plates | 1/4" Plate w/mounting holes |  | 40
 |  | Flange Plate | 1/4" Plate w/button cutouts + tabs |  | 20
 |  | Wed Plate | 1/4" Plate w/tabs |  | 20
Weldment Fabrication |  |  |  |  | 20
Powdercoating |  |  |  |  | 20
McMasterCarr | 94579A300 | 94579A300 | #10-32 Weld Nut | link (http://www.mcmaster.com/mv1447969258/) | 240
 | 91255A265 | 91255A265 | #10-32 x 1/2" Button Screw | link (http://www.mcmaster.com/mv1447969258/) | 240
 | 92845A335 | 92845A335 | #10-32 x 3/8" Set Screw | link (http://www.mcmaster.com/mv1447969258/) | 240
GBW -EE - 200 Assembly : Power Box Assembly (QTY: 5 in total system)
 | Model Name | MFG Part # | Description | Link | QTY
Deeplocal | GBW-EE-200 | GBW-EE-200 | Power Box Assembly | GBW_EE_200 | 5
Digi-Key | Molex | 50579410 | 10 Pin locking Connector | Digikey (http://www.digikey.com/product-search/en?vendor=0&keywords=50579410) | 10
 | Molex | 16020103 | 24-22AWG Crimp | Digikey (http://www.digikey.com/product-search/en?keywords=WM2512-ND) | 100
 |  |  | 14" DIN Rail |  | 10
 | Qualtek | 08172 | Fan Finger Guard | DK (http://www.digikey.com/product-detail/en/08172/CR229-ND/50307) | 5
Powerwerx | Anderson Power | 1462G1 | Powerpole Panel Bracket | Powerwerx (http://www.powerwerx.com/powerpole-accessories/1463G1-75-amp-mounting-clamp-set.html) | 10
McMaster | 7335K24 | 7335K24 | Fibox Power Box Enclosure | link (http://www.mcmaster.com/) | 5
 | 7335K44 | 7335K44 | Enclosure Panel | link (http://www.mcmaster.com/) | 5
SF Cable | GBW_EE_104 | SF-1618-06B | Nema 6-20P to IEC C19 | SF Cable (http://www.sfcable.com/SF-1618-06B.html) | 5
GBW_EE_101/2/3 Assembly : Panel Power Harness (QTY: 30 in total system)
 | Model Name | MFG Part # | Description | Link | QTY
DEEPLOCAL | GBW_EE_101 | GBW_EE_101 | Short Panel Power Wire Harness | GBW_EE_101 | 5
 | GBW_EE_102 | GBW_EE_102 | Medium Panel Power Wire Harness | GBW_EE_102 | 5
 | GBW_EE_103 | GBW_EE_103 | Long Panel Power Wire Harness | GBW_EE_103 | 5
GBW_EE_105 Assembly : LED PCB Power Harness (QTY: 30 in total system)
 | Model Name | MFG Part # | Description | Link | QTY
DEEPLOCAL | GBW_EE_105 | GBW_EE_105 | Panel Harness | GBW_EE_105 | 30
GBW_EE_10X Assembly : Wire Harness List
 | Model Name | MFG Part # | Description | Link | QTY
Cable Wholesale | GBW_EE_106 | 8102-66101 | Control Harness NW - 12" RJ12 6P6C Straight |  | 30
Cables on Demand | GBW_EE_107/8 | MP-5FRJ12STWS-002 | Control Harness SW/NE - 24" RJ12 6P6C Straight |  | 60
 | GBW_EE_109 | MP-5FRJ12STWS-003 | Control Harness SE - 36" RJ12 6P6C Straight |  | 30
 | GBW_EE_110 | MP-5ERJ45UNNK-003 | Control to Control Ethernet Jumper |  | 30

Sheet: CutLists
GBW-320 Cut List (QTY:2 in total system)
GBW-320 Cut List
ITEM NO. | QTY. | DESCRIPTION | Vendor PN | Link | LENGTH
1 | 3 | Vertical Members (long) | 3030-S-Black | link (https://8020.net/3030-s-black-fb-1.html) | 83.1832
2 | 3 | Vertical Members (short) | 3030-S-Black | link (https://8020.net/3030-s-black-fb-1.html) | 13.41
3 | 2 | Horizontal Members | 3030-S-Black | link (https://8020.net/3030-s-black-fb-1.html) | 84.6476
4 | 2 | Vertical Members (top) | 3030-S-Black | link (https://8020.net/3030-s-black-fb-1.html) | 23
5 | 2 | Horizontal Members | 3030-S-Black | link (https://8020.net/3030-s-black-fb-1.html) | 84.6476
6 | 2 | Back Wall Support Member | 3030-S-Black | link (https://8020.net/3030-s-black-fb-1.html) | 24.5
GBW-321 Cut List (QTY:2 in total system)
GBW-321 Cut List
ITEM NO. | QTY. | DESCRIPTION | Vendor PN | Link | LENGTH
1 | 3 | Horizontal Members | 3030-S-Black | link (https://8020.net/3030-s-black-fb-1.html) | 69.6476
2 | 1 | Vertical Members (top) | 3030-S-Black | link (https://8020.net/3030-s-black-fb-1.html) | 23
3 | 1 | Vertical Members (bottom/short) | 3030-S-Black | link (https://8020.net/3030-s-black-fb-1.html) | 13.4114
4 | 1 | Horizontal Members | 3030-S-Black | link (https://8020.net/3030-s-black-fb-1.html) | 69.6476

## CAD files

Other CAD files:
hardware/mechanical/GBW-300-2.DWG
hardware/mechanical/GBW-323.DWG
hardware/mechanical/GBW-300-1.DWG
hardware/mechanical/GBW-003.DWG
hardware/mechanical/GBW-300-3.DWG

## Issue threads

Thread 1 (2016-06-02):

Suggest hardware steps

alexgorbatchev, 2016-06-02:
Having amazing specs for hardware, it would be useful to have suggestions about what to do with me for software-only folks like myself. I would like to see:
1. Possible places, URLs or at least type of places that can manufacture this stuff
2. Approximate costs (obviously this would be locale specific, but any data is better than no data)
3. Assembly instructions or at least a video walk through of this wall internals

Thank you so much for your incredible efforts!

cjgammon, 2016-06-03:
+1
I would love to do something like this as a project but have no idea where to start with hardware. I'm worried I'd buy the wrong thing or be missing parts I didn't anticipate.

A shopping list of the bare necessities to get this working would be great (like do i need special LED's?).
Once I new I had exactly what I need I feel like maybe I could maybe research the assembly of it.
Although having a general step by step build instructions or even as mentioned a video would be phenomenal.

very cool idea.

Bre77, 2016-06-03:
Give it a few weeks and the likes of Adafruit will likely have hardware tutorials and kits up.

ZerofeniX, 2016-06-03:
For a short term answer, this stuff is *really* expensive. They included BOMs (Bill of Materials) for everything from the looks of it. The circuit board component BOMs all have part numbers, vendor part numbers, and they list VID which I'm guessing is short for Vendor ID, the one I looked at has a VID of "DK" which I am fairly certain is digikey. There are other electronics suppliers such as Arrow and Newark. All of these components are relatively cheap but you'd have to solder it all yourself or get someone to assemble the boards for you which is where it gets tricky.

PCBs (printed circuit boards) are expensive and most of the places that do PCBs are all about doing as many as possible. They typically make them in large batches and the surface area of the PCB plays a key roll in the cost. Anecdotally, I had 6 PCBs about the size of a sheet of a paper made and it cost $500, that doesn't include components which you would either have to source to a manufacturer in a package that their machines can use, or solder a few hundred components yourself per board without melting them or destroying your PCB.

Like @Bre77 said, your best bet is to hope that one of the hobbyist electronics sites like Adafruit or Sparkfun decide to sell some sort of assembled board or kit.

jarrydfillmore, 2016-06-03:
+1. I totally agree!

PatrickFranken, 2016-06-05:
This project has already been indexed by AISLER.

https://aisler.net/googlecreativelab/anypixel/display-r2
BOM price is about 219EUR for 439 parts, difficulty level is expert because of some parts which are hard to solder by hand.

Same applies to
https://aisler.net/googlecreativelab/anypixel/controller-r3
BOM price is about 87EUR for 154 parts.

Disclaimer: I'm one of the founders of AISLER.

PS: We'll provide the detailed description on how to solder it by hand soon.

sahunt, 2016-06-06:
+1. Would love to see a list of compatible microcontrollers. Hoping there's a STM32 controller (mentioned in readme) which would work.

awesomephant, 2016-06-06:
Correct me if I'm wrong, but the budgets on AISLER seem very far off. The arcade buttons alone are about $1 a piece (according to [the website listed in the BOM ](https://na.suzohapp.com/products/arcade_game_parts/58-0091-SH)), which works out to $5880 - even assuming you can get these cheaper in bulk, you're looking at thousands rather than hundreds of dollars.

PatrickFranken, 2016-06-06:
Our budgets only include the electric components (PCB + parts). If you are curious what the costs of the parts are have a look under https://aisler.net/googlecreativelab/anypixel/display-r2/bom and https://aisler.net/googlecreativelab/anypixel/controller-r3/bom
Wether you use the arcade buttons or anything else depends on your installation. AISLER delivers the DIY kit, the specific physical installation is up to you.

ryburke, 2016-06-07:
Thank you all so much for your interest and excitement for the AnyPixel.js project. You've surfaced some great questions  - with varying degrees of difficulty in answering.

Let me just say as a macro level point that we are aware that implementing AnyPixel.js in-full, at-scale is complex and not a day's work. Our hope in sharing every bit and bolt was to inspire and provide a reference from which ideas, parts, etc. could be cherry-picked from. For those who can do, we hope you do do. But at minimum, we hope you get excited about what's possible.

In AnyPixel.js' exploratory phase, we did create a form and interaction prototype (it does not run the software framework) - [seen here](http://googlecreativelab.github.io/anypixel/img/carousel_01.jpg). In the coming weeks, we will be adding documentation to outline that build process.

We are also looking at possibly developing a lighter version - perhaps a single board. This is time and resource dependent but it's definitely on the table. Even better, someone from this great community could take the reins!

jeremyabel, 2016-06-07:
We've been thinking about this a bit, and we have some ideas we'd like to share in an effort to spur some thinking in what might be a good direction.

We're imagining a combination of the control board and the 7x7 grid board. One board with both the control chip, network hardware, and the LED driver chips. But instead of putting the LEDs directly on the board, it would have a large array of output pins so you could plug in / solder up your own LEDs.

Some additional thoughts:

* Can the LED driver chip be used to drive non-LED things? It's just PWM output after all.

* Is there a more generic PWM driver chip that has a similar comms protocol that might be better suited to driving all sorts of outputs, not just LEDs?

ryburke, 2017-01-12:
This morning we released a simple starter example with AnyPixel running on a first gen Raspberry Pi controlling a single neopixel button. Check it out at [/rpi-example](https://github.com/googlecreativelab/anypixel/tree/master/rpi-example).

Closed 2017-01-12.

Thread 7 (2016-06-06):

Specify LED compatibility and grid definition

sahunt, 2016-06-06:
Loving this project and am dying to try it out. Great work!

There are two major areas which would greatly help in understanding how to set up this project:

1) What type of LEDs are supported? I'm assuming WS2812 as those are fairly common, though without this specified I'm not sure what LEDs anypixel.js can talk to.

2) How is the LED grid defined, or can it even be defined? There's many ways to set up the LEDs -- i.e in linear or nonlinear strips, individual LEDs connected in columns or rows... knowing how to specify this is essential for setting up the pixel grid.

Bre77, 2016-06-07:
Sorry for the less than authoritative response I am going to provide you.

I believe they are using standard RGB LEDs controlled with 12bit PWM, and using a fancy method to scale the 8bit source to 12bit range. Chips like the WS2812 do this magic for you and can be chained together. They are two completely different hardware architectures.

I do however plan to adapt anypixel to a typical Arduino/WS2812 setup in the near future, and will certainly contribute that code if suitable.

I will also be exploring the second part of your question in my work, but don't have any answers yet, but suspect it will require custom code to transform the canvas output to your non-linear display.

sahunt, 2016-06-07:
I'd be surprised if they're standard RGB LEDs -- based on the demos they seem to be some type of addressable. "Standard arcade button with LEDs" isn't much to go on so really could be anything.

Would love to see how this would work with Arduino! Will keep an eye out for it.

Bre77, 2016-06-07:
Well take a look at the schematics. Each light is connected up to three PWM outputs. They do have a degree of addressability, but using larger controllers which are responsible for what seems to be 5 lights per PWM module and two PWM modules.

https://github.com/googlecreativelab/anypixel/blob/master/hardware/pcb/display/display-r2-schematic.pdf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

aabowen, 2016-06-07:
How/where do I get the code from the website header to re-use? Is that
acceptable?

I absolutely love the header and want to customize it for a website.

Thanks!

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

--

*Alexandra Bowen *
w: *http://alexandrabowen.weebly.com/ <http://alexandrabowen.weebly.com/>*
May This Message Find You In Health And Happiness
[image: Facebook] <https://www.facebook.com/alexandra.a.brower> [image:
Twitter] <https://twitter.com/hawaiiaspenalex> [image: LinkedIn]
<http://www.linkedin.com/in/alexandrabrower/>

To weave together the landscapes of man and nature for the benefit of both

jeremyabel, 2016-06-07:
@aabowen please file a separate issue for this and I'd be happy to help!

ryburke, 2016-06-08:
Overall, our documentation is installation specific. The parts and methodologies employed were what we found to work. So unfortunately, we cannot speak to compatibility with other LEDs or controllers.

The LEDs and controllers used in the installation are documented in the BOM.

The buttonwall is numbered from top left to bottom right. In the installation, the LED grid is defined by the PCBs as documented in / pcb.

Also, bre77 - keep up the great work!

jeremyabel, 2016-06-08:
From an engineering standpoint, really any LED should work well enough. It might be worth checking the datasheet for the [TLC59401](http://www.ti.com/lit/ds/symlink/tlc59401.pdf) to see what would work best, as we can't speak to any other specific type of LED beyond the ones we used in the installation.

ARKopp, 2016-09-14:
Hi, did anybody did the work already to do this with an arduino or pi? Would love to do this but without making all these pcbs. I would use some 12min WS2801 like this https://learn.adafruit.com/12mm-led-pixels/overview

ARKopp, 2016-09-14:
Also I did not get how the button press works. Normally there is like a small swith on the bottom of these Buttons. How do you manage that?

ryburke, 2017-01-12:
@ARKopp This morning we released a simple starter example with AnyPixel running on a first gen Raspberry Pi controlling a single neopixel button. Check it out at [/rpi-example](https://github.com/googlecreativelab/anypixel/tree/master/rpi-example).

haaslukas, 2019-06-14:
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

@Bre77 did you try any sort of Arduino/WS2812 setup so far? I'm starting to think about a simple ESP32 implementation along with the FastLED library to control 256 buttons (shift register button matrix setup) and WS2812 LEDs. Of course it would be nice, if you already have some code snippets or at least a few thoughts about possible pitfalls. I guess the hardest part would be to adapt the firmware in order to talk to the ESP32.

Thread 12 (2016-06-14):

Could I use Espruino to build a prototype?

FernandoNaz, 2016-06-14:
Hello!
Firstly, I must say, you folks are amazing! This is an incredible technology you developed, and the best part, is that is an open library! Really, you guys are amazing.
My friends and I are little hackers when come to new technology of this type and we wanted to build an inexpensive prototype for fun.
We were thinking in buying an Espruino Board with and RGB-123 LED Matrix to prototype. You probably know what an Espruino Board is, but just in case, I will put the site (http://www.espruino.com/EspruinoBoard) and the specifications here:
- Less than half the size of a business card ( 54mm x 41mm )
- STM32F103RCT6 32-bit 72MHz ARM Cortex M3 CPU
- 256KB of Flash memory, 48KB of RAM
- Micro USB connector
- Input Voltage Range of 3.6v to 15v
- Battery connector (JST PHR-2 2 Pin)
- Built-in SD card connector
- Red, Green and Blue LEDs
- Pads to allow HC-05 Bluetooth modules to be added
- 0.1" Pin spacing
- 44 GPIO Pins, capable of: 26 PWM Pins, 16 ADC Pins, 3 USARTs, 2 SPI, 2 I2C and 2 DACs
- Prototype area which can be used in many different configurations, for example: Servo Headers, Up to - - 14x 500mA outputs, 2x .NET Gadgeteer connectors, or NRF24L01+ wireless transceiver modules
- Rev 1v4: CE and RoHS certification
We were thinking about the Espruino because it uses a STM32F103RCT6 microcontroller - if I am not mistaken, it is the same kind you use - and it supports JavaScript, besides being relative low-cost and small.
What you think about using the Espruino for this application? Do you have any recommendations? Does the application have any different specification if using the Espruino?

Thank you for all your time and knowledge,
You are truly incredible,
Fernando Nazário and Friends

P.S: sorry if I made any english mistakes. I am from Brazil and probably there will be few (euphemism) errors here.

ryburke, 2016-06-16:
Hi @FernandoNaz - thank you for the kind words! We love that you're excited about AnyPixel.js.

To answer your question...
You'll have to add an Ethernet (or WiFi) interface to accept packets from the Chrome app. Once you can read and write packets on your micro controller it is just a matter of controlling your LEDs (or other display mechanism) and reading your buttons. The packet structure you need to work with is outlined in the protocol document of the firmware folder.

We used a similar set of micro controllers. The Espruino has an STM32F103 and we used an STM32F030 on the display board (5 of them actually!) to handle the LED control and button monitoring. You'll need to write your own code to handle the display and buttons since the hardware is different.

Our controller board is based on the STM32F407 as it handles the network layers and TCP/IP packets from the app. For the data link layer we used a KSZ8863MLL which is an ethernet transceiver from Microchip with an integrated PHY (some hardware options for the Espruino are listed here: http://www.espruino.com/Internet, and some of these handle the network layer for you too!). Again you'll need to write the code to interface these parts since the hardware is all different.

In addition to all of this you'll need a machine running the server and Chrome app too, you can't do this on an Espruino.

There's definitely some work involved in doing all of that, but it sounds like a fun project and the Espruino looks like a prototype platform that you could use to do it. Let us know how it goes!

Closed 2016-07-08.

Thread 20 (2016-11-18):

Compile questions

Rwellchan, 2016-11-18:
Regarding the controller firmware, we encountered a problem when compiling "project_config.c"  mentioning the macro defenition #ifdef REV1 has to be defined but couldn't seen from any of the files. According to the REV number on the PCB board is 3 rather than 1. Is this a versioning problem or can anyone help? Thanks. The files are downloaded offline directly from the repository. Thanks.
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

ajiblock, 2016-11-29:
This is a structure we used to allow for changes in pinouts or connected components as a PCB is revised, but it isn't really necessary for this project, so it didn't get updated with different rev numbers.

You can just add the following:
-DREV1 in the compiler flags for your project.
-You must be using a different build environment since the .ebp project file does have a -DREV1 compiler flag in it.

Closed 2017-01-12.

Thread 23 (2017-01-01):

Simple diet-project to get started

tshamz, 2017-01-01:
If I'm having confusion and pretty high level questions like:

- what's a PWM module?
- as the physical size of the project grows, which parts am I gonna need to keep buying more of?
- widget X can do ABC, but widget Y can do ABC _and_ XYZ... I wonder if I should buy widget Y?

are these, or questions like them, just the beginning and it's only gonna get worse moving forward? My guess is that a lot of web developers will see this and say to themselves, "cool. definitely want to build that." But that thought will then quickly be followed by another of, "shit. what's a PCB? is this going to cost me a small fortune? will I need to buy tools for this? i hope i don't electrocute myself..."

I think the idea mentioned at the end of [this comment](https://github.com/googlecreativelab/anypixel/issues/1#issuecomment-224397613) might be something that would be helpful at providing people with no hardware experience a context to learn in and enough basic knowledge that they could tool around with that and then afterwards have enough confidence to go off and figure out the rest on their own.

ryburke, 2017-01-03:
The version that we open sourced is a commercial build for the Google lobby. As a web developer, these hardware questions are totally fair. And you're right, you will likely have more as you work through the project.

We are currently developing a simplified version running off a Raspberry Pi. We have a lot of other projects right now, but we hope to have this complete in the next month or two.

tshamz, 2017-01-11:
Awesome, thanks for the response. I'll be tracking closely and waiting patiently for the simplified version. 🙌🏻

ryburke, 2017-01-11:
@tshamz We'll be posting an example tomorrow morning with AnyPixel running off a Raspberry Pi controlling a single button.

Closed 2017-01-11.

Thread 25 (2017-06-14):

Emulator Not Working

kennyor, 2017-06-14:
While those backend application installed, any reasons that only ChromeBridge working fine but Emulator without showing the blue box on the top left corner?
Anyone got an idea?

ajiblock, 2017-06-14:
Thanks for posting this. The emulator seems to be working for us. Can you describe your issue in more detail and we can see if we can help.

kennyor, 2017-06-16:
Basically, I am starting to try the instruction of project at the point: "Starter Example: AnyPixel with Raspberry Pi", since I have only limited hardware material on hands, I am wondering how far I could complete this creative project.

Hardware:
I am using Raspberry Pi 2Model B without Neopixel, therefore I made a console log to simulate the led response if button press or the signal from chromebridge.

Running the app from host computer:
After putting "getting-started-rpi"to right place and run build, the chrome extension "emulator" was also installed and launched. Here the emulator shows all units are in black. After I launch ChromeBridge, I got exact result as the screen capture provided on "rpi-example/chromebridge", but emulator still black.

So my question is, in which stage I should be able to trigger the units turning blue from black?

Thanks for your time to answer me!

nick-jonas, 2017-06-16:
Hi @kennyor!

I just set it up again from scratch and I was able to recreate it so I think I know where you're reaching a snag.  You are probably getting an error in your ChromeBridge from the app running if you open up your inspector.  First, you need to make sure you followed these instructions in the README:

Install Sample App Copy and paste frontend/examples/getting-started-rpi into appserver/public/apps/ and then:
```
cd appserver/public/apps/getting-started-rpi
npm install
npm run build
```

And then, (and this was a mistake on our part and now is fixed), you actually need to do one extra step when setting up your app server, which is to manually create a ```public/js``` folder.  So I would kill the app server process (```forever stop <pid>```) and follow these steps again:

### Install & Run App Server
```
cd /backend/appserver
mkdir -p public/js
npm install
npm install anypixel
npm start
```

After you do that, and you have the udp-manager and appserver running in the background (and refreshed), you should see the blinking blue square in your emulator.  Let me know if that works!

kennyor, 2017-06-20:
Hi @nick-jonas!

I really appreciate this opportunity to get help from you! Everything working well after create the folder, learn a lot;)

Closed 2017-06-20.

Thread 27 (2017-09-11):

Manufacturing these boards - PCB / Firmware Programming questions

HedronUser, 2017-09-11:
I'm looking at quotes for producing these boards on a small scale.

1. Is there a solder-type requirement for making these boards or do the components care?

It's unclear to me how to "set the correct memory layout for each device in the linker script.

2. Where is the referenced linker script and do I adjust it before uploading firmware for each board and MCU (controller and display)? Do I need to send this instruction to the PCB manufacturer, will they understand what that means?
Alternatively, Are there any instructions needed for properly uploading the provided firmware to the boards or do I just compile and upload everything as a single hex file as is?

3. What is the SMT oven profile for these boards?

4. Is conformal coating needed?

HedronUser, 2017-09-13:
I received a bit more info from the manufacturer on these  questions.

1. ROHS - No Clean Pb Free solder is standard

3. Oven profile is for heat-sensitive components. Im wondering are there sensitive components on these boards we need to be aware of?

4. Conformal coating is really for outdoor / high-moisture environments. So its not necessary.

Lingering questions about testing and setting up system:

**What is the procedure for testing operation of these boards?**

There is a protocols section for testing the PCBs over a 16-pin header, https://github.com/googlecreativelab/anypixel/blob/master/firmware/PROTOCOLS.md , but it is missing the descriptions of several things (dot correction, rgb raw, calibration lookup table request, etc) . It is unclear how one should compile a header/test sequence. A simple diagram showing the google wall with referenced variables used would help out a lot.
Some step by step instructions with example of stacking the bytes together would be awesome.

The unit address section has (20 + 10* row + column) How are these referenced on existing google wall?

What is the sequence number?

What is the port number?

What is the proper format of ip address?
How does one set the memory layout of each device?

Where is the referenced linker script for setting memory layout?

Do I need to worry about setting the memory layout in the firmware or can it be done after the upload?

ryburke, 2017-09-14:
Hey thanks for your interest in AnyPixel and for your super pointed questions. We're running around right now on a couple other projects but we'll get back to you soon. Thanks for your patience.

ddresch, 2018-11-13:
@HedronUser did you make any progress with your project or did you stop it? Would be awesome to hear any feedback!

HedronUser, 2018-11-13:
Hey Dirk,

Our client went another direction so we stopped moving forward with it. It was unfortunate that the BOM for the hardware was so difficult to track down and that the hardware design is so expensive and complicated for anyone, even a professional electronics engineer, to replicate. For example, the RGB LEDs specified are out of production and without a direct replacement available on the market a redesign of the board would be necessary to make the design work. Why didn’t google go the route of the on-die addressable LED like the ws2812 or similar with dedicated data and power injection circuits?  Developing that software stack would have been more applicable IMO. On the other hand, I understand wanting to use dedicated processing at the submatrix array level but it is a lot of extra chip programming, extra expense, and a lot of potential debug.

Thanks for reaching out,
-Jesse

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

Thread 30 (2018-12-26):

Clear canvas

CodingCarlos, 2018-12-26:
Hi!

I'm playing with the previewer app to see what can I build, and I've got problems when I try to clear some section.

Here is the simplest version of the code I'm trying to get working:

```js
var anypixel = require('anypixel');
var ctx = anypixel.canvas.getContext2D();

/**
 * On load, draw a square
 */
document.addEventListener('DOMContentLoaded', function() {
  ctx.fillStyle = '#F00';
  ctx.fillRect(0, 0, 10, 10); // This is happening as expected
});

/**
 * On button down, clear the square
 */
document.addEventListener('onButtonDown', function(event) {
  ctx.clearRect(0, 0, 10, 10); // This is not working
});
```

I can only see it working (in the preview app) when I enable the color correction mode, but without it, the square still drown.

I think I'm not doing something in the right way, but I couldn't be able to find any documentation.

Thanks!

____
_Tested on Ubuntu Linux 16.04, with Chrome 71, Chromium 71 and Firefox 64_

ryburke, 2019-01-07:
Hi Carlos, what color are you drawing the square?

CodingCarlos, 2019-01-08:
In this example, red:
```
ctx.fillStyle = '#F00';
```
But I've tried with a lot of colors, and no one is cleared.

CodingCarlos, 2019-03-29:
After some testing, I've discovered that if I paint the square in black (pure black, `#000`), the pixel seems to be off. So, I am able to clear all the canvas by painting it black:

```javascript
const anypixel = require('anypixel');
const ctx = anypixel.canvas.getContext2D();
const INC_W = anypixel.config.width;
const INC_H = anypixel.config.height;

function clear() {
  ctx.fillStyle = '#000';
  ctx.fillRect(0, 0, INC_W, INC_H);
}

clear();
```

As feedback, it's a little bit weird for me to clear a pixel by painting it black, instead of using the canvas `clearRect` function. Anyway, It is working, so I'm closing the issue.

Thanks, @ryburke for the color tip :wink:

ryburke, 2019-03-29:
@CodingCarlos the previewer is meant to be a representation of the physical installation that is built with LEDs. LEDs can't produce black light so black is equivalent to LED off.

Keep this mental model in mind – that the previewer represents a physical LED installation – as you continue to develop. All things here are in service of that.

:)

Closed 2019-03-29.

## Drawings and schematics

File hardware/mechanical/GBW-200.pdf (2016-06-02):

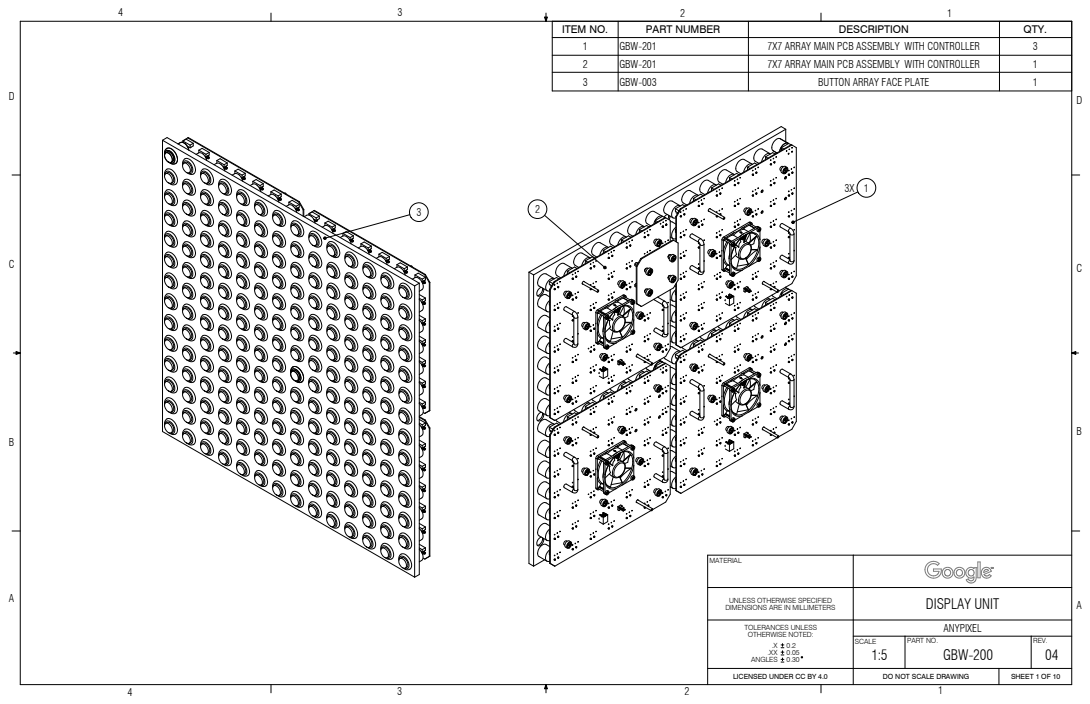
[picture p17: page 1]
ITEM NO.; PART NUMBER; DESCRIPTION; QTY.; GBW-201; 7X7 ARRAY MAIN PCB ASSEMBLY WITH CONTROLLER; GBW-003; BUTTON ARRAY FACE PLATE; PART NO.; REV.; MATERIAL; DIMENSIONS ARE IN MILLIMETERS

UNLESS OTHERWISE SPECIFIED | DISPLAY UNIT ANYPIXEL

TOLERANCES UNLESS OTHERWISE NOTED: .X .XX 0.05 ANGLES 0.30 | SCALE 0.2

1:5 | GBW-200 | 04

LICENSED UNDER CC BY 4.0 | DO NOT SCALE DRAWING | SHEET 1 OF 10

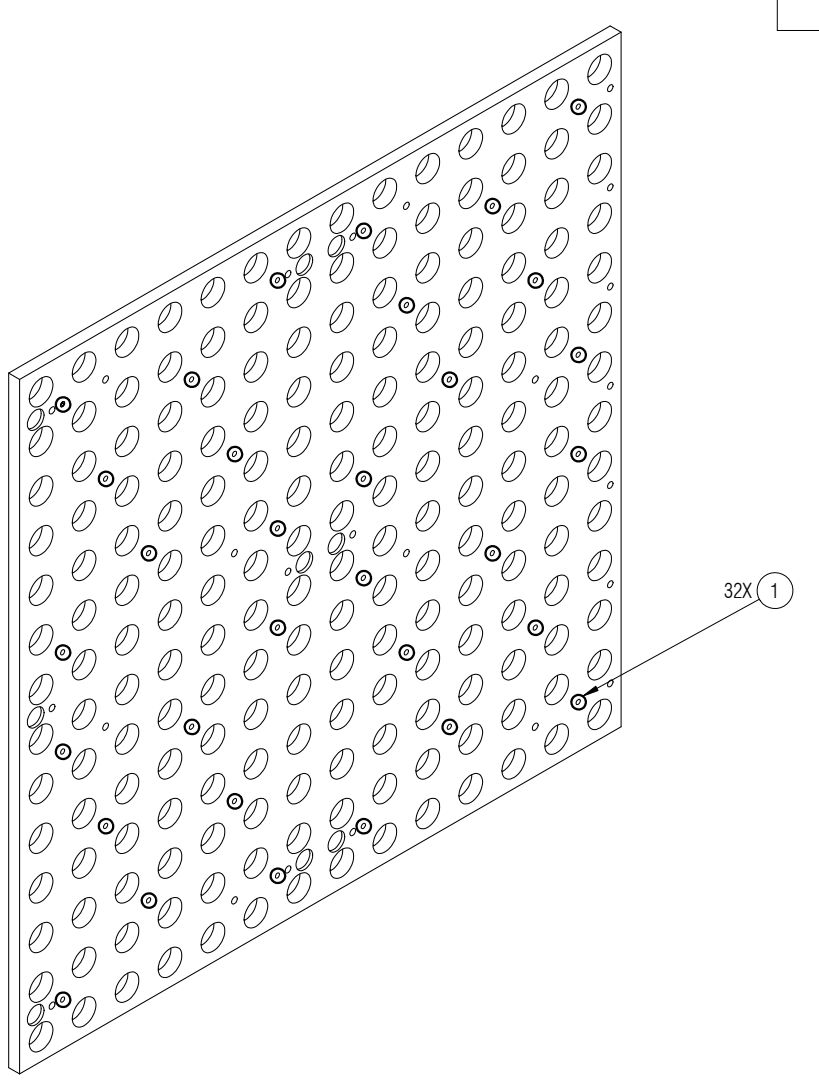
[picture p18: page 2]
PART NO.; REV.; MATERIAL; DIMENSIONS ARE IN MILLIMETERS; #6-32 THREADED INSERT

BUTTON ARRAY FACE PLATE
1:4 | GBW-003 | 04

UNLESS OTHERWISE SPECIFIED | ASSEMBLY PART 1 OF 4 ANYPIXEL
TOLERANCES UNLESS OTHERWISE NOTED: .X .XX 0.05 | SCALE 0.2

DO NOT SCALE DRAWING | SHEET 2 OF 10

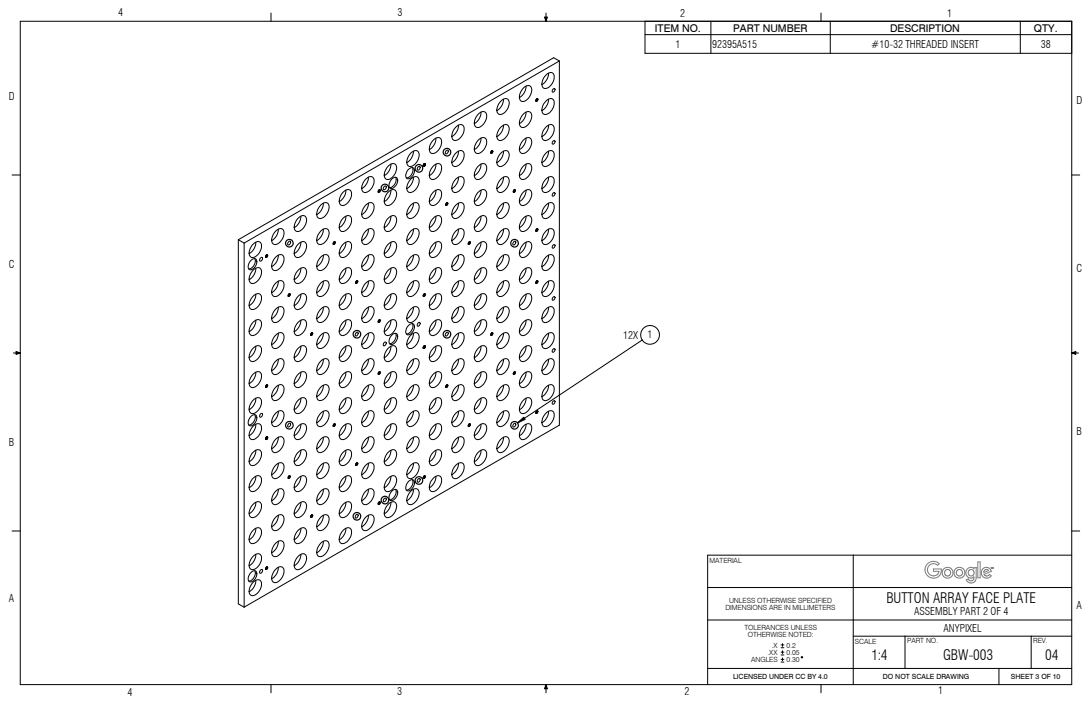
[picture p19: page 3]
PART NO.; REV.; MATERIAL; DIMENSIONS ARE IN MILLIMETERS; #10-32 THREADED INSERT

BUTTON ARRAY FACE PLATE
1:4 | GBW-003 | 04

UNLESS OTHERWISE SPECIFIED | ASSEMBLY PART 2 OF 4 ANYPIXEL
TOLERANCES UNLESS OTHERWISE NOTED: .X .XX 0.05 | SCALE 0.2

DO NOT SCALE DRAWING | SHEET 3 OF 10

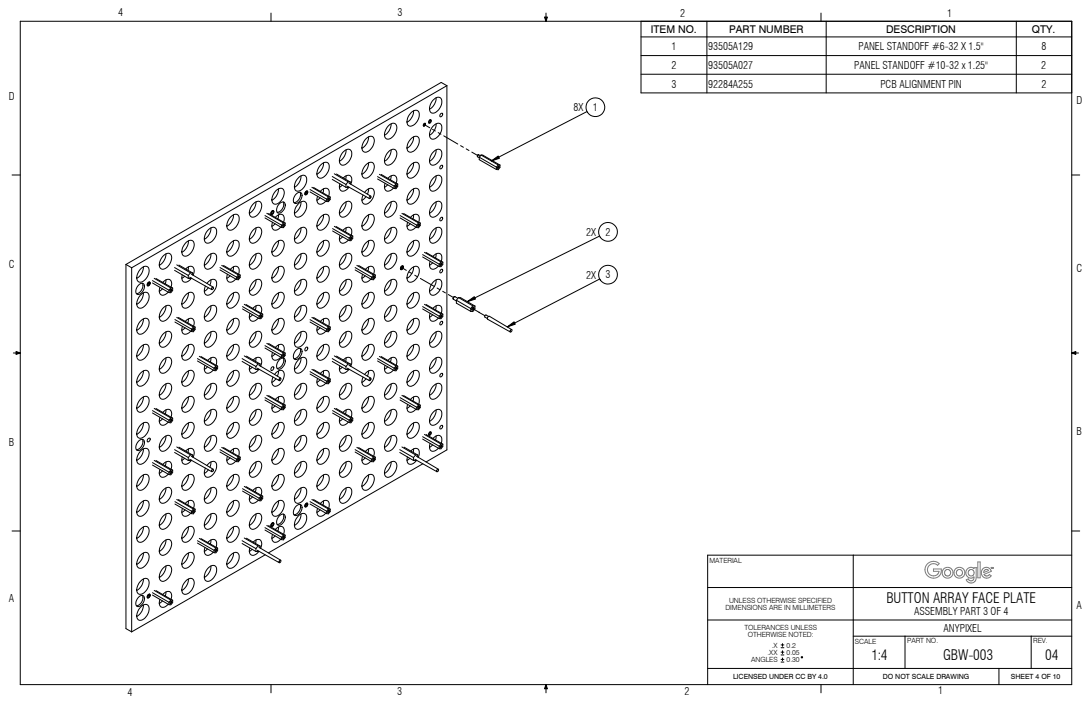
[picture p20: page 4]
PART NO.; REV.; MATERIAL; DIMENSIONS ARE IN MILLIMETERS

1 | 93505A129 | PANEL STANDOFF #6-32 X 1.5" | 8
2 | 93505A027 | PANEL STANDOFF #10-32 x 1.25" | 2
3 | 92284A255 | PCB ALIGNMENT PIN | 2

BUTTON ARRAY FACE PLATE
1:4 | GBW-003 | 04

UNLESS OTHERWISE SPECIFIED | ASSEMBLY PART 3 OF 4 ANYPIXEL
TOLERANCES UNLESS OTHERWISE NOTED: .X .XX 0.05 | SCALE 0.2

DO NOT SCALE DRAWING | SHEET 4 OF 10

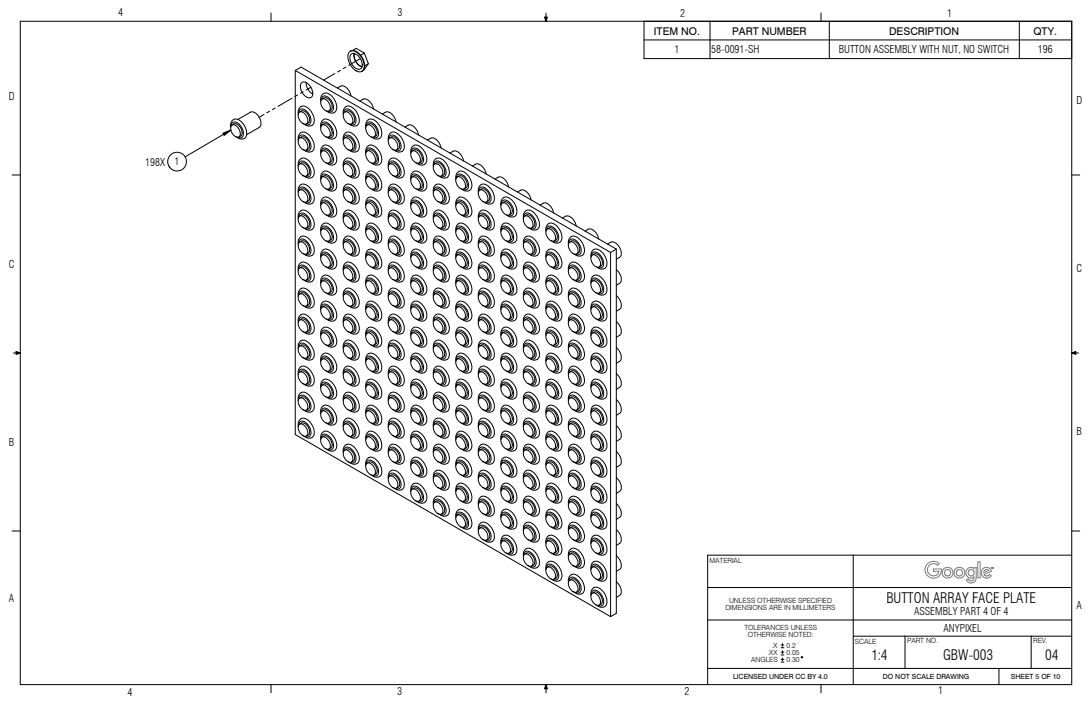
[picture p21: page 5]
BUTTON ASSEMBLY WITH NUT, NO SWITCH; PART NO.; REV.; MATERIAL; DIMENSIONS ARE IN MILLIMETERS

BUTTON ARRAY FACE PLATE
1:4 | GBW-003 | 04

UNLESS OTHERWISE SPECIFIED | ASSEMBLY PART 4 OF 4 ANYPIXEL
TOLERANCES UNLESS OTHERWISE NOTED: .X .XX 0.05 | SCALE 0.2

DO NOT SCALE DRAWING | SHEET 5 OF 10

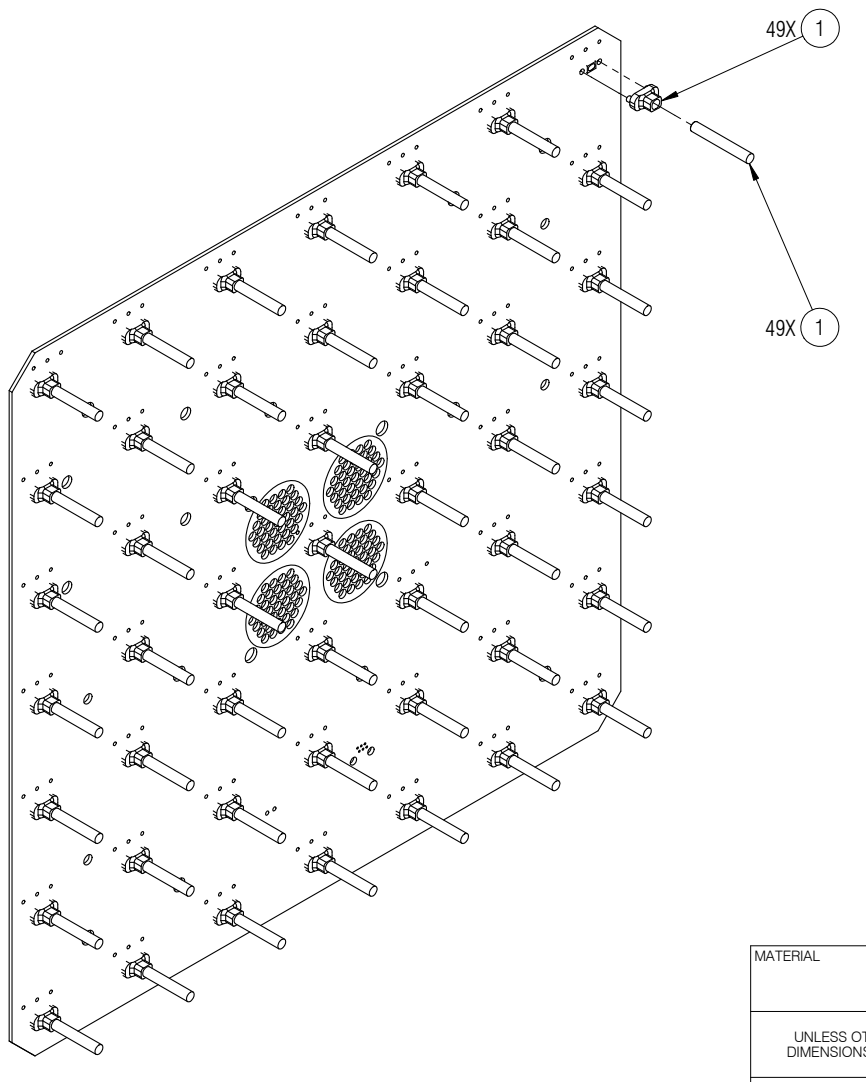
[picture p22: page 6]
PART NO.; REV.; MATERIAL; DIMENSIONS ARE IN MILLIMETERS; 5MM LIGHT PIPE AND HOLDER

UNLESS OTHERWISE SPECIFIED | 7X7 ARRAY MAIN PCB ASSEMBLY ANYPIXEL

TOLERANCES UNLESS OTHERWISE NOTED: .X .XX 0.05 | SCALE 0.2

1:2 | GBW-001 | 04

DO NOT SCALE DRAWING | SHEET 6 OF 10

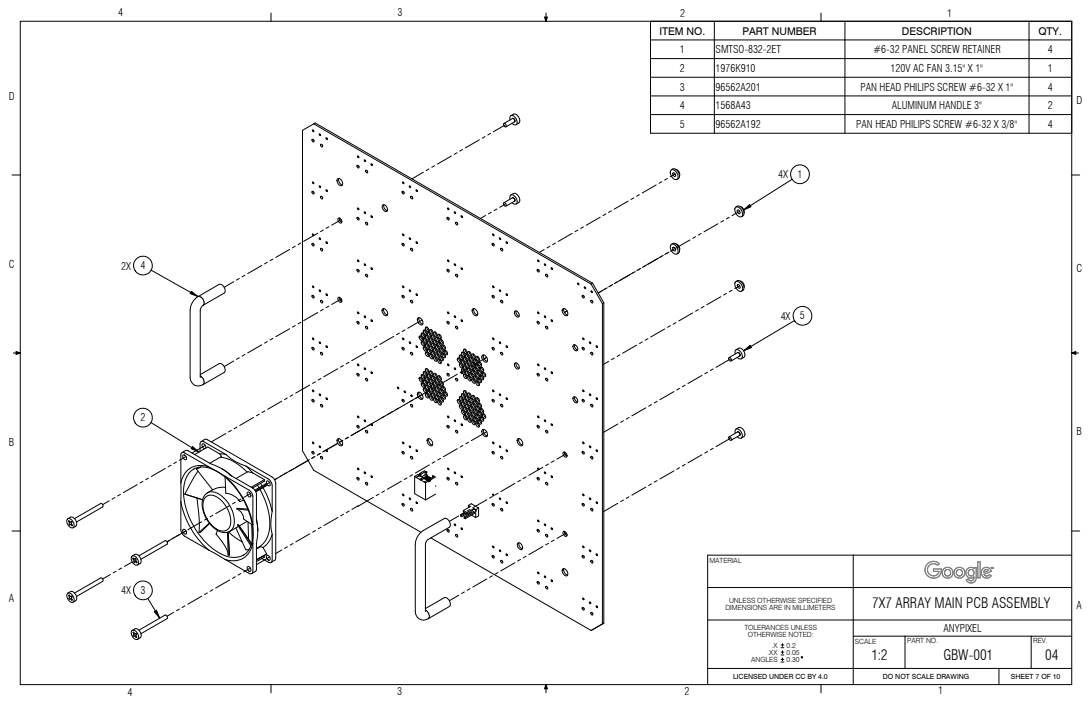
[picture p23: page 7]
PART NO.; REV.; MATERIAL; DIMENSIONS ARE IN MILLIMETERS

1 | SMTSO-832-2ET | #6-32 PANEL SCREW RETAINER | 4
2 | 1976K910 | 120V AC FAN 3.15" X 1" | 1
3 | 96562A201 | PAN HEAD PHILIPS SCREW #6-32 X 1" | 4
4 | 1568A43 | ALUMINUM HANDLE 3" | 2
5 | 96562A192 | PAN HEAD PHILIPS SCREW #6-32 X 3/8" | 4

UNLESS OTHERWISE SPECIFIED | 7X7 ARRAY MAIN PCB ASSEMBLY ANYPIXEL

TOLERANCES UNLESS OTHERWISE NOTED: .X .XX 0.05 | SCALE 0.2

1:2 | GBW-001 | 04

DO NOT SCALE DRAWING | SHEET 7 OF 10

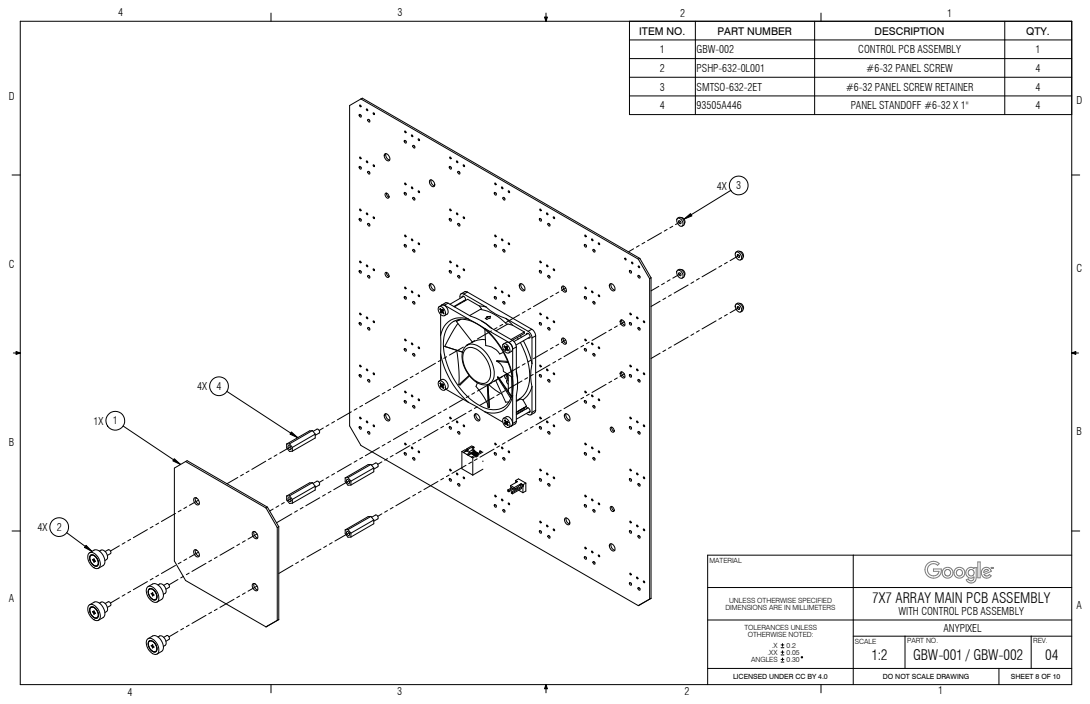
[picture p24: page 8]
PART NO.; REV.; MATERIAL; DIMENSIONS ARE IN MILLIMETERS

1 | GBW-002 | CONTROL PCB ASSEMBLY | 1
2 | PSHP-632-0L001 | #6-32 PANEL SCREW | 4
3 | SMTSO-632-2ET | #6-32 PANEL SCREW RETAINER | 4
4 | 93505A446 | PANEL STANDOFF #6-32 X 1" | 4

7X7 ARRAY MAIN PCB ASSEMBLY
1:2 | GBW-001 / GBW-002 | 04

UNLESS OTHERWISE SPECIFIED | WITH CONTROL PCB ASSEMBLY ANYPIXEL
TOLERANCES UNLESS OTHERWISE NOTED: .X .XX 0.05 | SCALE 0.2

DO NOT SCALE DRAWING | SHEET 8 OF 10

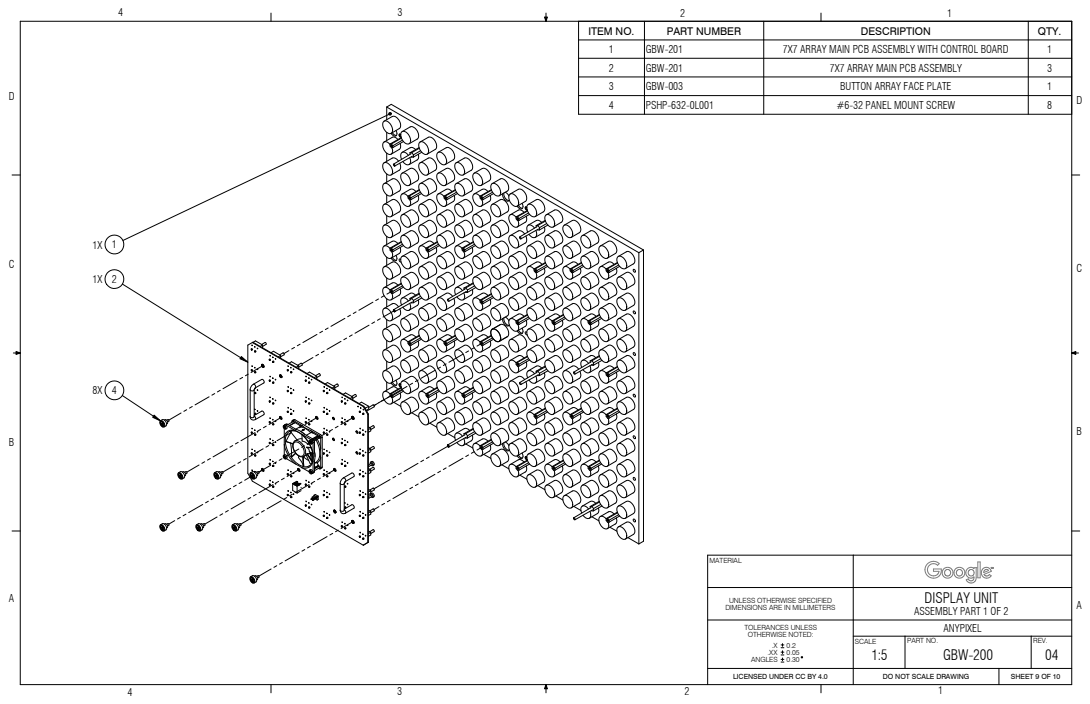
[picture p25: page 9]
PART NO.; REV.; MATERIAL; DIMENSIONS ARE IN MILLIMETERS

1 | GBW-201 | 7X7 ARRAY MAIN PCB ASSEMBLY WITH CONTROL BOARD | 1
2 | GBW-201 | 7X7 ARRAY MAIN PCB ASSEMBLY | 3
3 | GBW-003 | BUTTON ARRAY FACE PLATE | 1
4 | PSHP-632-0L001 | #6-32 PANEL MOUNT SCREW | 8

DISPLAY UNIT
1:5 | GBW-200 | 04

UNLESS OTHERWISE SPECIFIED | ASSEMBLY PART 1 OF 2 ANYPIXEL
TOLERANCES UNLESS OTHERWISE NOTED: .X .XX 0.05 | SCALE 0.2

DO NOT SCALE DRAWING | SHEET 9 OF 10

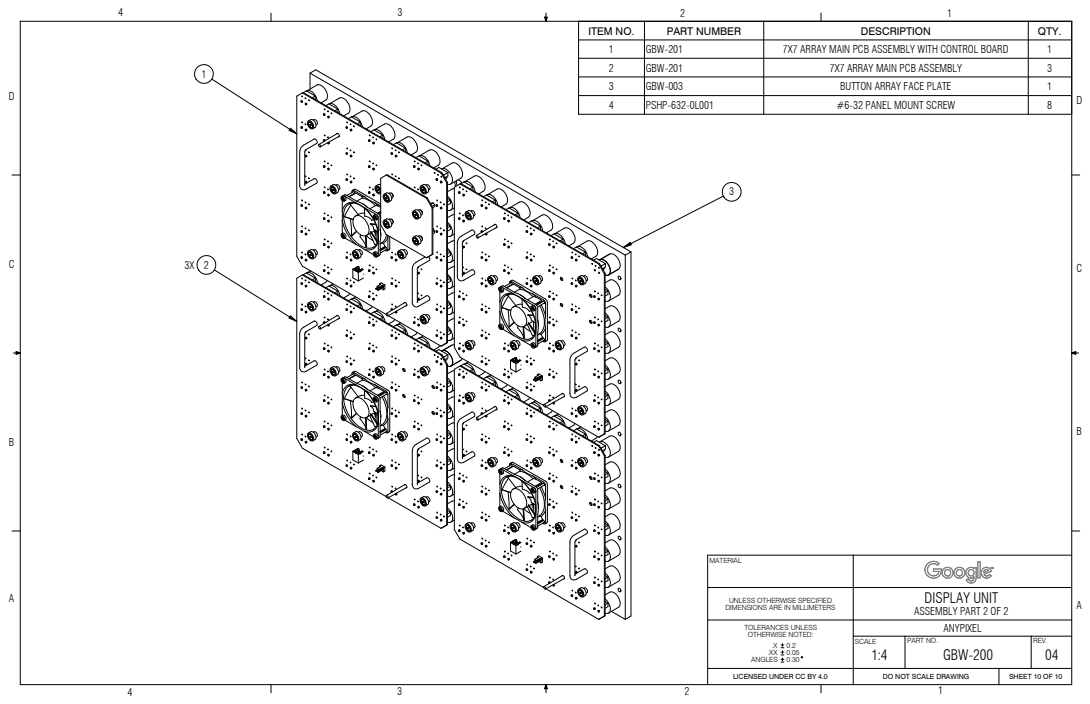
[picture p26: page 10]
PART NO.; REV.; MATERIAL; DIMENSIONS ARE IN MILLIMETERS

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

DISPLAY UNIT
1:4 | GBW-200 | 04

UNLESS OTHERWISE SPECIFIED | ASSEMBLY PART 2 OF 2 ANYPIXEL
TOLERANCES UNLESS OTHERWISE NOTED: .X .XX 0.05 | SCALE 0.2

DO NOT SCALE DRAWING | SHEET 10 OF 10

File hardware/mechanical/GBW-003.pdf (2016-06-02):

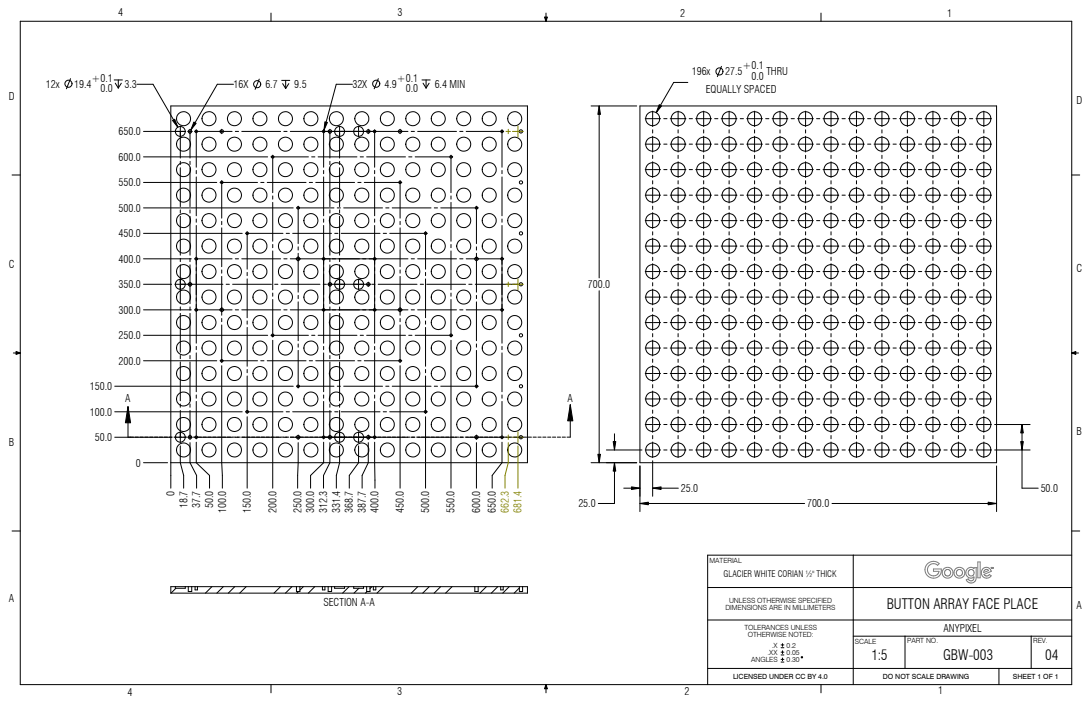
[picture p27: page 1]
196x 27.5+0.1 0.0 THRU EQUALLY SPACED; SECTION A-A; PART NO.; REV.; MATERIAL; 0.30 GBW-003; SCALE; 0.0 6.4 MIN

GLACIER WHITE CORIAN ½" THICK
UNLESS OTHERWISE SPECIFIED DIMENSIONS ARE IN MILLIMETERS | BUTTON ARRAY FACE PLACE ANYPIXEL

TOLERANCES UNLESS OTHERWISE NOTED: .X 0.2 .XX 0.05 ANGLES

LICENSED UNDER CC BY 4.0 | DO NOT SCALE DRAWING | SHEET 1 OF 1

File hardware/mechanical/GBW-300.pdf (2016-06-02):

D
D

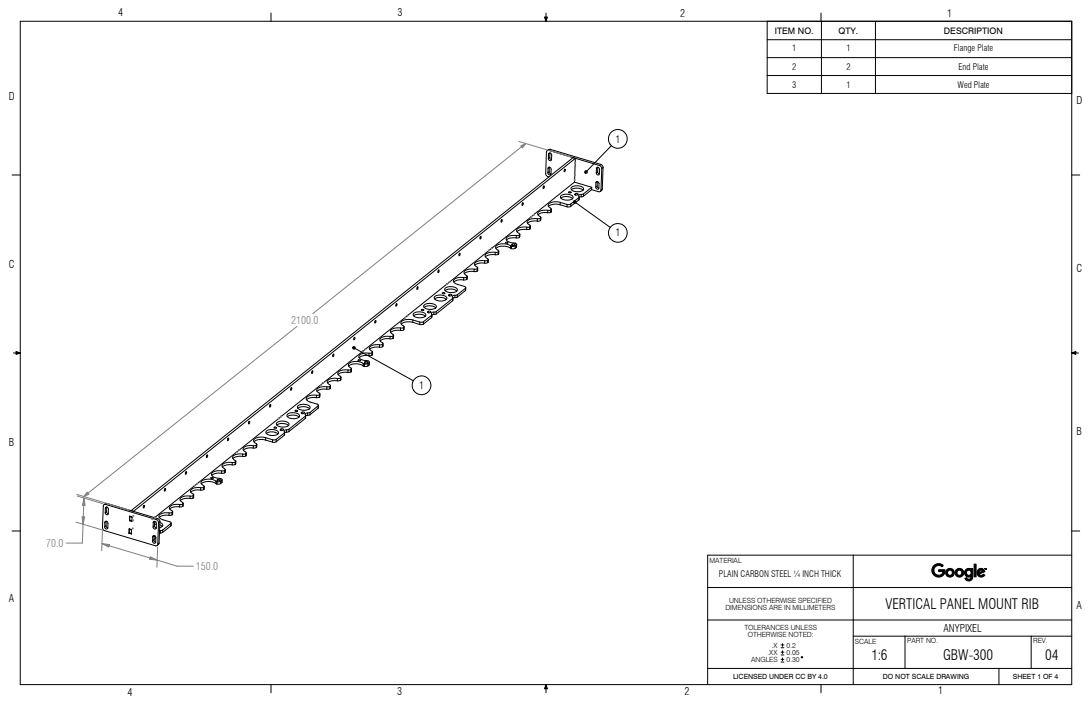
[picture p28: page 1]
PART NO.; REV.; MATERIAL; DIMENSIONS ARE IN MILLIMETERS

ITEM NO. | QTY. | DESCRIPTION
1 | 1 | Flange Plate
2 | 2 | End Plate
3 | 1 | Wed Plate

PLAIN CARBON STEEL ¼ INCH THICK
UNLESS OTHERWISE SPECIFIED | VERTICAL PANEL MOUNT RIB ANYPIXEL

TOLERANCES UNLESS OTHERWISE NOTED: .X .XX 0.05 ANGLES 0.30 | SCALE 0.2

1:6 | GBW-300 | 04

LICENSED UNDER CC BY 4.0 | DO NOT SCALE DRAWING | SHEET 1 OF 4

2100.0

100.0

R6.35 84x 30.0 EQ SPACING; DETAIL SCALE 2 : 3; PART NO.; REV.; MATERIAL; DIMENSIONS ARE IN MILLIMETERS

PLAIN CARBON STEEL ¼ INCH THICK | VERTICAL PANEL MOUNT RIB
UNLESS OTHERWISE SPECIFIED | FLANGE PLATE ANYPIXEL
TOLERANCES UNLESS OTHERWISE NOTED: .X .XX 0.05 | SCALE 0.2

1:6 | GBW-300-1 | 04

DO NOT SCALE DRAWING | SHEET 2 OF 4

4x R4.216 | 6.55

12.20 4x R6.35

PART NO.; REV.; MATERIAL; DIMENSIONS ARE IN MILLIMETERS

PLAIN CARBON STEEL ¼ INCH THICK | VERTICAL PANEL MOUNT RIB
UNLESS OTHERWISE SPECIFIED | END PLATE ANYPIXEL
TOLERANCES UNLESS OTHERWISE NOTED: .X .XX 0.05 | SCALE 0.2

3:2 | GBW-300-2 | 04

DO NOT SCALE DRAWING | SHEET 3 OF 4

D
D

PART NO.; REV.; MATERIAL; DIMENSIONS ARE IN MILLIMETERS; DETAIL SCALE 2 : 3; 14x DETAIL A SCALE 3 : 1

PLAIN CARBON STEEL ¼ INCH THICK | VERTICAL PANEL MOUNT RIB
UNLESS OTHERWISE SPECIFIED | WED PLATE ANYPIXEL
TOLERANCES UNLESS OTHERWISE NOTED: .X .XX 0.05 | SCALE 0.2

1:6 | GBW-300-3 | 04

DO NOT SCALE DRAWING | SHEET 4 OF 4

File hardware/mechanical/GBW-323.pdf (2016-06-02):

# NOTE THAT THIS DRAWING IS IN INCHES

D

PART NO.; REV.; MATERIAL; 0.30 GBW-323; SCALE; 4x DETAIL A SCALE 1 : 2; 45.00deg 5X 0.26in THRU ALL

PLAIN CARBON STEEL INCH THICK ⅛
UNLESS OTHERWISE SPECIFIED DIMENSIONS ARE IN INCHES | POWER UNIT MOUNTING PLATE ANYPIXEL

TOLERANCES UNLESS OTHERWISE NOTED: .X 0.2 .XX 0.05 ANGLES

LICENSED UNDER CC BY 4.0 | DO NOT SCALE DRAWING | SHEET 1 OF 1

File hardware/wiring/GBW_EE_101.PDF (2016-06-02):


Line I t e m | D e scriptio n | Manufactur e r | Par t Numbe r | Qt y
1 23 | Black/Red Powe rpole housing PP30 C rimp C ontact s 12AWG Red/Blk B onded Cable | Ande r s on Powe r Ande r s on Powe r * | 1327G6FP/1327FP 1331 * | 2/2 4 84"

Title : Sho r t Panel Pwr Harne s s | Siz e : A | 2124 Penn Ave Pit t sburgh, PA 15222 412-362-0201

Par t Numbe r : GBW_ E E _101 | Rev: 00

Engine e r : P. Swe ene y | She e t : 1 o f 1

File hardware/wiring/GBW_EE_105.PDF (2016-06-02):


Line Item | Description | Manufacturer | Part Number | Qty
1 2 3 4 5 | Black/Red Powerpole housing PP15 Crimp Contacts MTA156 2-Pin Inline IDC MTA156 2-Pin Closed End IDC 18AWG Red/Blk Bonded Cable | Anderson Power Anderson Power TE TE * | 1327G6FP/1327FP 1332 3-643817-2 3-644465-2 * | 1/1 2 3 1 56"

COJ6BCD Title: LED Power Harness | Size: A | 2124 Penn Ave Pittsburgh, PA 15222 412-362-0201

Part Number: GBW_EE_105 | Rev: 00

Engineer: P. Sweeney | Sheet:1 of 1

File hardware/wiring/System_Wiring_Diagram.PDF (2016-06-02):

24VDC 12A; 220VAC 4.5A; Power Box; LED Panel; Control1 -ve; Control1 +ve; 208V Monitor 1A; 24V Monitor 1; 24V Monitor 2; 24V Monitor 3; Control2 -ve; 208V Monitor 2A; Control2 +ve; 24V Monitor 4; 24V Monitor 5; 24V Monitor 6; 208V Monitor 2B; 208V Monitor 1B; 220VAC <100mA

Line Item | Description | Manufacturer | Part Number | Qty
1 2 3 4 5 6 7 8 9 10 11 12 13 | Power Entry Module Terminal Block (w/ End cap) Circuit Breaker 220VAC 10A Signal Relay (240VAC) 10A Relay 960W AC/DC Power Supply 24V Circuit Breaker 24VDC 12A Signal Relay (24VDC) Button Panel Power Connector DC Indicator LED Fan Ethernet Pass Through 10W AC/DC Power Supply 24V | Schurter Phoenix Contact Schurter Phoenix Contact Phoenix Contact Mean Well Schurter Phoenix Contact Anderson Power APEM Sunon Harting TDK Lambda | EC11.0031.201 3044513 AS168X-CB1G100 2966207 2834643 SDR-960-24 AS168X-CB1G120 2903359 PP30 QS123XXG24 ME80252V3-000U-A99 09454521560 DSP10-24 | 1 10 2 2 2 1 6 6 6 2 1 1 1

AC/DC Supply

Control Board Power 24VDC

Fan AC/DC

Control Board DC GND

Title: Column Power Box | Size: B | 2124 Penn Ave Pittsburgh, PA 15222 412-362-0201

Part Number: GBW_EE_200 | Rev: 03

Engineer: P. Sweeney | Sheet:1 of 1

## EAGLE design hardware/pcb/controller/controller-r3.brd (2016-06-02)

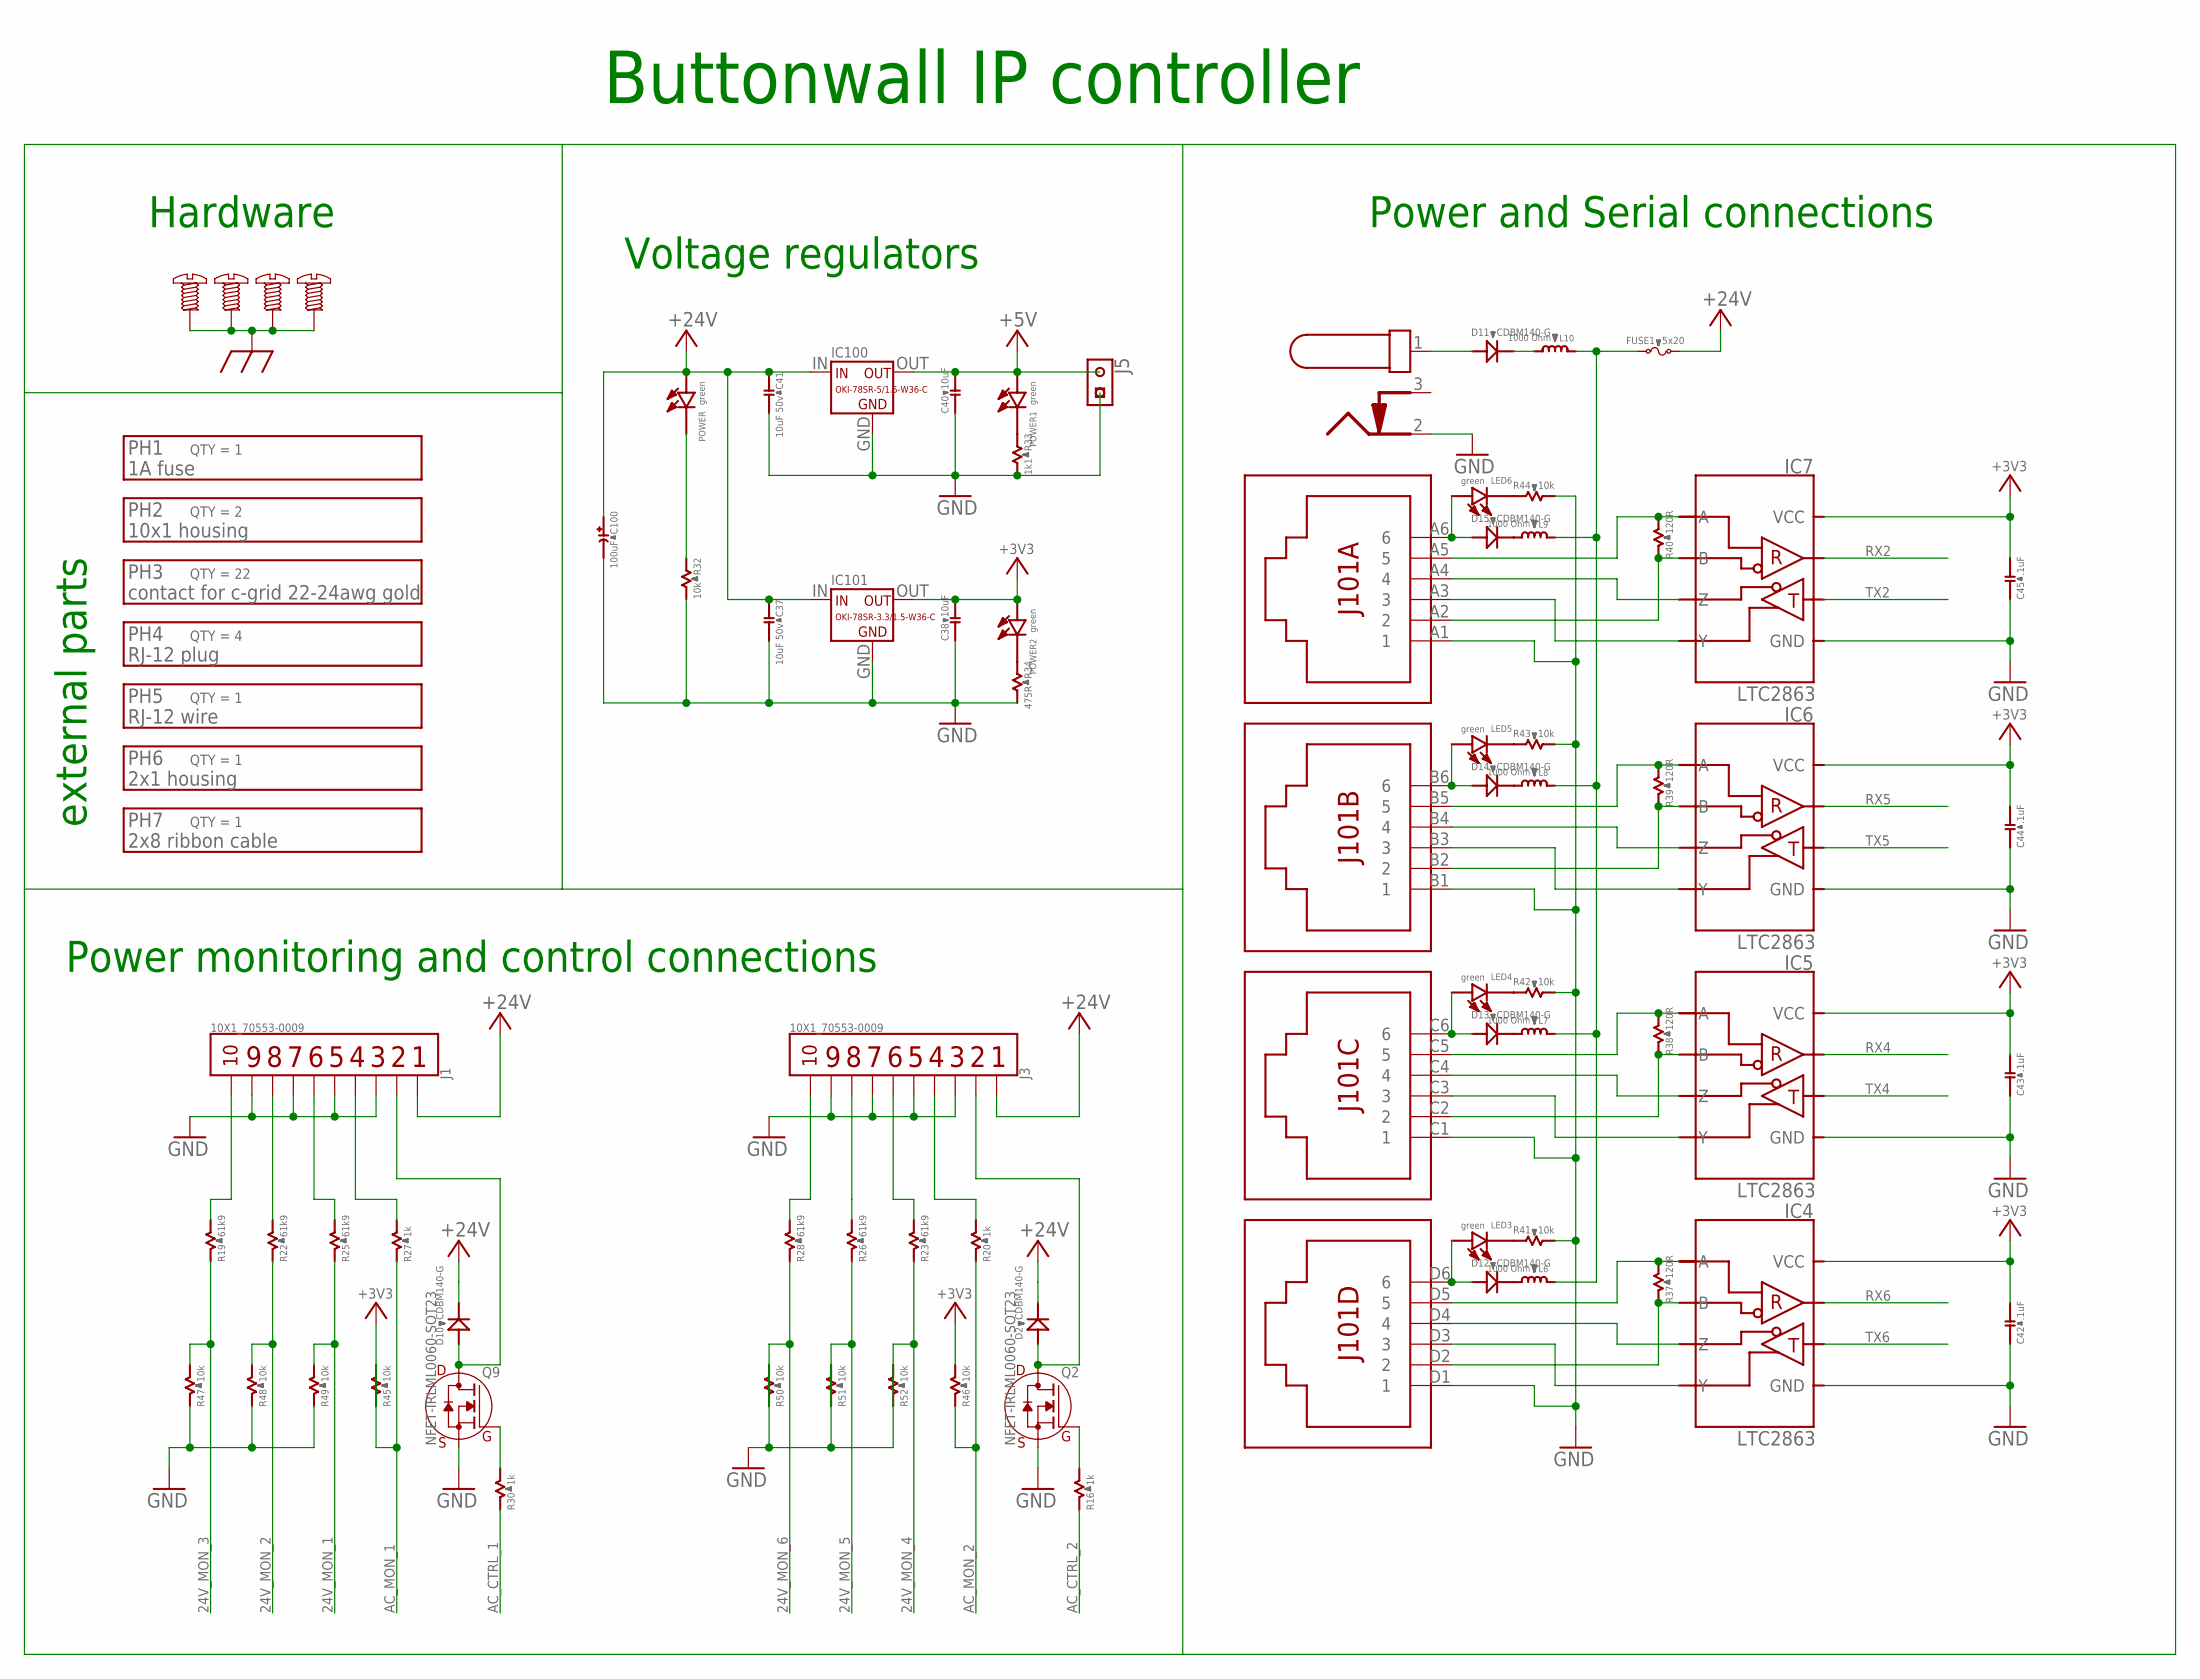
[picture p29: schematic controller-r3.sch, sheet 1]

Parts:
C37, C41: 10uF 50v; C1206B; PARTNO CL31A106KBHNNNE
C38, C40: 10uF; C0603B; PARTNO C1608X6S1A106M080AC
C42, C43, C44, C45: .1uF; C0603B; PARTNO CGA3E2X7R1H104K080AA
C100: 100uF; E3,5-8; PARTNO EEU-FM1H101
D2, D10, D11, D12, D13, D14, D15: CDBM140-G; SOD-123; PARTNO CDBM140-G
FUSE1: 5x20; 649; PARTNO 64900001039
IC4, IC5, IC6, IC7: LTC2863; SO08; PARTNO LTC2863IS8-1#PBF
IC100: OKI-78SR-5/1.5-W36-C; OKI-78SR-V; PARTNO OKI-78SR-5/1.5-W36-C
IC101: OKI-78SR-3.3/1.5-W36-C; OKI-78SR-V; PARTNO OKI-78SR-3.3/1.5-W36-C
J1, J3: 10X1_70553-0009; MOLEX_70553-(10); PARTNO 0705530009
J5: 1X2_70543; MOLEX_70543-0001; PARTNO 0705430001
J100: PJ-102AH; PJ-102(DC_JACK); PARTNO PJ-102AH
J101: RJ12-QUAD; SS-666604-NF; PARTNO SS-666604-NF
L6, L7, L8, L9, L10: 1000 Ohm; R0603B; PARTNO MMZ1608R102A
LED3, LED4, LED5, LED6: green; CHIPLED_0603; PARTNO LTST-C190KGKT
POWER, POWER1, POWER2: green; CHIPLED_0603; PARTNO LTST-C190KGKT
Q2, Q9: NFET-IRLML0060-SOT23; SOT-23; PARTNO IRLML0060TRPBF
R16, R20, R27, R30: 1k; R0603B; PARTNO CRCW06031K00FKEA
R19, R22, R23, R25, R26, R28: 61k9; R0603B; PARTNO CRCW060361K9FKEA
R32, R41, R42, R43, R44, R45, R46, R47, R48, R49, R50, R51, R52: 10k; R0603B; PARTNO CRCW060310K0FKEA
R33: 1k1; R0603B; PARTNO CRCW06031K10FKEA
R34: 475R; R0603B; PARTNO CRCW0603475RFKEA
R37, R38, R39, R40: 120R; R1206B; PARTNO CRCW1206120RFKEA
SCREW1, SCREW2, SCREW3, SCREW4: SCREW-632-0-PSHP; SMTPR-6-1

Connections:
24V_MON_1: R25.1, R49.2; also elsewhere on the board
24V_MON_2: R22.1, R48.2; also elsewhere on the board
24V_MON_3: R19.1, R47.2; also elsewhere on the board
24V_MON_4: R23.1, R52.1; also elsewhere on the board
24V_MON_5: R26.1, R51.1; also elsewhere on the board
24V_MON_6: R28.1, R50.1; also elsewhere on the board
+3V3: C38.2, C42.2, C43.2, C44.2, C45.2, IC4.1 (VCC), IC5.1 (VCC), IC6.1 (VCC), IC7.1 (VCC), IC101.OUT, POWER2.A (ANODE), R45.1, R46.2; also elsewhere on the board
+5V: C40.2, IC100.OUT, J5.2, POWER1.A (ANODE)
+24V: C37.1, C41.1, C100.+, D2.C (K), D10.C (K), FUSE1.2, IC100.IN, IC101.IN, J1.1, J3.1, POWER.A (ANODE)
AC_CTRL_1: R30.1; also elsewhere on the board
AC_CTRL_2: R16.1; also elsewhere on the board
AC_MON_1: R27.1, R45.2; also elsewhere on the board
AC_MON_2: R20.1, R46.1; also elsewhere on the board
CHASSIS: SCREW1.P$1, SCREW2.P$1, SCREW3.P$1, SCREW4.P$1; also elsewhere on the board
GND: C37.2, C38.1, C40.1, C41.2, C42.1, C43.1, C44.1, C45.1, C100.-, IC4.4 (GND), IC5.4 (GND), IC6.4 (GND), IC7.4 (GND), IC100.GND, IC101.GND, J1.3, J1.5, J1.7, J1.9, J3.3, J3.5, J3.7, J3.9, J5.1, J100.2 (SLEEVE), J101.A1 (1), J101.B1 (1), J101.C1 (1), J101.D1 (1), Q2.2 (S), Q9.2 (S), R32.2, R33.2, R34.2, R41.2, R42.2, R43.2, R44.2, R47.1, R48.1, R49.1, R50.2, R51.2, R52.2; also elsewhere on the board
unnamed: IC7.7 (B), J101.A2 (2), R40.1
unnamed: POWER1.C (CATHODE), R33.1
unnamed: IC7.8 (A), J101.A5 (5), R40.2
unnamed: D15.C (K), L9.2
unnamed: POWER.C (CATHODE), R32.1
unnamed: IC7.5 (Y), J101.A3 (3)
unnamed: IC7.6 (Z), J101.A4 (4)
unnamed: IC6.7 (B), J101.B2 (2), R39.1
unnamed: IC6.8 (A), J101.B5 (5), R39.2
unnamed: D15.A, J101.A6 (6), LED6.A (ANODE)
unnamed: IC6.5 (Y), J101.B3 (3)
unnamed: IC6.6 (Z), J101.B4 (4)
unnamed: IC5.7 (B), J101.C2 (2), R38.1
unnamed: IC5.8 (A), J101.C5 (5), R38.2
unnamed: D14.C (K), L8.2
unnamed: IC5.5 (Y), J101.C3 (3)
unnamed: IC5.6 (Z), J101.C4 (4)
unnamed: IC4.7 (B), J101.D2 (2), R37.1
unnamed: IC4.8 (A), J101.D5 (5), R37.2
unnamed: D14.A, J101.B6 (6), LED5.A (ANODE)
unnamed: IC4.5 (Y), J101.D3 (3)
unnamed: IC4.6 (Z), J101.D4 (4)
unnamed: J1.4, R27.2
unnamed: J1.10, R19.2
unnamed: J1.8, R22.2
unnamed: J1.6, R25.2
unnamed: D10.A, J1.2, Q9.3 (D)
unnamed: Q9.1 (G), R30.2
unnamed: D13.C (K), L7.2
unnamed: D13.A, J101.C6 (6), LED4.A (ANODE)
unnamed: D12.C (K), L6.2
unnamed: D12.A, J101.D6 (6), LED3.A (ANODE)
unnamed: D11.C (K), L10.2
unnamed: D11.A, J100.1 (CENTER)
unnamed: J3.10, R28.2
unnamed: J3.8, R26.2
unnamed: J3.6, R23.2
unnamed: J3.4, R20.2
unnamed: D2.A, J3.2, Q2.3 (D)
unnamed: Q2.1 (G), R16.2
unnamed: POWER2.C (CATHODE), R34.1
unnamed: FUSE1.1, L6.1, L7.1, L8.1, L9.1, L10.1
unnamed: LED5.C (CATHODE), R43.1
unnamed: LED6.C (CATHODE), R44.1
unnamed: LED4.C (CATHODE), R42.1
unnamed: LED3.C (CATHODE), R41.1
RX2: IC7.2 (RO); also elsewhere on the board
RX4: IC5.2 (RO); also elsewhere on the board
RX5: IC6.2 (RO); also elsewhere on the board
RX6: IC4.2 (RO); also elsewhere on the board
TX2: IC7.3 (DI); also elsewhere on the board
TX4: IC5.3 (DI); also elsewhere on the board
TX5: IC6.3 (DI); also elsewhere on the board
TX6: IC4.3 (DI); also elsewhere on the board

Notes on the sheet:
Buttonwall IP controller
Hardware
Voltage regulators
Power and Serial connections
external parts
Power monitoring and control connections

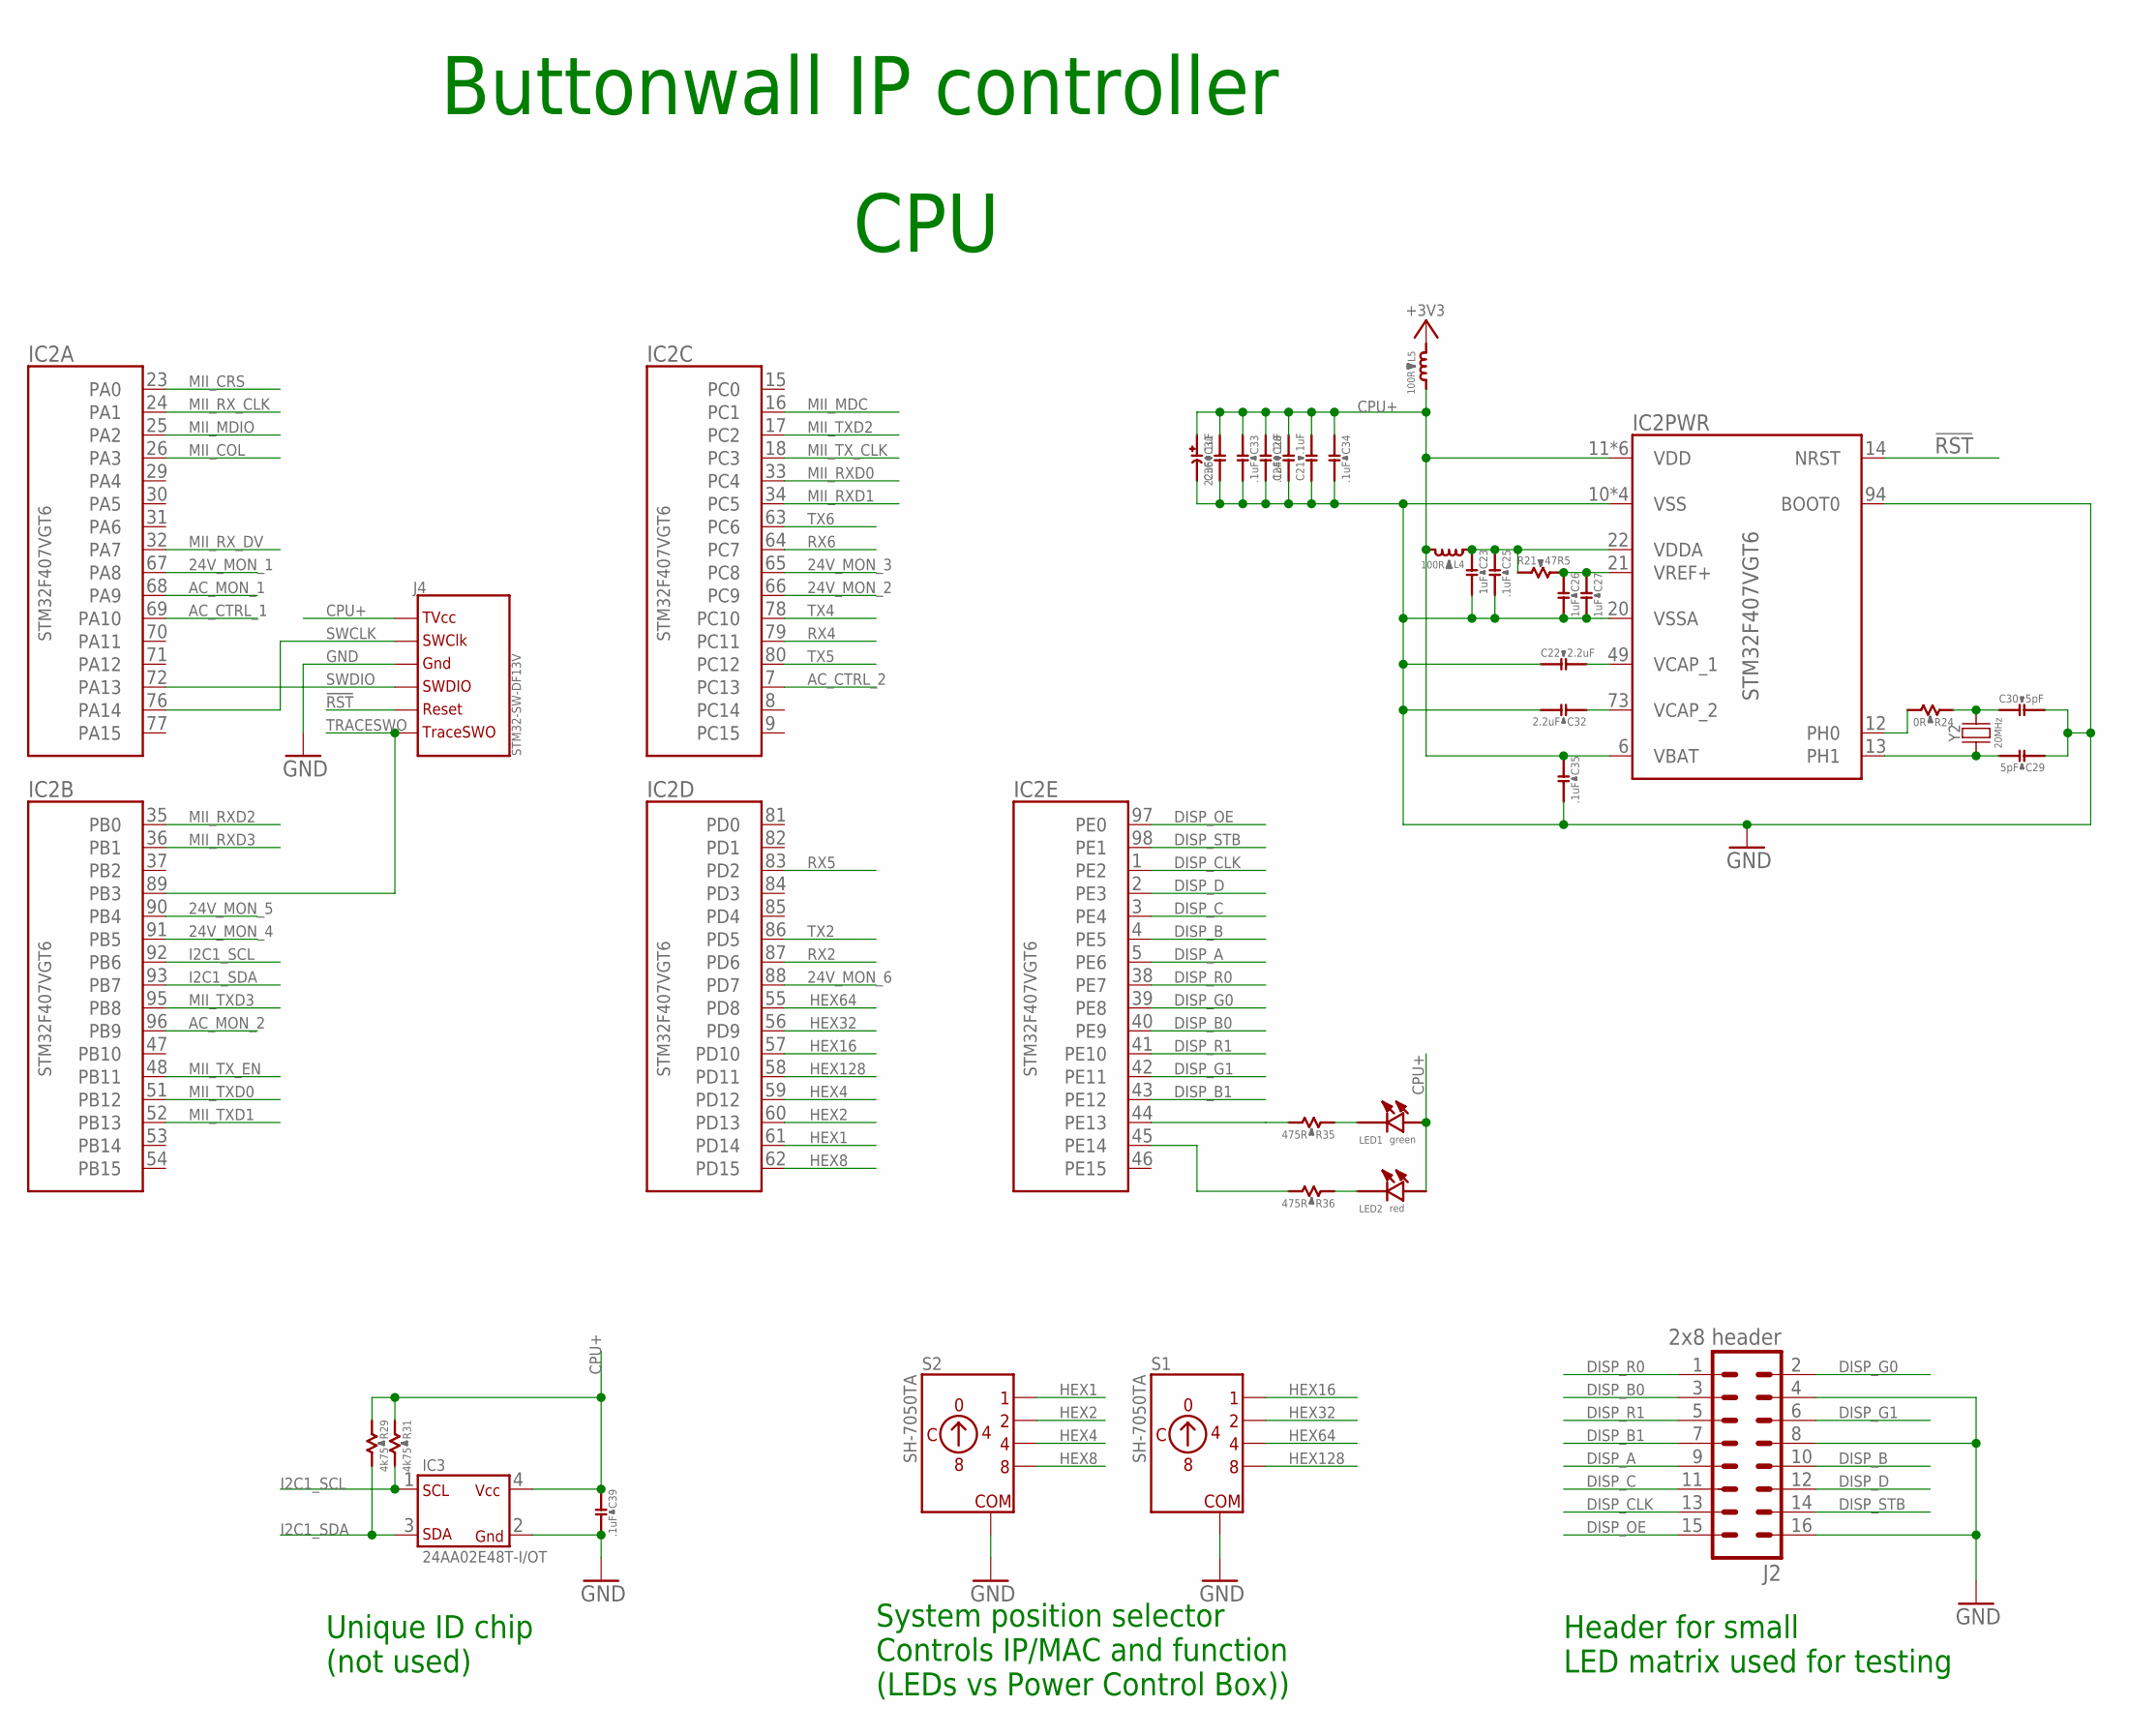
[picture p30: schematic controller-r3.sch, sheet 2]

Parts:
C21, C24, C25, C27, C28, C33, C34, C35, C36, C39: .1uF; C0603B; PARTNO CGA3E2X7R1H104K080AA
C22, C32: 2.2uF; C0603B; PARTNO C1608X5R1V225K080AC
C23, C26: 1uF; C0603B; PARTNO CGA3E3X5R1H105K080AB
C29, C30: 5pF; C0603B; PARTNO CGA3E2C0G1H050C080AA
C31: 22uF; B/3528-21R; PARTNO 293D226X96R3B2TE3
IC2: STM32F407VGT6; LQFP-100; PARTNO STM32F407VGT6
IC3: 24AA02E48T-I/OT; SOT-23-5; PARTNO 24AA02E48T-I/OT
J2: 2x8 header; ML16; PARTNO SBH11-PBPC-D08-ST-BK
J4: STM32-SW-DF13V; DF13-6P-1.25V; PARTNO DF13C-6P-1.25V(20)
L4, L5: 100R; R0603B; PARTNO MPZ1608S101A
LED1: green; CHIPLED_0603; PARTNO LTST-C190KGKT
LED2: red; CHIPLED_0603; PARTNO LTST-C190KRKT
R21: 47R5; R0603B; PARTNO CRCW060347R5FKEA
R24: 0R; R0603B; PARTNO CRCW06030000Z0EA
R29, R31: 4k75; R0603B; PARTNO CRCW06034K75FKEA
R35, R36: 475R; R0603B; PARTNO CRCW0603475RFKEA
S1, S2: SH-7050TA; PARTNO SH-7050TA
Y2: 20MHz; 5X3.2; PARTNO 7A-20.000MAHE-T

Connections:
24V_MON_1: IC2.67 (PA8); also elsewhere on the board
24V_MON_2: IC2.66 (PC9); also elsewhere on the board
24V_MON_3: IC2.65 (PC8); also elsewhere on the board
24V_MON_4: IC2.91 (PB5); also elsewhere on the board
24V_MON_5: IC2.90 (PB4); also elsewhere on the board
24V_MON_6: IC2.88 (PD7); also elsewhere on the board
!RST: IC2.14 (NRST), J4.5 (RESET)
+3V3: L5.1; also elsewhere on the board
AC_CTRL_1: IC2.69 (PA10); also elsewhere on the board
AC_CTRL_2: IC2.7 (PC13); also elsewhere on the board
AC_MON_1: IC2.68 (PA9); also elsewhere on the board
AC_MON_2: IC2.96 (PB9); also elsewhere on the board
CPU+: C21.2, C24.2, C28.1, C31.+, C33.1, C34.1, C35.1, C36.2, C39.1, IC2.6 (VBAT), IC2.11 (VDD), IC2.19 (VDD), IC2.28 (VDD), IC2.50 (VDD), IC2.75 (VDD), IC2.100 (VDD), IC3.4 (VCC), J4.1 (TVCC), L4.2, L5.2, LED1.A (ANODE), LED2.A (ANODE), R29.1, R31.1
DISP_A: IC2.5 (PE6), J2.9
DISP_B: IC2.4 (PE5), J2.10
DISP_B0: IC2.40 (PE9), J2.3
DISP_B1: IC2.43 (PE12), J2.7
DISP_C: IC2.3 (PE4), J2.11
DISP_CLK: IC2.1 (PE2), J2.13
DISP_D: IC2.2 (PE3), J2.12
DISP_G0: IC2.39 (PE8), J2.2
DISP_G1: IC2.42 (PE11), J2.6
DISP_OE: IC2.97 (PE0), J2.15
DISP_R0: IC2.38 (PE7), J2.1
DISP_R1: IC2.41 (PE10), J2.5
DISP_STB: IC2.98 (PE1), J2.14
GND: C21.1, C22.1, C23.2, C24.1, C25.2, C26.2, C27.2, C28.2, C29.1, C30.2, C31.-, C32.2, C33.2, C34.2, C35.2, C36.1, C39.2, IC2.10 (VSS), IC2.20 (VSSA), IC2.27 (VSS), IC2.74 (VSS), IC2.94 (BOOT0), IC2.99 (VSS), IC3.2 (GND), J2.4, J2.8, J2.16, J4.3 (GND), S1.C (COM), S1.C@2 (COM), S2.C (COM), S2.C@2 (COM); also elsewhere on the board
HEX1: IC2.61 (PD14), S2.1
HEX2: IC2.60 (PD13), S2.2
HEX4: IC2.59 (PD12), S2.4
HEX8: IC2.62 (PD15), S2.8
HEX16: IC2.57 (PD10), S1.1
HEX32: IC2.56 (PD9), S1.2
HEX64: IC2.55 (PD8), S1.4
HEX128: IC2.58 (PD11), S1.8
I2C1_SCL: IC2.92 (PB6), IC3.1 (SCL), R31.2
I2C1_SDA: IC2.93 (PB7), IC3.3 (SDA), R29.2
MII_COL: IC2.26 (PA3); also elsewhere on the board
MII_CRS: IC2.23 (PA0); also elsewhere on the board
MII_MDC: IC2.16 (PC1); also elsewhere on the board
MII_MDIO: IC2.25 (PA2); also elsewhere on the board
MII_RXD0: IC2.33 (PC4); also elsewhere on the board
MII_RXD1: IC2.34 (PC5); also elsewhere on the board
MII_RXD2: IC2.35 (PB0); also elsewhere on the board
MII_RXD3: IC2.36 (PB1); also elsewhere on the board
MII_RX_CLK: IC2.24 (PA1); also elsewhere on the board
MII_RX_DV: IC2.32 (PA7); also elsewhere on the board
MII_TXD0: IC2.51 (PB12); also elsewhere on the board
MII_TXD1: IC2.52 (PB13); also elsewhere on the board
MII_TXD2: IC2.17 (PC2); also elsewhere on the board
MII_TXD3: IC2.95 (PB8); also elsewhere on the board
MII_TX_CLK: IC2.18 (PC3); also elsewhere on the board
MII_TX_EN: IC2.48 (PB11); also elsewhere on the board
unnamed: IC2.12 (PH0), R24.2
unnamed: C29.2, IC2.13 (PH1), Y2.1
unnamed: C30.1, R24.1, Y2.2
unnamed: C22.2, IC2.49 (VCAP_1)
unnamed: C32.1, IC2.73 (VCAP_2)
unnamed: C23.1, C25.1, IC2.22 (VDDA), L4.1, R21.1
unnamed: C26.1, C27.1, IC2.21 (VREF+), R21.2
unnamed: LED1.C (CATHODE), R35.1
unnamed: LED2.C (CATHODE), R36.1
unnamed: IC2.45 (PE14), R36.2
unnamed: IC2.44 (PE13), R35.2
RX2: IC2.87 (PD6); also elsewhere on the board
RX4: IC2.79 (PC11); also elsewhere on the board
RX5: IC2.83 (PD2); also elsewhere on the board
RX6: IC2.64 (PC7); also elsewhere on the board
SWCLK: IC2.76 (PA14), J4.2 (SWCLK)
SWDIO: IC2.72 (PA13), J4.4 (SWDIO)
TRACESWO: IC2.89 (PB3), J4.6 (TRACESWO)
TX2: IC2.86 (PD5); also elsewhere on the board
TX4: IC2.78 (PC10); also elsewhere on the board
TX5: IC2.80 (PC12); also elsewhere on the board
TX6: IC2.63 (PC6); also elsewhere on the board

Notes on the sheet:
CPU
Buttonwall IP controller
Unique ID chip (not used)
System position selector Controls IP/MAC and function (LEDs vs Power Control Box))
Header for small LED matrix used for testing

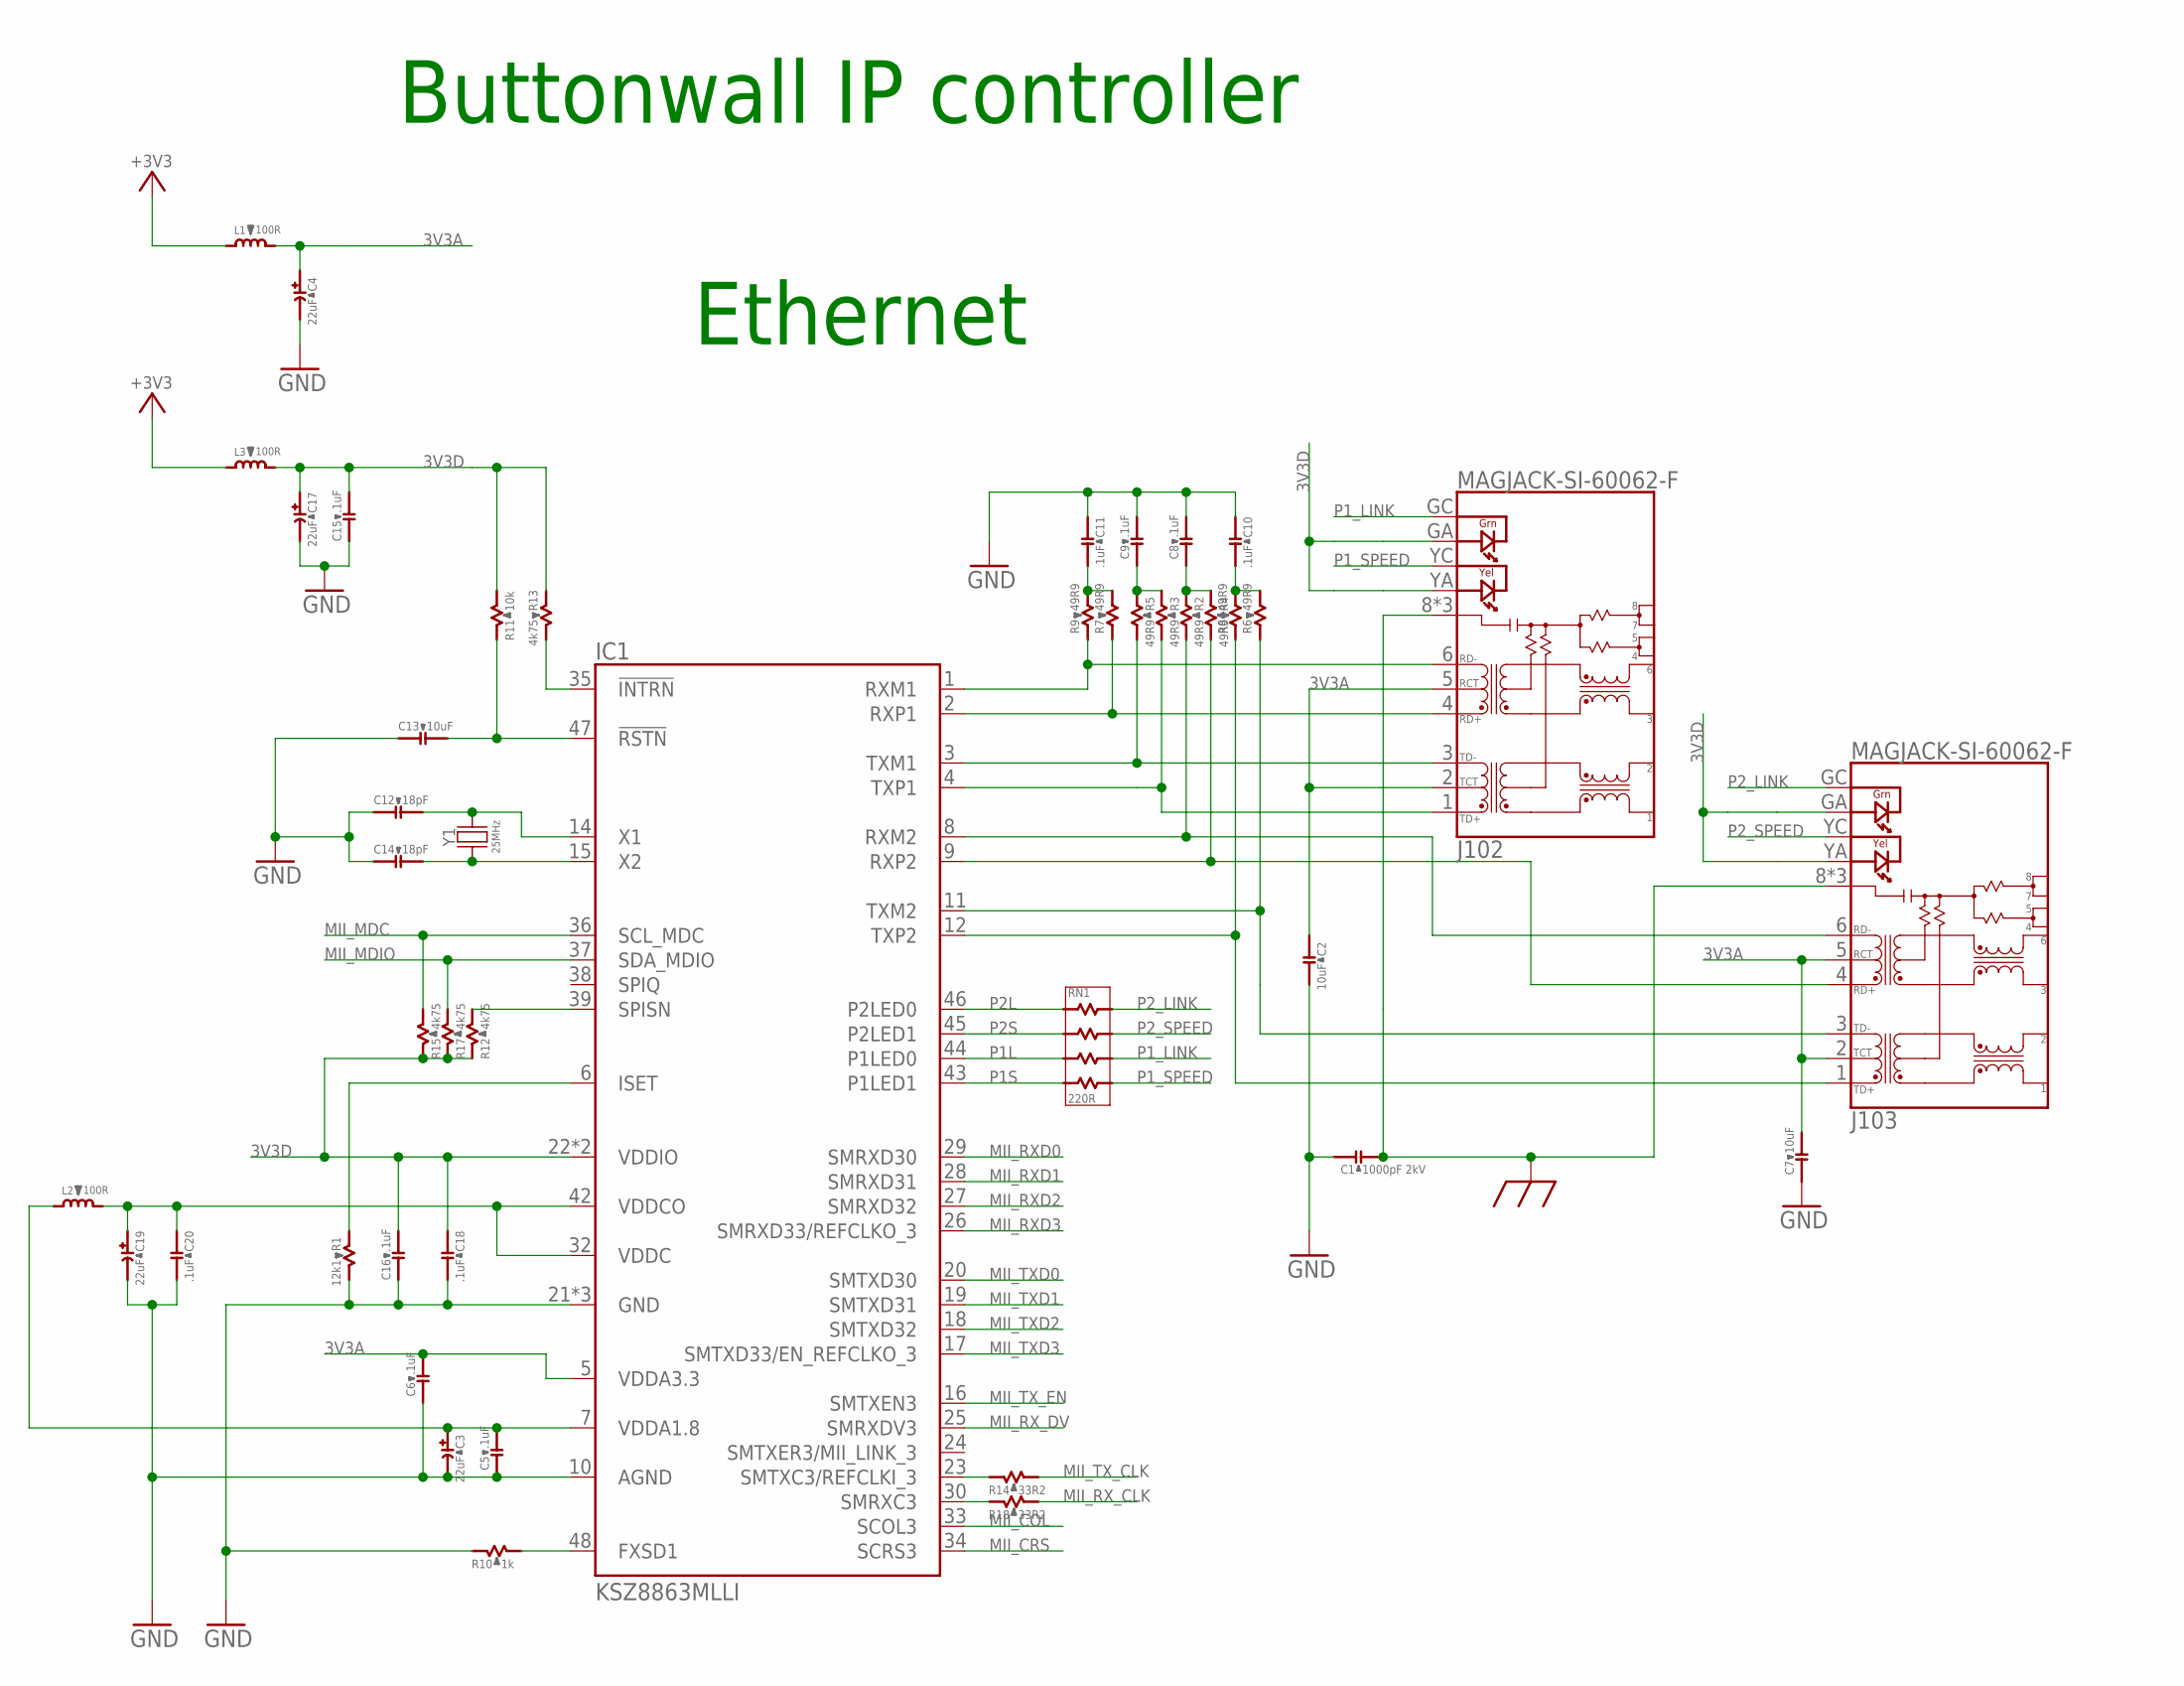
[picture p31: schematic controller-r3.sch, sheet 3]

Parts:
C1: 1000pF 2kV; C1206B; PARTNO 202R18W102KV4E
C2, C7, C13: 10uF; C0603B; PARTNO C1608X6S1A106M080AC
C3, C4, C17, C19: 22uF; B/3528-21R; PARTNO 293D226X96R3B2TE3
C5, C6, C8, C9, C10, C11, C15, C16, C18, C20: .1uF; C0603B; PARTNO CGA3E2X7R1H104K080AA
C12, C14: 18pF; C0603B; PARTNO CGA3E2C0G1H180J080AA
IC1: KSZ8863MLLI; TQFP48; PARTNO KSZ8863MLLI
J102, J103: MAGJACK-SI-60062-F; SI-60062-F; PARTNO SI-60062-F
L1, L2, L3: 100R; R0603B; PARTNO MPZ1608S101A
R1: 12k1; R0603B; PARTNO CRCW060312K1FKEA
R2, R3, R4, R5, R6, R7, R8, R9: 49R9; R0603B; PARTNO CRCW060349R9FKEA
R10: 1k; R0603B; PARTNO CRCW06031K00FKEA
R11: 10k; R0603B; PARTNO CRCW060310K0FKEA
R12, R13, R15, R17: 4k75; R0603B; PARTNO CRCW06034K75FKEA
R14, R18: 33R2; R0603B; PARTNO CRCW060333R2FKEA
RN1: 220R; CTS_742-4; PARTNO 742C083221JP
Y1: 25MHz; 5X3.2; PARTNO 7A-25.000MAHE-T

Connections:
3V3A: C2.1, C4.+, C6.2, C7.2, IC1.5 (VDDA3.3), J102.2 (TCT), J102.5 (RCT), J103.2 (TCT), J103.5 (RCT), L1.2
3V3D: C15.2, C16.2, C17.+, C18.1, IC1.22 (VDDIO), IC1.40 (VDDIO), J102.GA, J102.YA, J103.GA, J103.YA, L3.2, R11.2, R12.1, R13.1, R15.1, R17.1
+3V3: L1.1, L3.1; also elsewhere on the board
CHASSIS: C1.2, J102.8 (CHASSIS), J102.P$1 (CHASSIS), J102.P$2 (CHASSIS), J103.8 (CHASSIS), J103.P$1 (CHASSIS), J103.P$2 (CHASSIS); also elsewhere on the board
GND: C1.1, C2.2, C3.-, C4.-, C5.1, C6.1, C7.1, C8.2, C9.2, C10.1, C11.1, C12.1, C13.1, C14.1, C15.1, C16.1, C17.-, C18.2, C19.-, C20.2, IC1.10 (AGND), IC1.21 (GND), IC1.31 (GND), IC1.41 (GND), R1.2, R10.1; also elsewhere on the board
MII_COL: IC1.33 (SCOL3); also elsewhere on the board
MII_CRS: IC1.34 (SCRS3); also elsewhere on the board
MII_MDC: IC1.36 (SCL_MDC), R15.2; also elsewhere on the board
MII_MDIO: IC1.37 (SDA_MDIO), R17.2; also elsewhere on the board
MII_RXD0: IC1.29 (SMRXD30); also elsewhere on the board
MII_RXD1: IC1.28 (SMRXD31); also elsewhere on the board
MII_RXD2: IC1.27 (SMRXD32); also elsewhere on the board
MII_RXD3: IC1.26 (SMRXD33/REFCLKO_3); also elsewhere on the board
MII_RX_CLK: R18.2; also elsewhere on the board
MII_RX_DV: IC1.25 (SMRXDV3); also elsewhere on the board
MII_TXD0: IC1.20 (SMTXD30); also elsewhere on the board
MII_TXD1: IC1.19 (SMTXD31); also elsewhere on the board
MII_TXD2: IC1.18 (SMTXD32); also elsewhere on the board
MII_TXD3: IC1.17 (SMTXD33/EN_REFCLKO_3); also elsewhere on the board
MII_TX_CLK: R14.2; also elsewhere on the board
MII_TX_EN: IC1.16 (SMTXEN3); also elsewhere on the board
unnamed: C11.2, R7.2, R9.2
unnamed: C9.1, R3.1, R5.1
unnamed: C8.1, R2.1, R4.1
unnamed: C10.2, R6.2, R8.2
unnamed: IC1.30 (SMRXC3), R18.1
unnamed: IC1.1 (RXM1), J102.6 (RD-), R9.1
unnamed: IC1.2 (RXP1), J102.4 (RD+), R7.1
unnamed: IC1.3 (TXM1), J102.3 (TD-), R5.2
unnamed: IC1.8 (RXM2), J103.6 (RD-), R2.2
unnamed: IC1.9 (RXP2), J103.4 (RD+), R4.2
unnamed: IC1.11 (TXM2), J103.3 (TD-), R6.1
unnamed: IC1.12 (TXP2), J103.1 (TD+), R8.1
unnamed: IC1.23 (SMTXC3/REFCLKI_3), R14.1
unnamed: C14.2, IC1.15 (X2), Y1.1
unnamed: C12.2, IC1.14 (X1), Y1.2
unnamed: IC1.35 (!INTRN), R13.2
unnamed: C13.2, IC1.47 (!RSTN), R11.1
unnamed: C3.+, C5.2, IC1.7 (VDDA1.8), L2.1
unnamed: IC1.48 (FXSD1), R10.2
unnamed: IC1.6 (ISET), R1.1
unnamed: IC1.39 (SPISN), R12.2
unnamed: IC1.4 (TXP1), J102.1 (TD+), R3.2
P1L: IC1.44 (P1LED0), RN1.C1
P1S: IC1.43 (P1LED1), RN1.D1
P1_LINK: J102.GC, RN1.C2
P1_SPEED: J102.YC, RN1.D2
P2L: IC1.46 (P2LED0), RN1.A1
P2S: IC1.45 (P2LED1), RN1.B1
P2_LINK: J103.GC, RN1.A2
P2_SPEED: J103.YC, RN1.B2
VDDC: C19.+, C20.1, IC1.32 (VDDC), IC1.42 (VDDCO), L2.2

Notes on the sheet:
Ethernet
Buttonwall IP controller

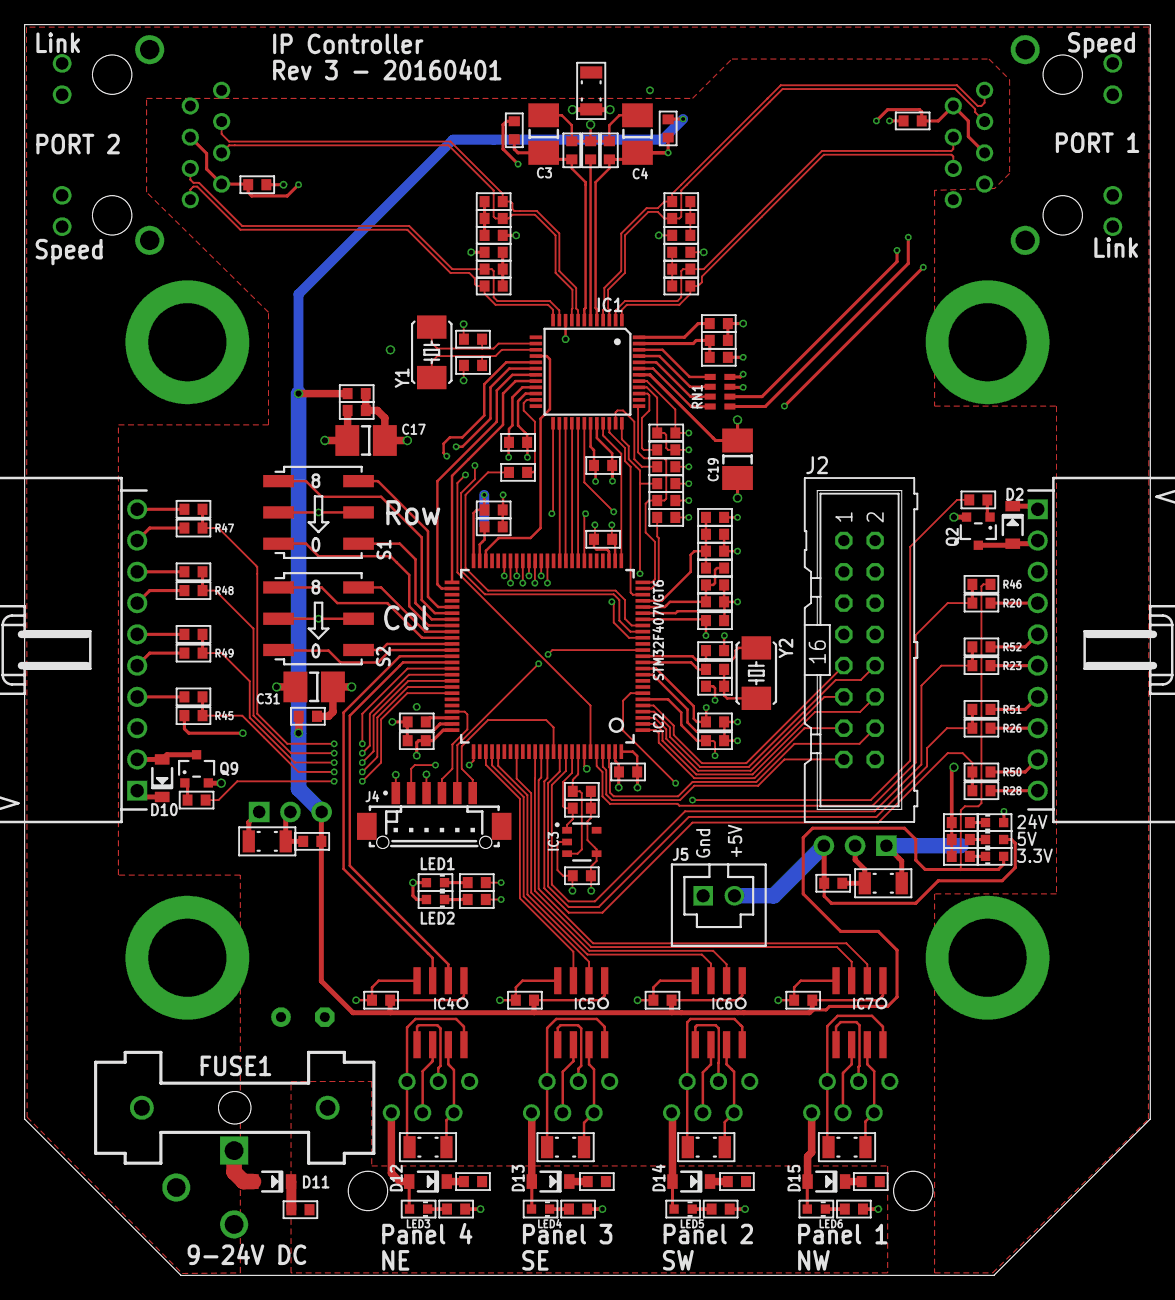
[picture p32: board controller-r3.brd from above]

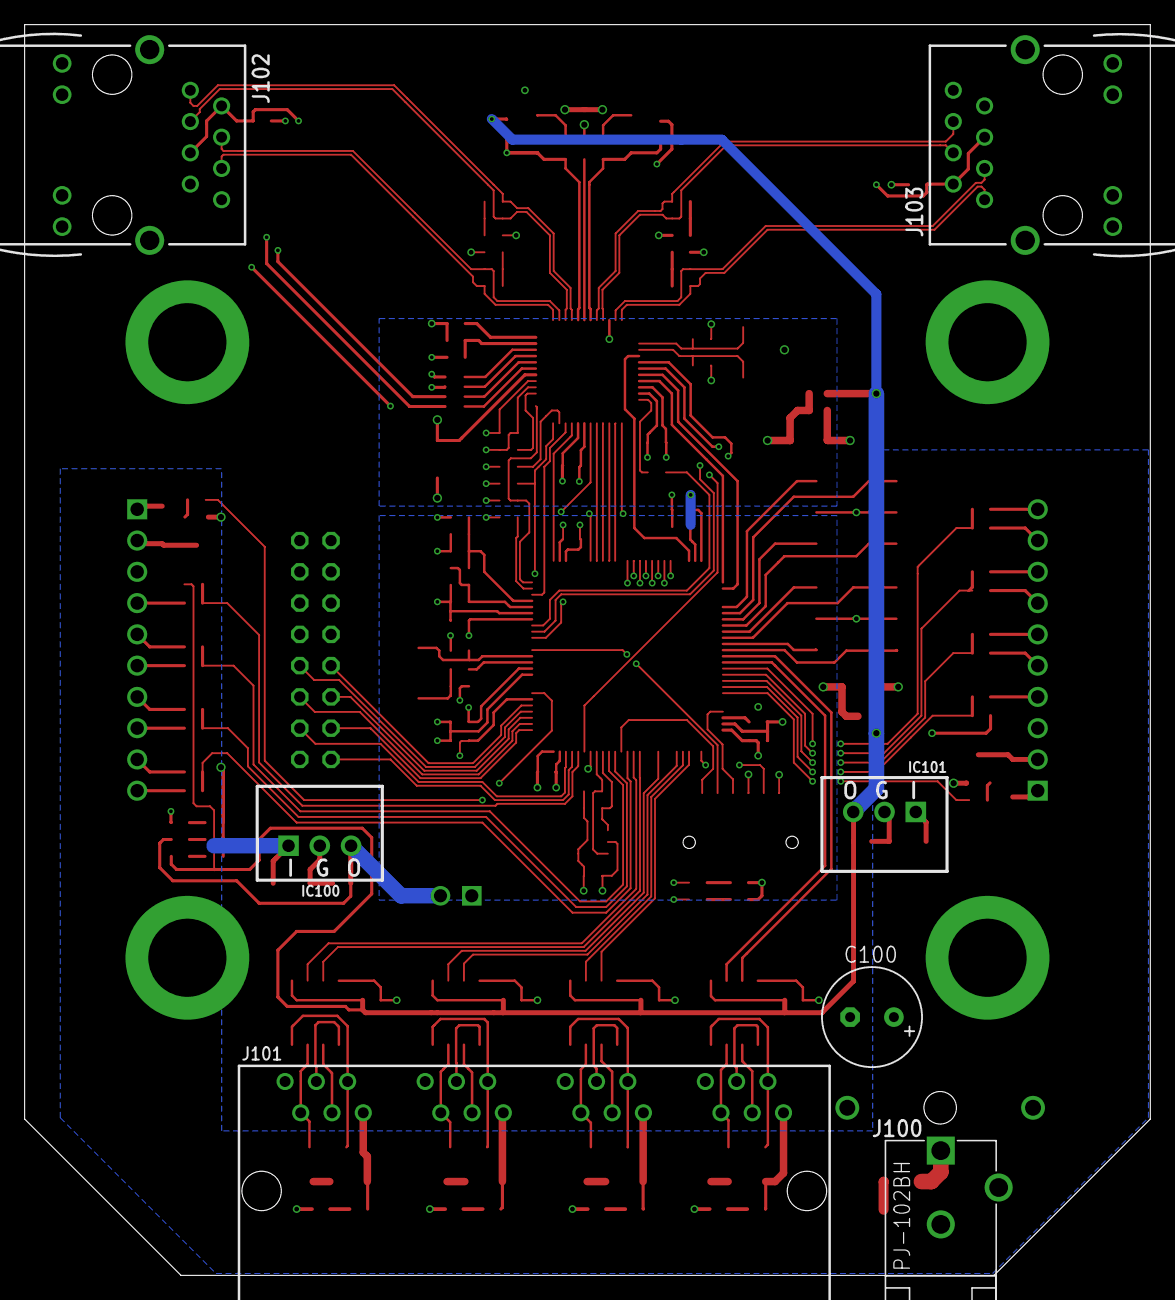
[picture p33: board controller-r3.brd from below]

Board: 4 copper layers, 91.4 x 101.6 mm, 154 parts (7 on the bottom side), 157 nets.

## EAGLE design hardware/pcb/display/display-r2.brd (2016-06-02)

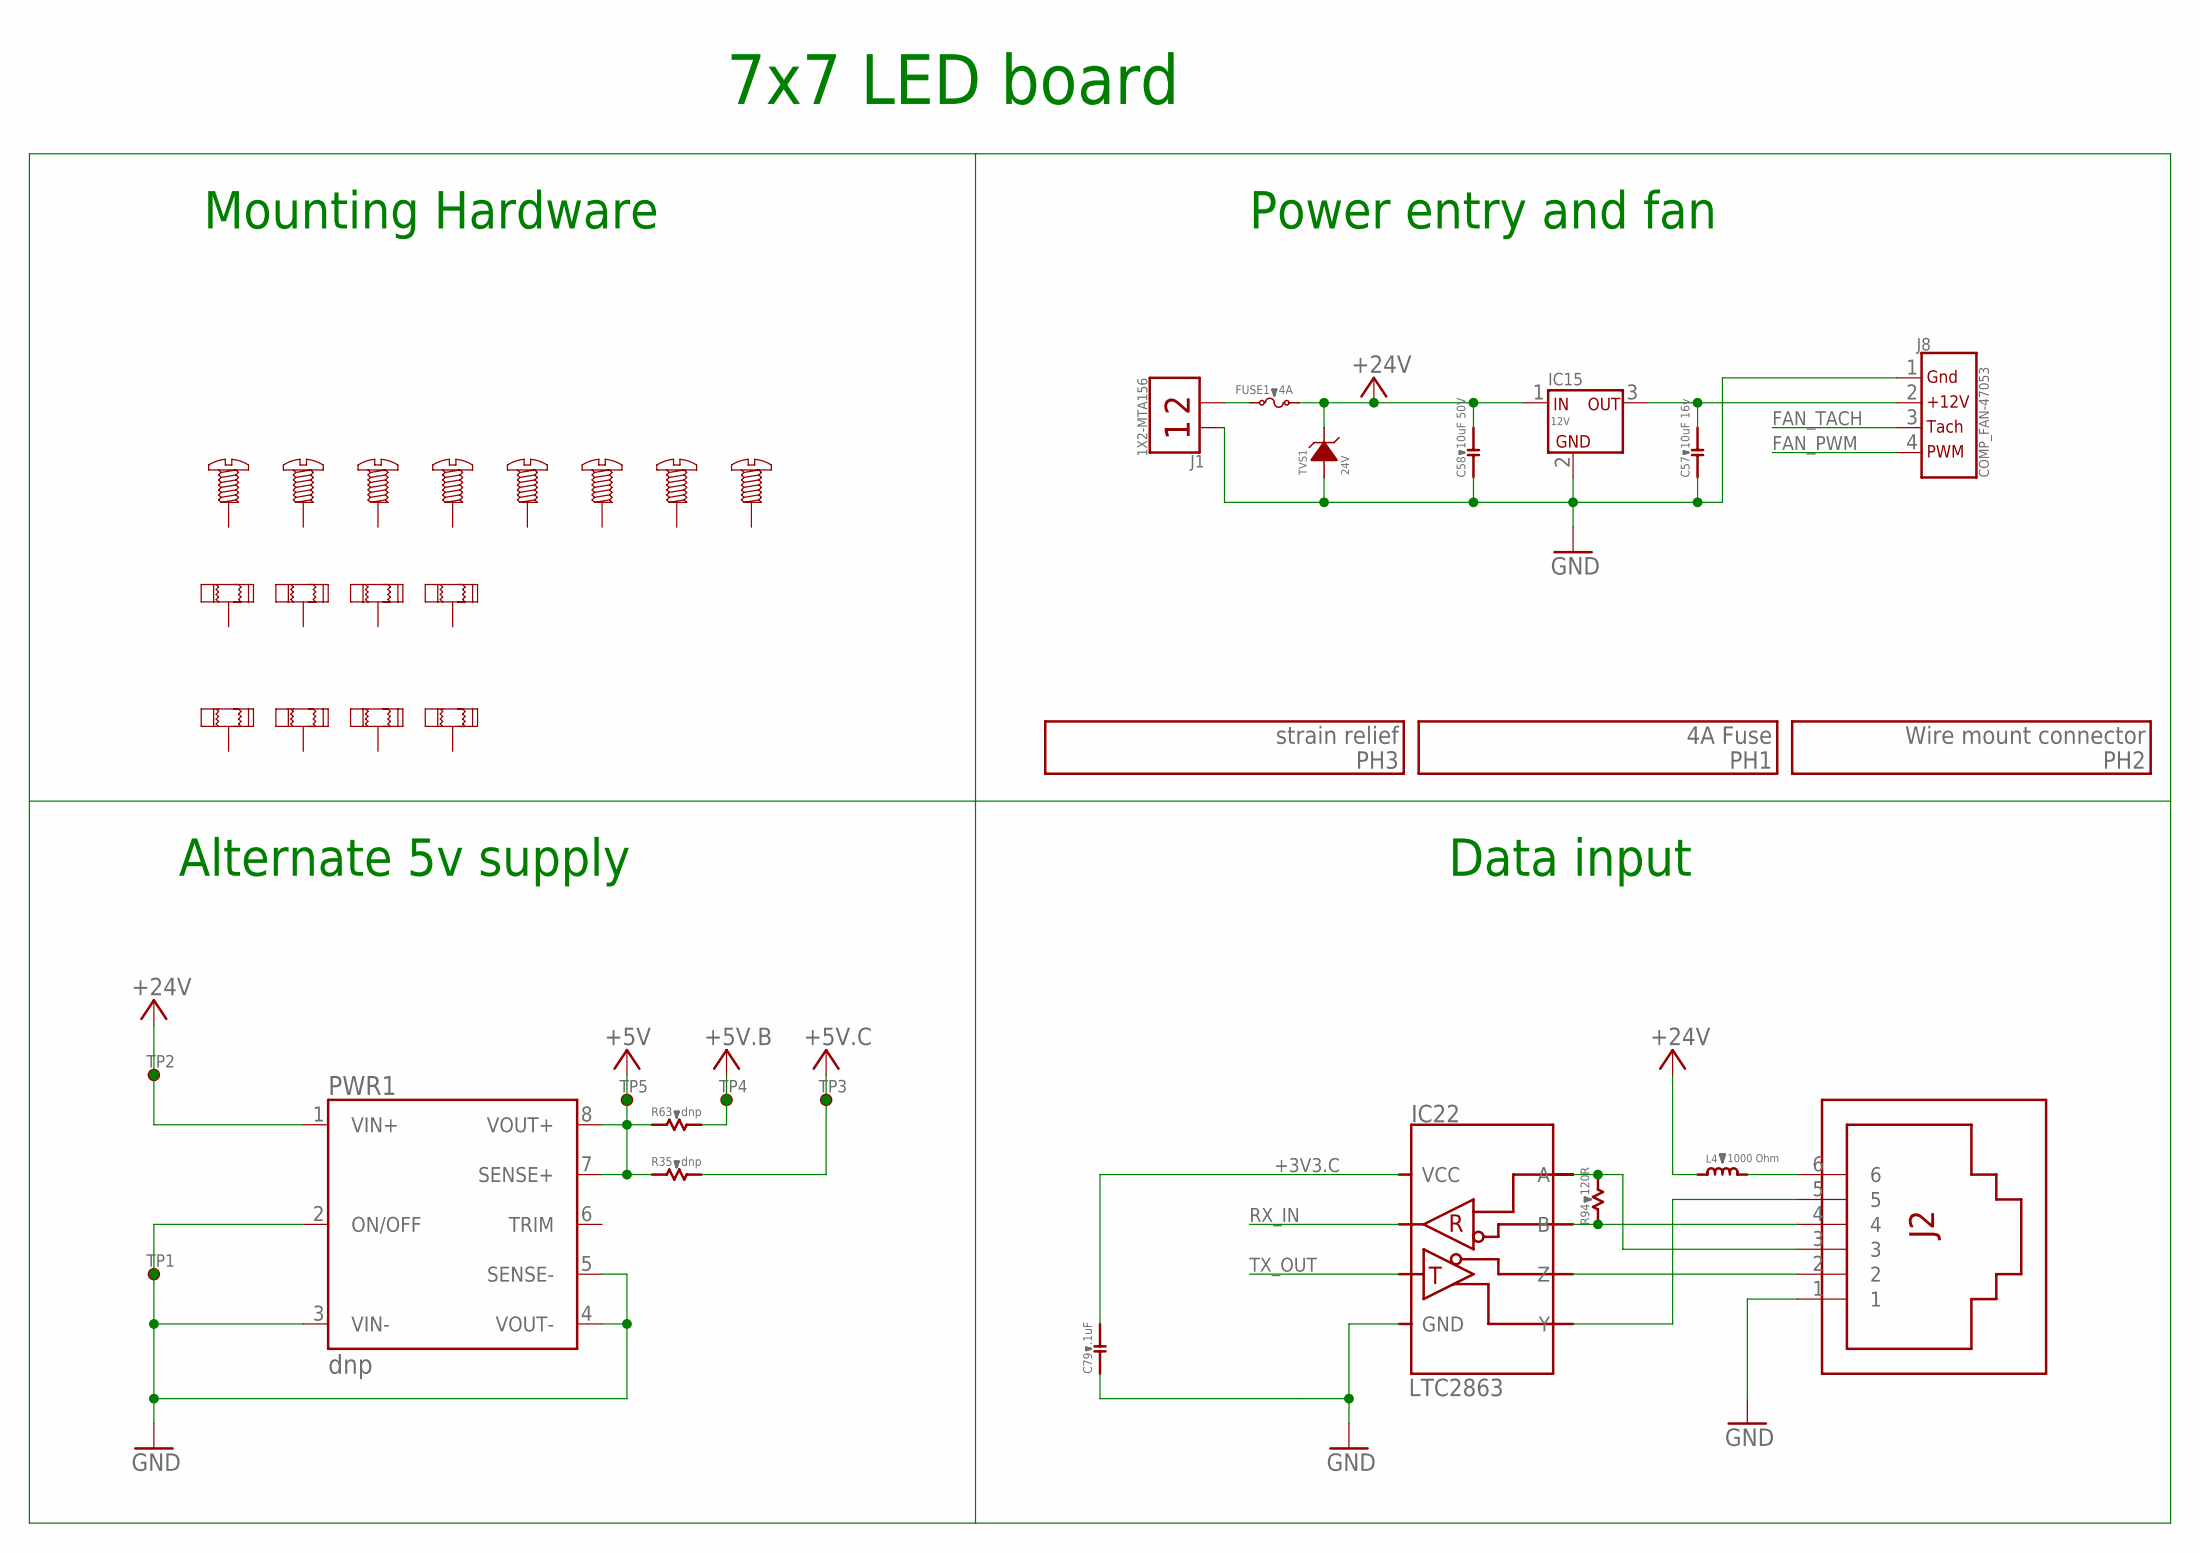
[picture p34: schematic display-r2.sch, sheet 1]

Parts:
C57: 10uF 16v; C0805B; PARTNO CGA4J1X5R1C106K125AC
C58: 10uF 50V; C1206B; PARTNO CL31A106KBHNNNE
C79: .1uF; C0603B; PARTNO CGA3E2X7R1H104K080AA
FUSE1: 4A; 649; PARTNO 64900001039
IC15: 12V; P7805; PARTNO P7805-Q24-S12-S
IC22: LTC2863; SO08; PARTNO LTC2863IS8-1#PBF
J1: 1X2-MTA156; 640445-2; PARTNO 640445-2
J2: RJ12-JACK-RJE01; RJE01-660-01; PARTNO RJE0166001
J8: COMP_FAN-47053; 47053; PARTNO 0470531000
L4: 1000 Ohm; R0603B; PARTNO MMZ1608R102A
NUT1, NUT2, NUT3, NUT4: NUTSMTSO-632; SMTSO-632-2ET
NUT5, NUT6, NUT7, NUT8: NUTSMTSO-832; SMTSO-832-2ET
PWR1: dnp; PWR-1/4-BRICK
R35, R63: dnp; R0805B
R94: 120R; R1206B; PARTNO CRCW1206120RFKEA
SCREW1, SCREW2, SCREW3, SCREW4, SCREW5, SCREW6, SCREW7, SCREW8: SCREW-632-0-PSHP; SMTPR-6-1
TP1, TP2, TP3, TP4, TP5: TP-CIR30; SMD_CIR30
TVS1: 24V; SMC/DO214AB; PARTNO 4.0SMDJ24A

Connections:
+3V3.C: C79.2, IC22.1 (VCC); also elsewhere on the board
+5V: PWR1.7 (SENSE+), PWR1.8 (VOUT+), R35.1, R63.1, TP5.P$1; also elsewhere on the board
+5VB: R63.2, TP4.P$1; also elsewhere on the board
+5VC: R35.2, TP3.P$1; also elsewhere on the board
+24V: C58.2, FUSE1.2, IC15.1 (IN), L4.1, PWR1.1 (VIN+), TP2.P$1, TVS1.C (CATHODE); also elsewhere on the board
+24V_OUT: J2.6, L4.2
FAN_PWM: J8.4; also elsewhere on the board
FAN_TACH: J8.3; also elsewhere on the board
GND: C57.1, C58.1, C79.1, IC15.2 (GND), IC22.4 (GND), J1.1, J2.1, J8.1, PWR1.2 (ON/OFF), PWR1.3 (VIN-), PWR1.4 (VOUT-), PWR1.5 (SENSE-), TP1.P$1, TVS1.A (ANODE); also elsewhere on the board
unnamed: FUSE1.1, J1.2
unnamed: IC22.7 (B), J2.4, R94.1
unnamed: IC22.8 (A), J2.3, R94.2
unnamed: IC22.6 (Z), J2.2
unnamed: IC22.5 (Y), J2.5
OUT: C57.2, IC15.3 (OUT), J8.2
RX_IN: IC22.2 (RO); also elsewhere on the board
TX_OUT: IC22.3 (DI); also elsewhere on the board

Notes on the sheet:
Mounting Hardware
Power entry and fan
Alternate 5v supply
Data input
7x7 LED board

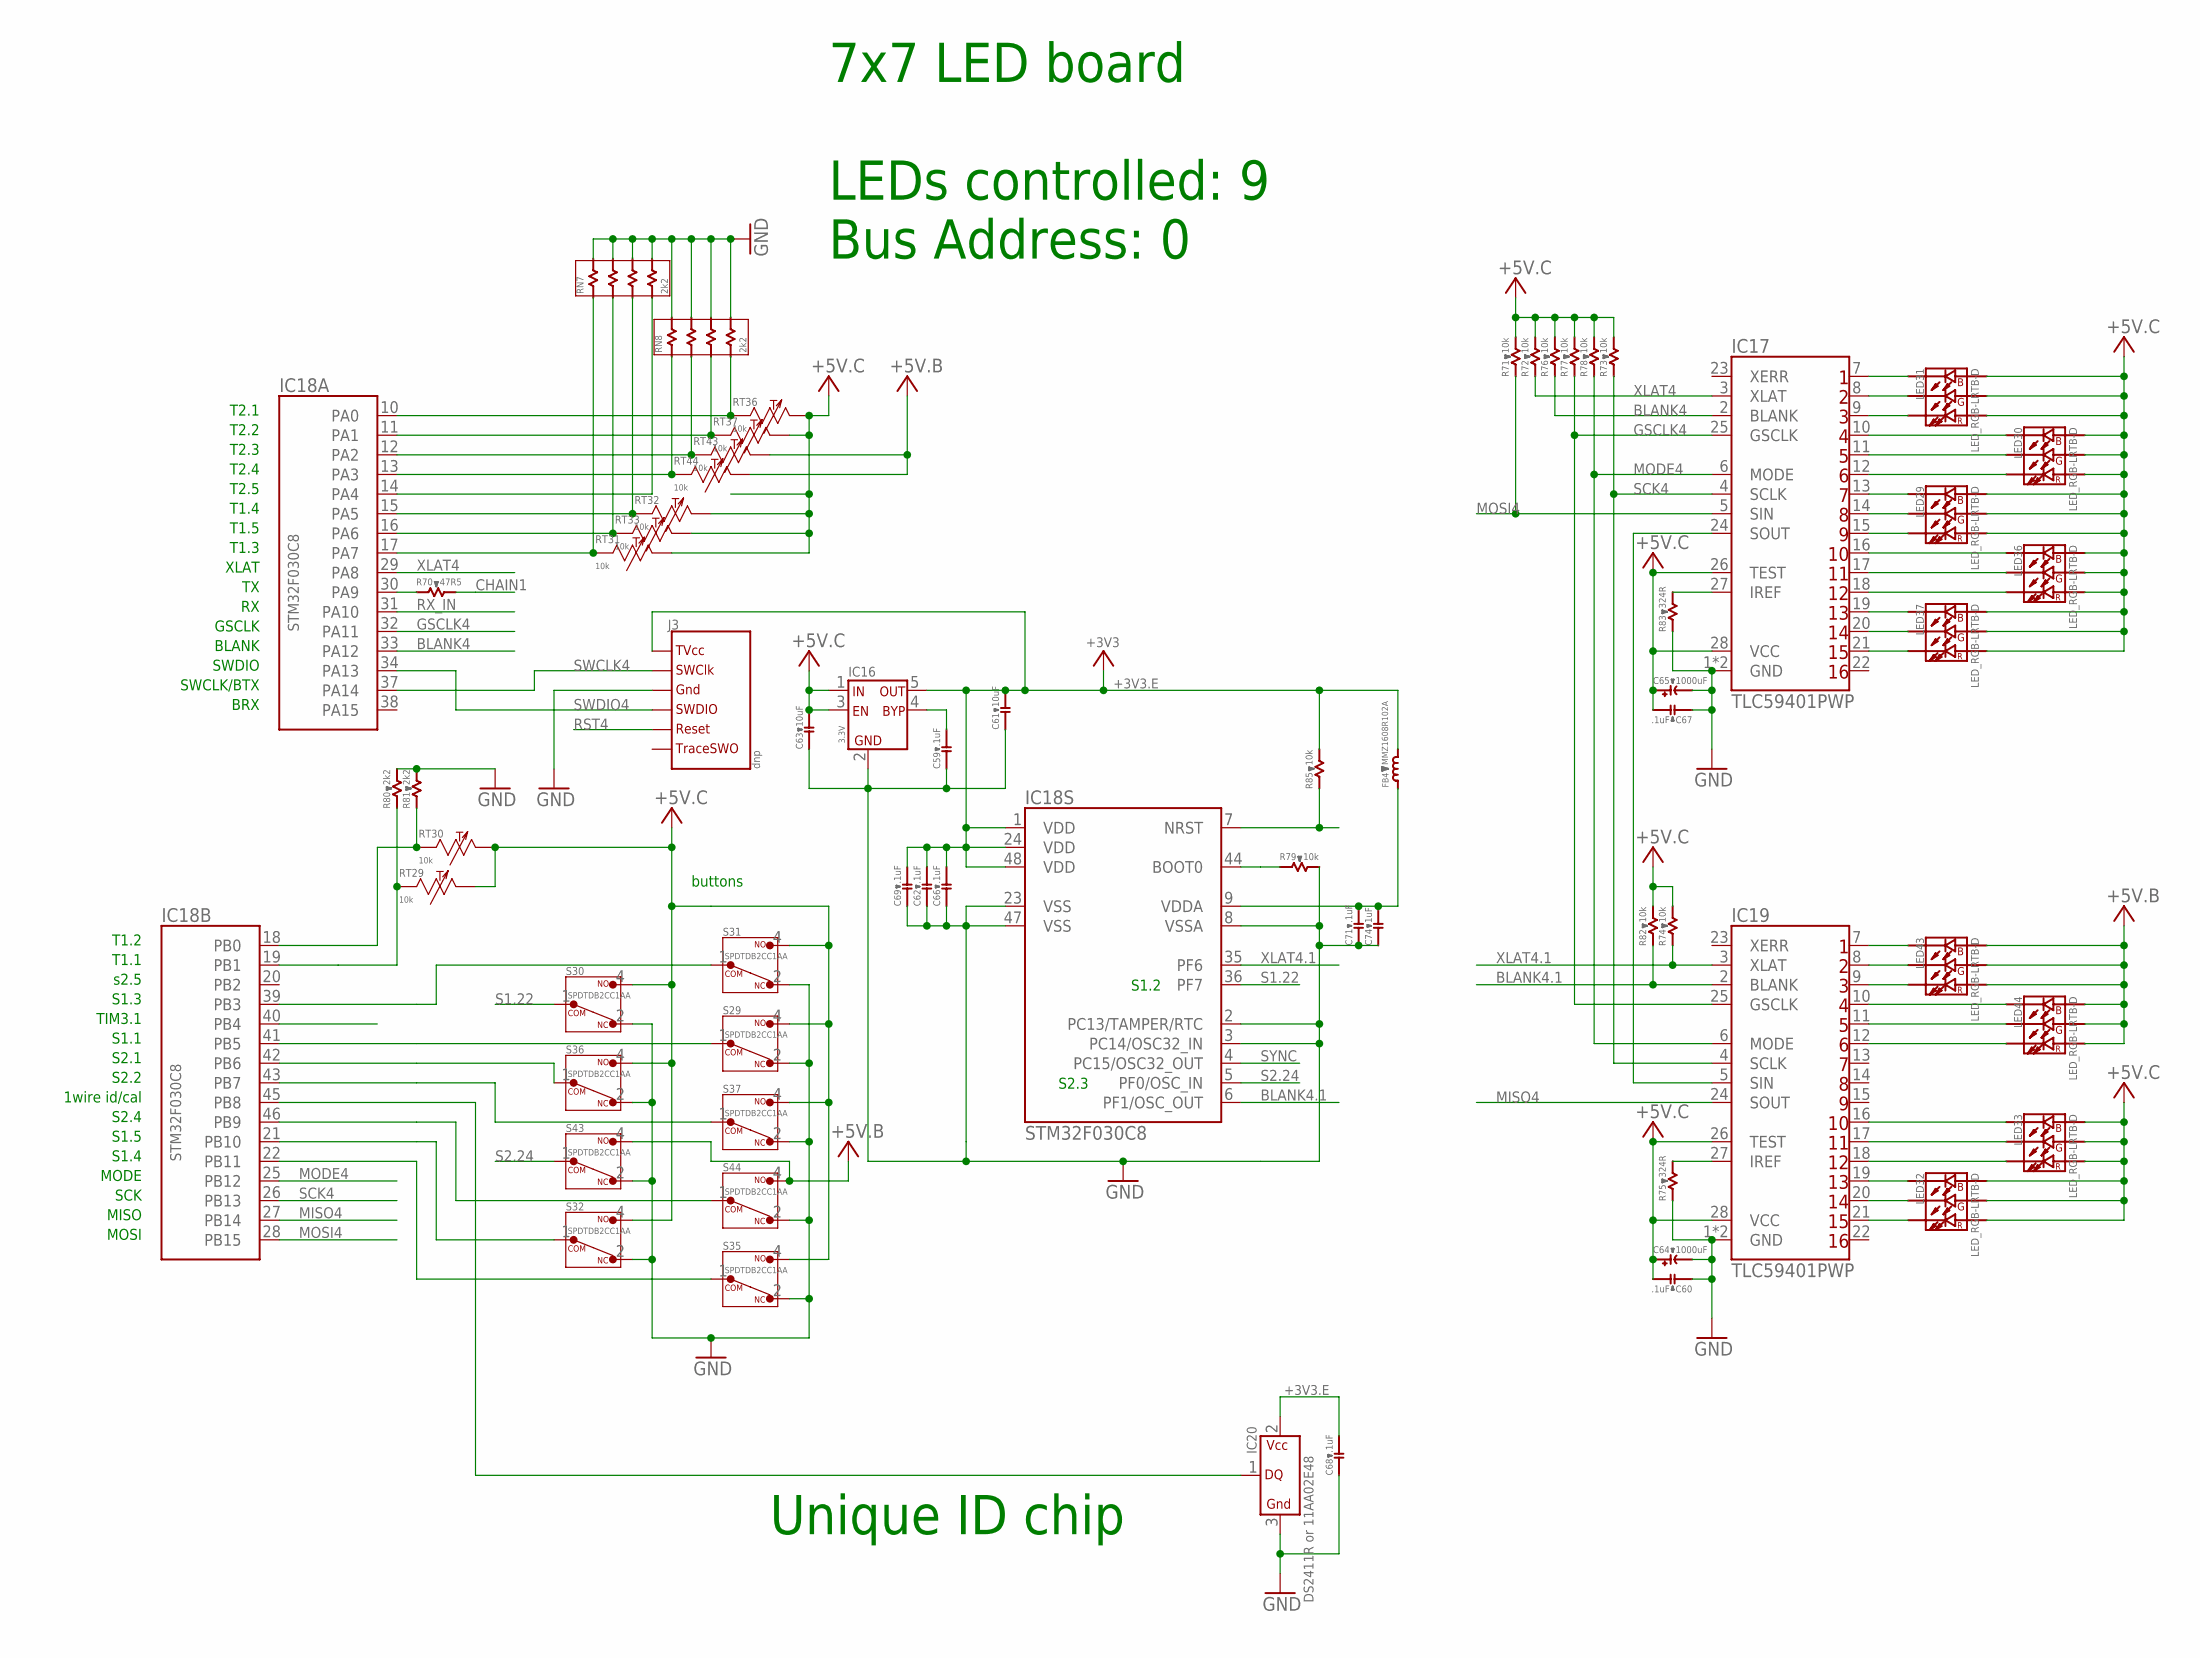
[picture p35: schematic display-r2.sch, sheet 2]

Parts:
C59, C60, C62, C66, C67, C68, C69, C71: .1uF; C0603B; PARTNO CGA3E2X7R1H104K080AA
C61, C63: 10uF; C0603B; PARTNO C1608X6S1A106M080AC
C64, C65: 1000uF; E5-10,5; PARTNO EKZN160ELL102MJ16S
C74: 1uF; C0603B; PARTNO CGA3E3X5R1H105K080AB
FB4: MMZ1608R102A; R0603B; PARTNO MMZ1608R102A
IC16: 3.3V; SOT-23-5; PARTNO TC2185-3.3VCTTR
IC17, IC19: TLC59401PWP; TSSOP28_PAD; PARTNO TLC59401PWPR
IC18: STM32F030C8; LQFP-48; PARTNO STM32F030C8T6
IC20: DS2411R or 11AA02E48; SOT-23; PARTNO 11AA02E48T-I/TT
J3: dnp; TC2030-IDC-NL
LED29, LED30, LED31, LED32, LED33, LED36, LED37, LED43, LED44: LED_RGB-LRTB-D; LRTB_C9TP-D; PARTNO LRTBC9TP-CWD5-1+D5E7-25+A
R70: 47R5; R0603B; PARTNO CRCW060347R5FKEA
R71, R72, R73, R74, R76, R77, R78, R79, R82, R85: 10k; R0603B; PARTNO CRCW060310K0FKEA
R75, R83: 324R; R0603B; PARTNO CRCW0603324RFKEA
R80, R81: 2k2; R0603B; PARTNO CRCW06032K20FKEA
RN7, RN8: 2k2; CAY16; PARTNO CAY16-2201F4LF
RT29, RT30, RT31, RT32, RT33, RT36, RT37, RT43, RT44: 10k; R0603Y; PARTNO NCP18XH103F03RB
S29, S30, S31, S32, S35, S36, S37, S43, S44: SPDTDB2CC1AA; DB2CC1AA; PARTNO DB2CC1AA

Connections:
+3V3.E: C61.2, C62.2, C66.2, C68.2, C69.2, FB4.2, IC16.5 (OUT), IC18.1 (VDD), IC18.24 (VDD), IC18.48 (VDD), IC20.2 (VCC), J3.1 (TVCC), R85.2
+5VB: LED43.A1 (ANODE_R), LED43.A2 (ANODE_G), LED43.A3 (ANODE_B), LED44.A1 (ANODE_R), LED44.A2 (ANODE_G), LED44.A3 (ANODE_B), RT43.2, RT44.2, S43.4 (NO), S44.4 (NO); also elsewhere on the board
+5VC: C60.2, C63.2, C64.+, C65.+, C67.2, IC16.1 (IN), IC16.3 (EN), IC17.26 (TEST), IC17.28 (VCC), IC19.26 (TEST), IC19.28 (VCC), LED29.A1 (ANODE_R), LED29.A2 (ANODE_G), LED29.A3 (ANODE_B), LED30.A1 (ANODE_R), LED30.A2 (ANODE_G), LED30.A3 (ANODE_B), LED31.A1 (ANODE_R), LED31.A2 (ANODE_G), LED31.A3 (ANODE_B), LED32.A1 (ANODE_R), LED32.A2 (ANODE_G), LED32.A3 (ANODE_B), LED33.A1 (ANODE_R), LED33.A2 (ANODE_G), LED33.A3 (ANODE_B), LED36.A1 (ANODE_R), LED36.A2 (ANODE_G), LED36.A3 (ANODE_B), LED37.A1 (ANODE_R), LED37.A2 (ANODE_G), LED37.A3 (ANODE_B), R71.2, R72.2, R73.2, R74.2, R76.2, R77.2, R78.2, R82.2, RT29.2, RT30.2, RT31.2, RT32.2, RT33.2, RT36.2, RT37.2, S29.4 (NO), S30.4 (NO), S31.4 (NO), S32.4 (NO), S35.4 (NO), S36.4 (NO), S37.4 (NO); also elsewhere on the board
BLANK4: IC17.2 (BLANK), IC18.33 (PA12), R76.1
BLANK4.1: IC18.6 (PF1/OSC_OUT), IC19.2 (BLANK), R82.1
CHAIN1: R70.2; also elsewhere on the board
GND: C59.1, C60.1, C61.1, C62.1, C63.1, C64.-, C65.-, C66.1, C67.1, C68.1, C69.1, C71.1, C74.1, IC16.2 (GND), IC17.1 (GND), IC17.PAD (GND), IC18.2 (PC13/TAMPER/RTC), IC18.3 (PC14/OSC32_IN), IC18.8 (VSSA), IC18.23 (VSS), IC18.47 (VSS), IC19.1 (GND), IC19.PAD (GND), IC20.3 (GND), J3.5 (GND), R75.1, R79.2, R80.2, R81.2, R83.1, RN7.A2, RN7.B2, RN7.C2, RN7.D2, RN8.A2, RN8.B2, RN8.C2, RN8.D2, S29.2 (NC), S30.2 (NC), S31.2 (NC), S32.2 (NC), S35.2 (NC), S36.2 (NC), S37.2 (NC), S43.2 (NC), S44.2 (NC); also elsewhere on the board
GSCLK4: IC17.25 (GSCLK), IC18.32 (PA11), IC19.25 (GSCLK), R77.1
MISO4: IC18.27 (PB14), IC19.24 (SOUT)
MODE4: IC17.6 (MODE), IC18.25 (PB12), IC19.6 (MODE), R78.1
MOSI4: IC17.5 (SIN), IC18.28 (PB15), R71.1
unnamed: IC18.44 (BOOT0), R79.1
unnamed: C71.2, C74.2, FB4.1, IC18.9 (VDDA)
unnamed: C59.2, IC16.4 (BYPASS)
unnamed: IC17.24 (SOUT), IC19.5 (SIN)
unnamed: IC19.27 (IREF), R75.2
unnamed: IC17.27 (IREF), R83.2
unnamed: IC17.7 (OUT1), LED31.C3 (CATHODE_B)
unnamed: IC17.8 (OUT2), LED31.C2 (CATHODE_G)
unnamed: IC17.9 (OUT3), LED31.C1 (CATHODE_R)
unnamed: IC17.10 (OUT4), LED30.C3 (CATHODE_B)
unnamed: IC17.11 (OUT5), LED30.C2 (CATHODE_G)
unnamed: IC17.12 (OUT6), LED30.C1 (CATHODE_R)
unnamed: IC17.13 (OUT7), LED29.C3 (CATHODE_B)
unnamed: IC17.14 (OUT8), LED29.C2 (CATHODE_G)
unnamed: IC17.15 (OUT9), LED29.C1 (CATHODE_R)
unnamed: IC17.16 (OUT10), LED36.C3 (CATHODE_B)
unnamed: IC17.17 (OUT11), LED36.C2 (CATHODE_G)
unnamed: IC17.18 (OUT12), LED36.C1 (CATHODE_R)
unnamed: IC17.19 (OUT13), LED37.C3 (CATHODE_B)
unnamed: IC17.20 (OUT14), LED37.C2 (CATHODE_G)
unnamed: IC17.21 (OUT15), LED37.C1 (CATHODE_R)
unnamed: IC19.7 (OUT1), LED43.C3 (CATHODE_B)
unnamed: IC19.8 (OUT2), LED43.C2 (CATHODE_G)
unnamed: IC19.9 (OUT3), LED43.C1 (CATHODE_R)
unnamed: IC19.10 (OUT4), LED44.C3 (CATHODE_B)
unnamed: IC19.11 (OUT5), LED44.C2 (CATHODE_G)
unnamed: IC19.12 (OUT6), LED44.C1 (CATHODE_R)
unnamed: IC19.16 (OUT10), LED33.C3 (CATHODE_B)
unnamed: IC19.17 (OUT11), LED33.C2 (CATHODE_G)
unnamed: IC19.18 (OUT12), LED33.C1 (CATHODE_R)
unnamed: IC19.19 (OUT13), LED32.C3 (CATHODE_B)
unnamed: IC19.20 (OUT14), LED32.C2 (CATHODE_G)
unnamed: IC19.21 (OUT15), LED32.C1 (CATHODE_R)
unnamed: IC18.30 (PA9), R70.1
RST4: IC18.7 (NRST), J3.3 (RESET), R85.1
RX_IN: IC18.31 (PA10); also elsewhere on the board
S1.21: IC18.39 (PB3), S31.1 (COM)
S1.22: IC18.36 (PF7), S30.1 (COM)
S1.23: IC18.41 (PB5), S29.1 (COM)
S1.24: IC18.21 (PB10), S32.1 (COM)
S1.25: IC18.22 (PB11), S35.1 (COM)
S2.22: IC18.42 (PB6), S36.1 (COM)
S2.23: IC18.43 (PB7), S37.1 (COM)
S2.24: IC18.5 (PF0/OSC_IN), S43.1 (COM)
S2.25: IC18.46 (PB9), S44.1 (COM)
SCK4: IC17.4 (SCLK), IC18.26 (PB13), IC19.4 (SCLK), R73.1
SWCLK4: IC18.37 (PA14), J3.4 (SWCLK)
SWDIO4: IC18.34 (PA13), J3.2 (SWDIO)
SYNC: IC18.4 (PC15/OSC32_OUT); also elsewhere on the board
T41: IC18.14 (PA4), RN7.D1
T42: IC18.15 (PA5), RN7.C1, RT32.1
T43: IC18.16 (PA6), RN7.B1, RT33.1
T44: IC18.17 (PA7), RN7.A1, RT31.1
T45: IC18.18 (PB0), R81.1, RT30.1
T46: IC18.19 (PB1), R80.1, RT29.1
T47: IC18.13 (PA3), RN8.A1, RT44.1
T48: IC18.12 (PA2), RN8.B1, RT43.1
T49: IC18.11 (PA1), RN8.C1, RT37.1
T50: IC18.10 (PA0), RN8.D1, RT36.1
TIM3.5: IC18.40 (PB4)
TIM16.5: IC18.45 (PB8), IC20.1 (DQ)
XLAT4: IC17.3 (XLAT), IC18.29 (PA8), R72.1
XLAT4.1: IC18.35 (PF6), IC19.3 (XLAT), R74.1

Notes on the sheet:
buttons
s2.5
S1.3
TIM3.1
S1.1
S2.1
S2.2
1wire id/cal
S2.4
S1.5
S1.4
T1.1
T1.2
MODE
SCK
MISO
MOSI
T2.1
T2.2
T2.3
T2.4
T2.5
T1.4
T1.5
T1.3
XLAT
GSCLK
BLANK
SWDIO
SWCLK/BTX
BRX
S1.2
S2.3
LEDs controlled: 9 Bus Address: 0
Unique ID chip
7x7 LED board

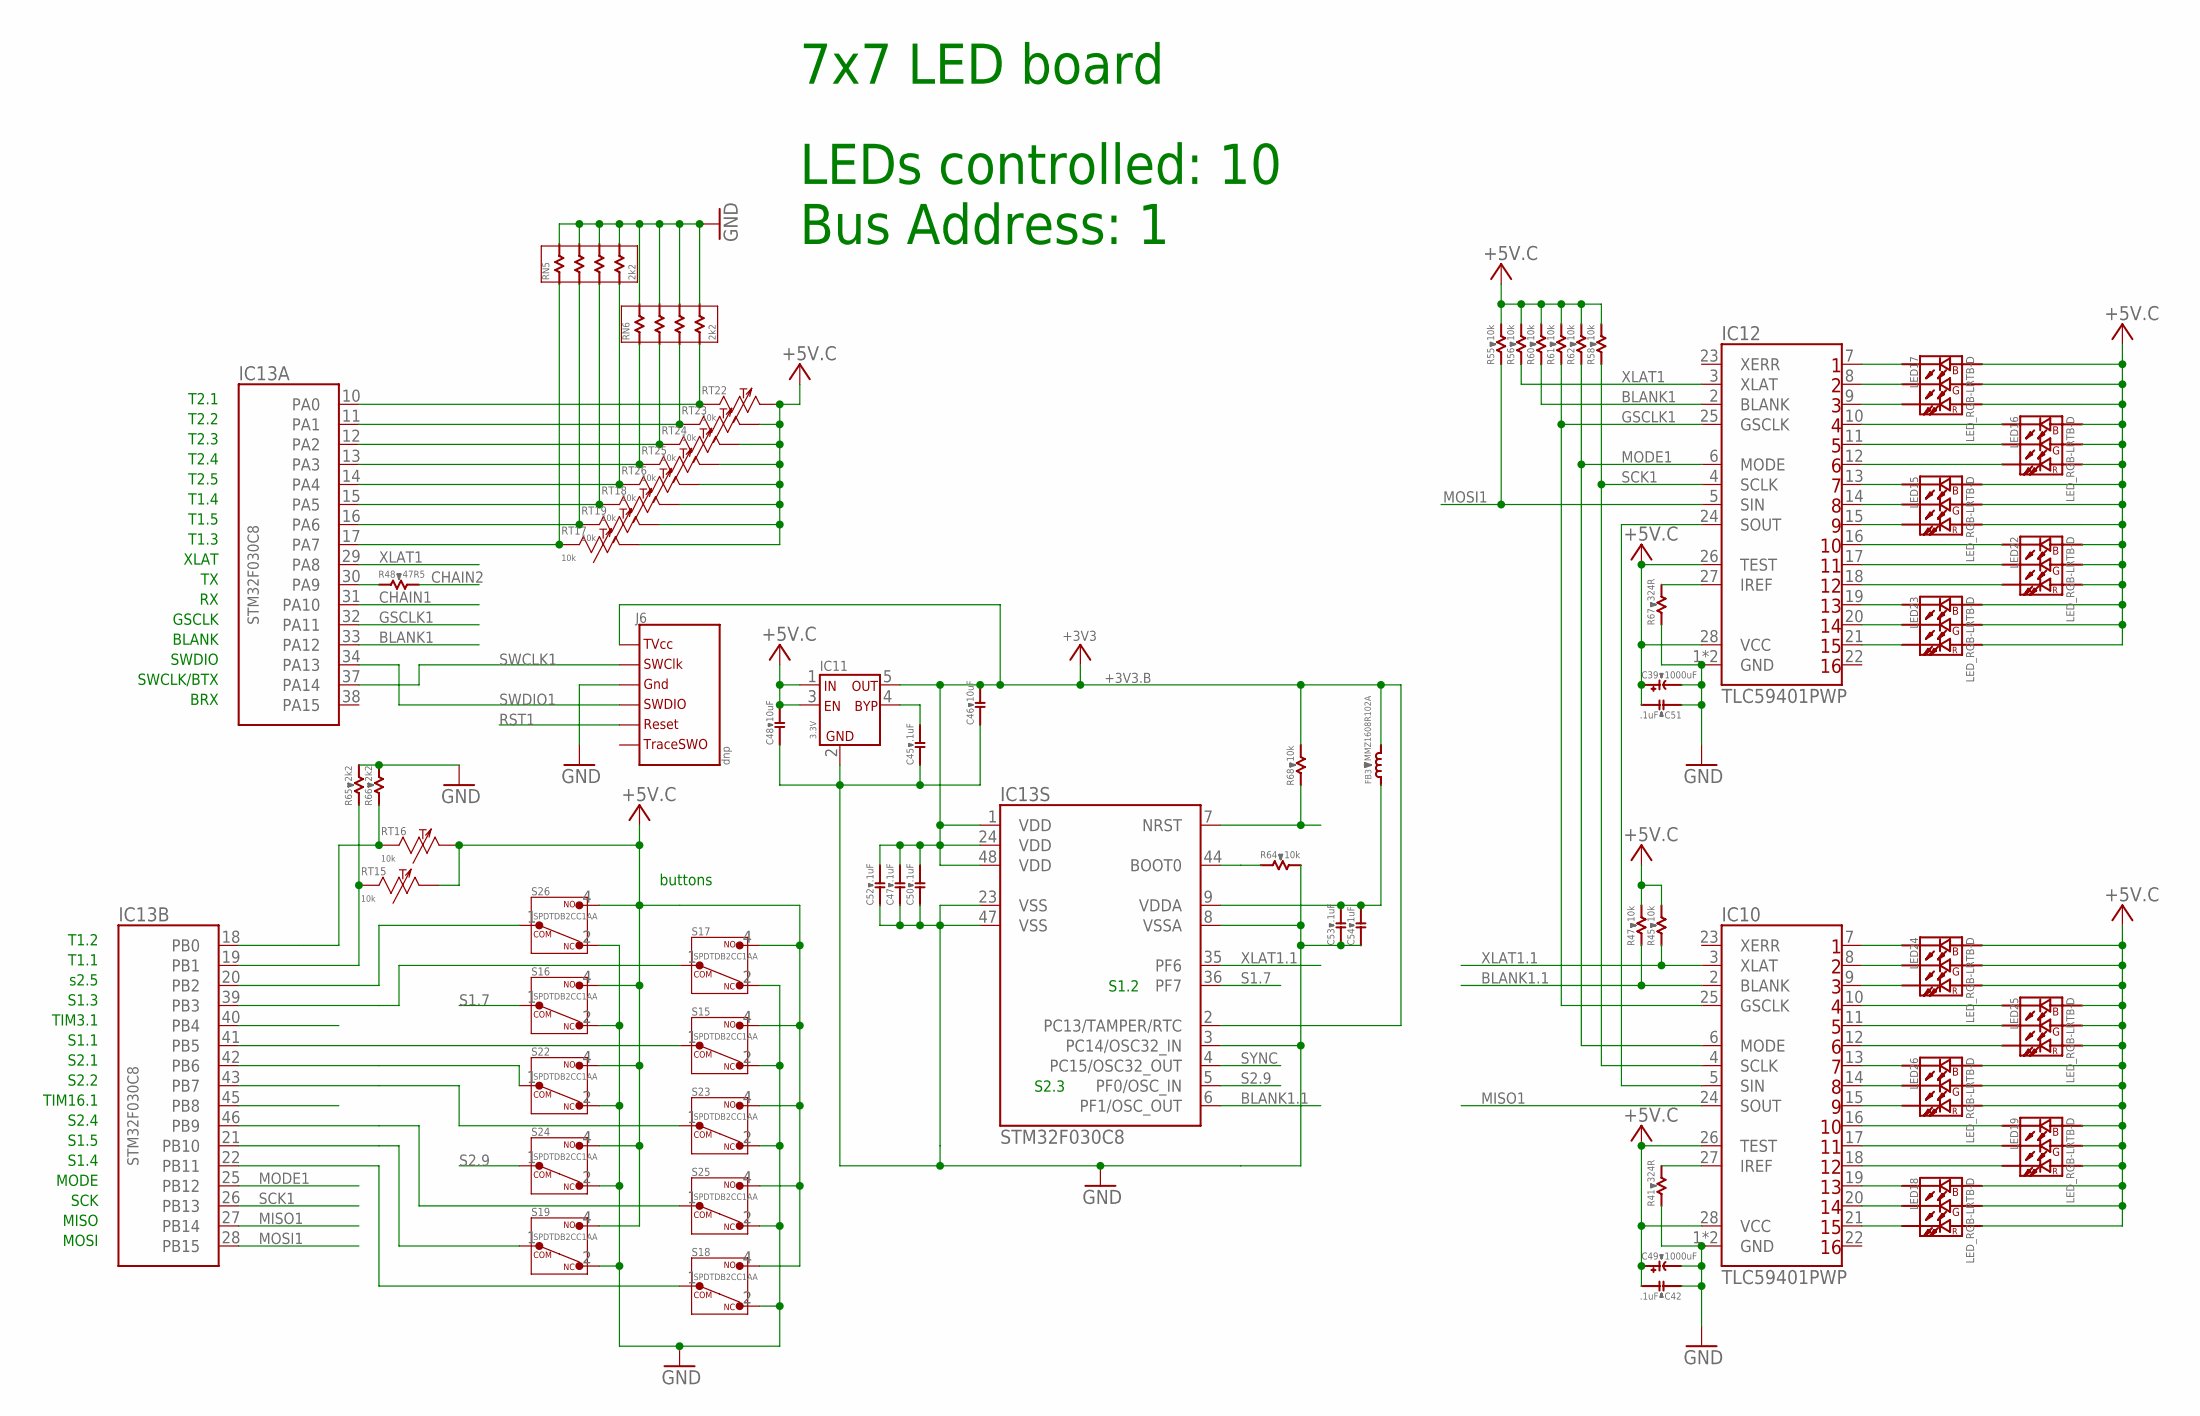
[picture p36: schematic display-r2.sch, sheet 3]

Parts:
C39, C49: 1000uF; E5-10,5; PARTNO EKZN160ELL102MJ16S
C42, C45, C47, C50, C51, C52, C53: .1uF; C0603B; PARTNO CGA3E2X7R1H104K080AA
C46, C48: 10uF; C0603B; PARTNO C1608X6S1A106M080AC
C54: 1uF; C0603B; PARTNO CGA3E3X5R1H105K080AB
FB3: MMZ1608R102A; R0603B; PARTNO MMZ1608R102A
IC10, IC12: TLC59401PWP; TSSOP28_PAD; PARTNO TLC59401PWPR
IC11: 3.3V; SOT-23-5; PARTNO TC2185-3.3VCTTR
IC13: STM32F030C8; LQFP-48; PARTNO STM32F030C8T6
J6: dnp; TC2030-IDC-NL
LED15, LED16, LED17, LED18, LED19, LED22, LED23, LED24, LED25, LED26: LED_RGB-LRTB-D; LRTB_C9TP-D; PARTNO LRTBC9TP-CWD5-1+D5E7-25+A
R41, R67: 324R; R0603B; PARTNO CRCW0603324RFKEA
R45, R47, R55, R56, R58, R60, R61, R62, R64, R68: 10k; R0603B; PARTNO CRCW060310K0FKEA
R48: 47R5; R0603B; PARTNO CRCW060347R5FKEA
R65, R66: 2k2; R0603B; PARTNO CRCW06032K20FKEA
RN5, RN6: 2k2; CAY16; PARTNO CAY16-2201F4LF
RT15, RT16, RT17, RT18, RT19, RT22, RT23, RT24, RT25, RT26: 10k; R0603Y; PARTNO NCP18XH103F03RB
S15, S16, S17, S18, S19, S22, S23, S24, S25, S26: SPDTDB2CC1AA; DB2CC1AA; PARTNO DB2CC1AA

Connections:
+3V3.B: C46.2, C47.2, C50.2, C52.2, FB3.2, IC11.5 (OUT), IC13.1 (VDD), IC13.2 (PC13/TAMPER/RTC), IC13.24 (VDD), IC13.48 (VDD), J6.1 (TVCC), R68.2
+5VC: C39.+, C42.2, C48.2, C49.+, C51.2, IC10.26 (TEST), IC10.28 (VCC), IC11.1 (IN), IC11.3 (EN), IC12.26 (TEST), IC12.28 (VCC), LED15.A1 (ANODE_R), LED15.A2 (ANODE_G), LED15.A3 (ANODE_B), LED16.A1 (ANODE_R), LED16.A2 (ANODE_G), LED16.A3 (ANODE_B), LED17.A1 (ANODE_R), LED17.A2 (ANODE_G), LED17.A3 (ANODE_B), LED18.A1 (ANODE_R), LED18.A2 (ANODE_G), LED18.A3 (ANODE_B), LED19.A1 (ANODE_R), LED19.A2 (ANODE_G), LED19.A3 (ANODE_B), LED22.A1 (ANODE_R), LED22.A2 (ANODE_G), LED22.A3 (ANODE_B), LED23.A1 (ANODE_R), LED23.A2 (ANODE_G), LED23.A3 (ANODE_B), LED24.A1 (ANODE_R), LED24.A2 (ANODE_G), LED24.A3 (ANODE_B), LED25.A1 (ANODE_R), LED25.A2 (ANODE_G), LED25.A3 (ANODE_B), LED26.A1 (ANODE_R), LED26.A2 (ANODE_G), LED26.A3 (ANODE_B), R45.2, R47.2, R55.2, R56.2, R58.2, R60.2, R61.2, R62.2, RT15.2, RT16.2, RT17.2, RT18.2, RT19.2, RT22.2, RT23.2, RT24.2, RT25.2, RT26.2, S15.4 (NO), S16.4 (NO), S17.4 (NO), S18.4 (NO), S19.4 (NO), S22.4 (NO), S23.4 (NO), S24.4 (NO), S25.4 (NO), S26.4 (NO); also elsewhere on the board
BLANK1: IC12.2 (BLANK), IC13.33 (PA12), R60.1
BLANK1.1: IC10.2 (BLANK), IC13.6 (PF1/OSC_OUT), R47.1
CHAIN1: IC13.31 (PA10); also elsewhere on the board
CHAIN2: R48.2; also elsewhere on the board
GND: C39.-, C42.1, C45.1, C46.1, C47.1, C48.1, C49.-, C50.1, C51.1, C52.1, C53.1, C54.1, IC10.1 (GND), IC10.PAD (GND), IC11.2 (GND), IC12.1 (GND), IC12.PAD (GND), IC13.3 (PC14/OSC32_IN), IC13.8 (VSSA), IC13.23 (VSS), IC13.47 (VSS), J6.5 (GND), R41.1, R64.2, R65.2, R66.2, R67.1, RN5.A2, RN5.B2, RN5.C2, RN5.D2, RN6.A2, RN6.B2, RN6.C2, RN6.D2, S15.2 (NC), S16.2 (NC), S17.2 (NC), S18.2 (NC), S19.2 (NC), S22.2 (NC), S23.2 (NC), S24.2 (NC), S25.2 (NC), S26.2 (NC); also elsewhere on the board
GSCLK1: IC10.25 (GSCLK), IC12.25 (GSCLK), IC13.32 (PA11), R61.1
MISO1: IC10.24 (SOUT), IC13.27 (PB14)
MODE1: IC10.6 (MODE), IC12.6 (MODE), IC13.25 (PB12), R62.1
MOSI1: IC12.5 (SIN), IC13.28 (PB15), R55.1
unnamed: IC13.44 (BOOT0), R64.1
unnamed: C53.2, C54.2, FB3.1, IC13.9 (VDDA)
unnamed: C45.2, IC11.4 (BYPASS)
unnamed: IC10.5 (SIN), IC12.24 (SOUT)
unnamed: IC10.27 (IREF), R41.2
unnamed: IC12.27 (IREF), R67.2
unnamed: IC12.7 (OUT1), LED17.C3 (CATHODE_B)
unnamed: IC12.8 (OUT2), LED17.C2 (CATHODE_G)
unnamed: IC12.9 (OUT3), LED17.C1 (CATHODE_R)
unnamed: IC12.10 (OUT4), LED16.C3 (CATHODE_B)
unnamed: IC12.11 (OUT5), LED16.C2 (CATHODE_G)
unnamed: IC12.12 (OUT6), LED16.C1 (CATHODE_R)
unnamed: IC12.13 (OUT7), LED15.C3 (CATHODE_B)
unnamed: IC12.14 (OUT8), LED15.C2 (CATHODE_G)
unnamed: IC12.15 (OUT9), LED15.C1 (CATHODE_R)
unnamed: IC12.16 (OUT10), LED22.C3 (CATHODE_B)
unnamed: IC12.17 (OUT11), LED22.C2 (CATHODE_G)
unnamed: IC12.18 (OUT12), LED22.C1 (CATHODE_R)
unnamed: IC12.19 (OUT13), LED23.C3 (CATHODE_B)
unnamed: IC12.20 (OUT14), LED23.C2 (CATHODE_G)
unnamed: IC12.21 (OUT15), LED23.C1 (CATHODE_R)
unnamed: IC10.7 (OUT1), LED24.C3 (CATHODE_B)
unnamed: IC10.8 (OUT2), LED24.C2 (CATHODE_G)
unnamed: IC10.9 (OUT3), LED24.C1 (CATHODE_R)
unnamed: IC10.10 (OUT4), LED25.C3 (CATHODE_B)
unnamed: IC10.11 (OUT5), LED25.C2 (CATHODE_G)
unnamed: IC10.12 (OUT6), LED25.C1 (CATHODE_R)
unnamed: IC10.13 (OUT7), LED26.C3 (CATHODE_B)
unnamed: IC10.14 (OUT8), LED26.C2 (CATHODE_G)
unnamed: IC10.15 (OUT9), LED26.C1 (CATHODE_R)
unnamed: IC10.16 (OUT10), LED19.C3 (CATHODE_B)
unnamed: IC10.17 (OUT11), LED19.C2 (CATHODE_G)
unnamed: IC10.18 (OUT12), LED19.C1 (CATHODE_R)
unnamed: IC10.19 (OUT13), LED18.C3 (CATHODE_B)
unnamed: IC10.20 (OUT14), LED18.C2 (CATHODE_G)
unnamed: IC10.21 (OUT15), LED18.C1 (CATHODE_R)
unnamed: IC13.30 (PA9), R48.1
RST1: IC13.7 (NRST), J6.3 (RESET), R68.1
S1.6: IC13.39 (PB3), S17.1 (COM)
S1.7: IC13.36 (PF7), S16.1 (COM)
S1.8: IC13.41 (PB5), S15.1 (COM)
S1.9: IC13.21 (PB10), S19.1 (COM)
S1.10: IC13.22 (PB11), S18.1 (COM)
S2.6: IC13.20 (PB2), S26.1 (COM)
S2.7: IC13.42 (PB6), S22.1 (COM)
S2.8: IC13.43 (PB7), S23.1 (COM)
S2.9: IC13.5 (PF0/OSC_IN), S24.1 (COM)
S2.10: IC13.46 (PB9), S25.1 (COM)
SCK1: IC10.4 (SCLK), IC12.4 (SCLK), IC13.26 (PB13), R58.1
SWCLK1: IC13.37 (PA14), J6.4 (SWCLK)
SWDIO1: IC13.34 (PA13), J6.2 (SWDIO)
SYNC: IC13.4 (PC15/OSC32_OUT); also elsewhere on the board
T11: IC13.14 (PA4), RN5.D1, RT26.1
T12: IC13.15 (PA5), RN5.C1, RT18.1
T13: IC13.16 (PA6), RN5.B1, RT19.1
T14: IC13.17 (PA7), RN5.A1, RT17.1
T15: IC13.18 (PB0), R66.1, RT16.1
T16: IC13.19 (PB1), R65.1, RT15.1
T17: IC13.13 (PA3), RN6.A1, RT25.1
T18: IC13.12 (PA2), RN6.B1, RT24.1
T19: IC13.11 (PA1), RN6.C1, RT23.1
T20: IC13.10 (PA0), RN6.D1, RT22.1
TIM3.2: IC13.40 (PB4)
TIM16.2: IC13.45 (PB8)
XLAT1: IC12.3 (XLAT), IC13.29 (PA8), R56.1
XLAT1.1: IC10.3 (XLAT), IC13.35 (PF6), R45.1

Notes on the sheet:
buttons
s2.5
S1.3
TIM3.1
S1.1
S2.1
S2.2
TIM16.1
S2.4
S1.5
S1.4
T1.1
T1.2
MODE
SCK
MISO
MOSI
T2.1
T2.2
T2.3
T2.4
T2.5
T1.4
T1.5
T1.3
XLAT
GSCLK
BLANK
SWDIO
SWCLK/BTX
BRX
S1.2
S2.3
LEDs controlled: 10 Bus Address: 1
7x7 LED board

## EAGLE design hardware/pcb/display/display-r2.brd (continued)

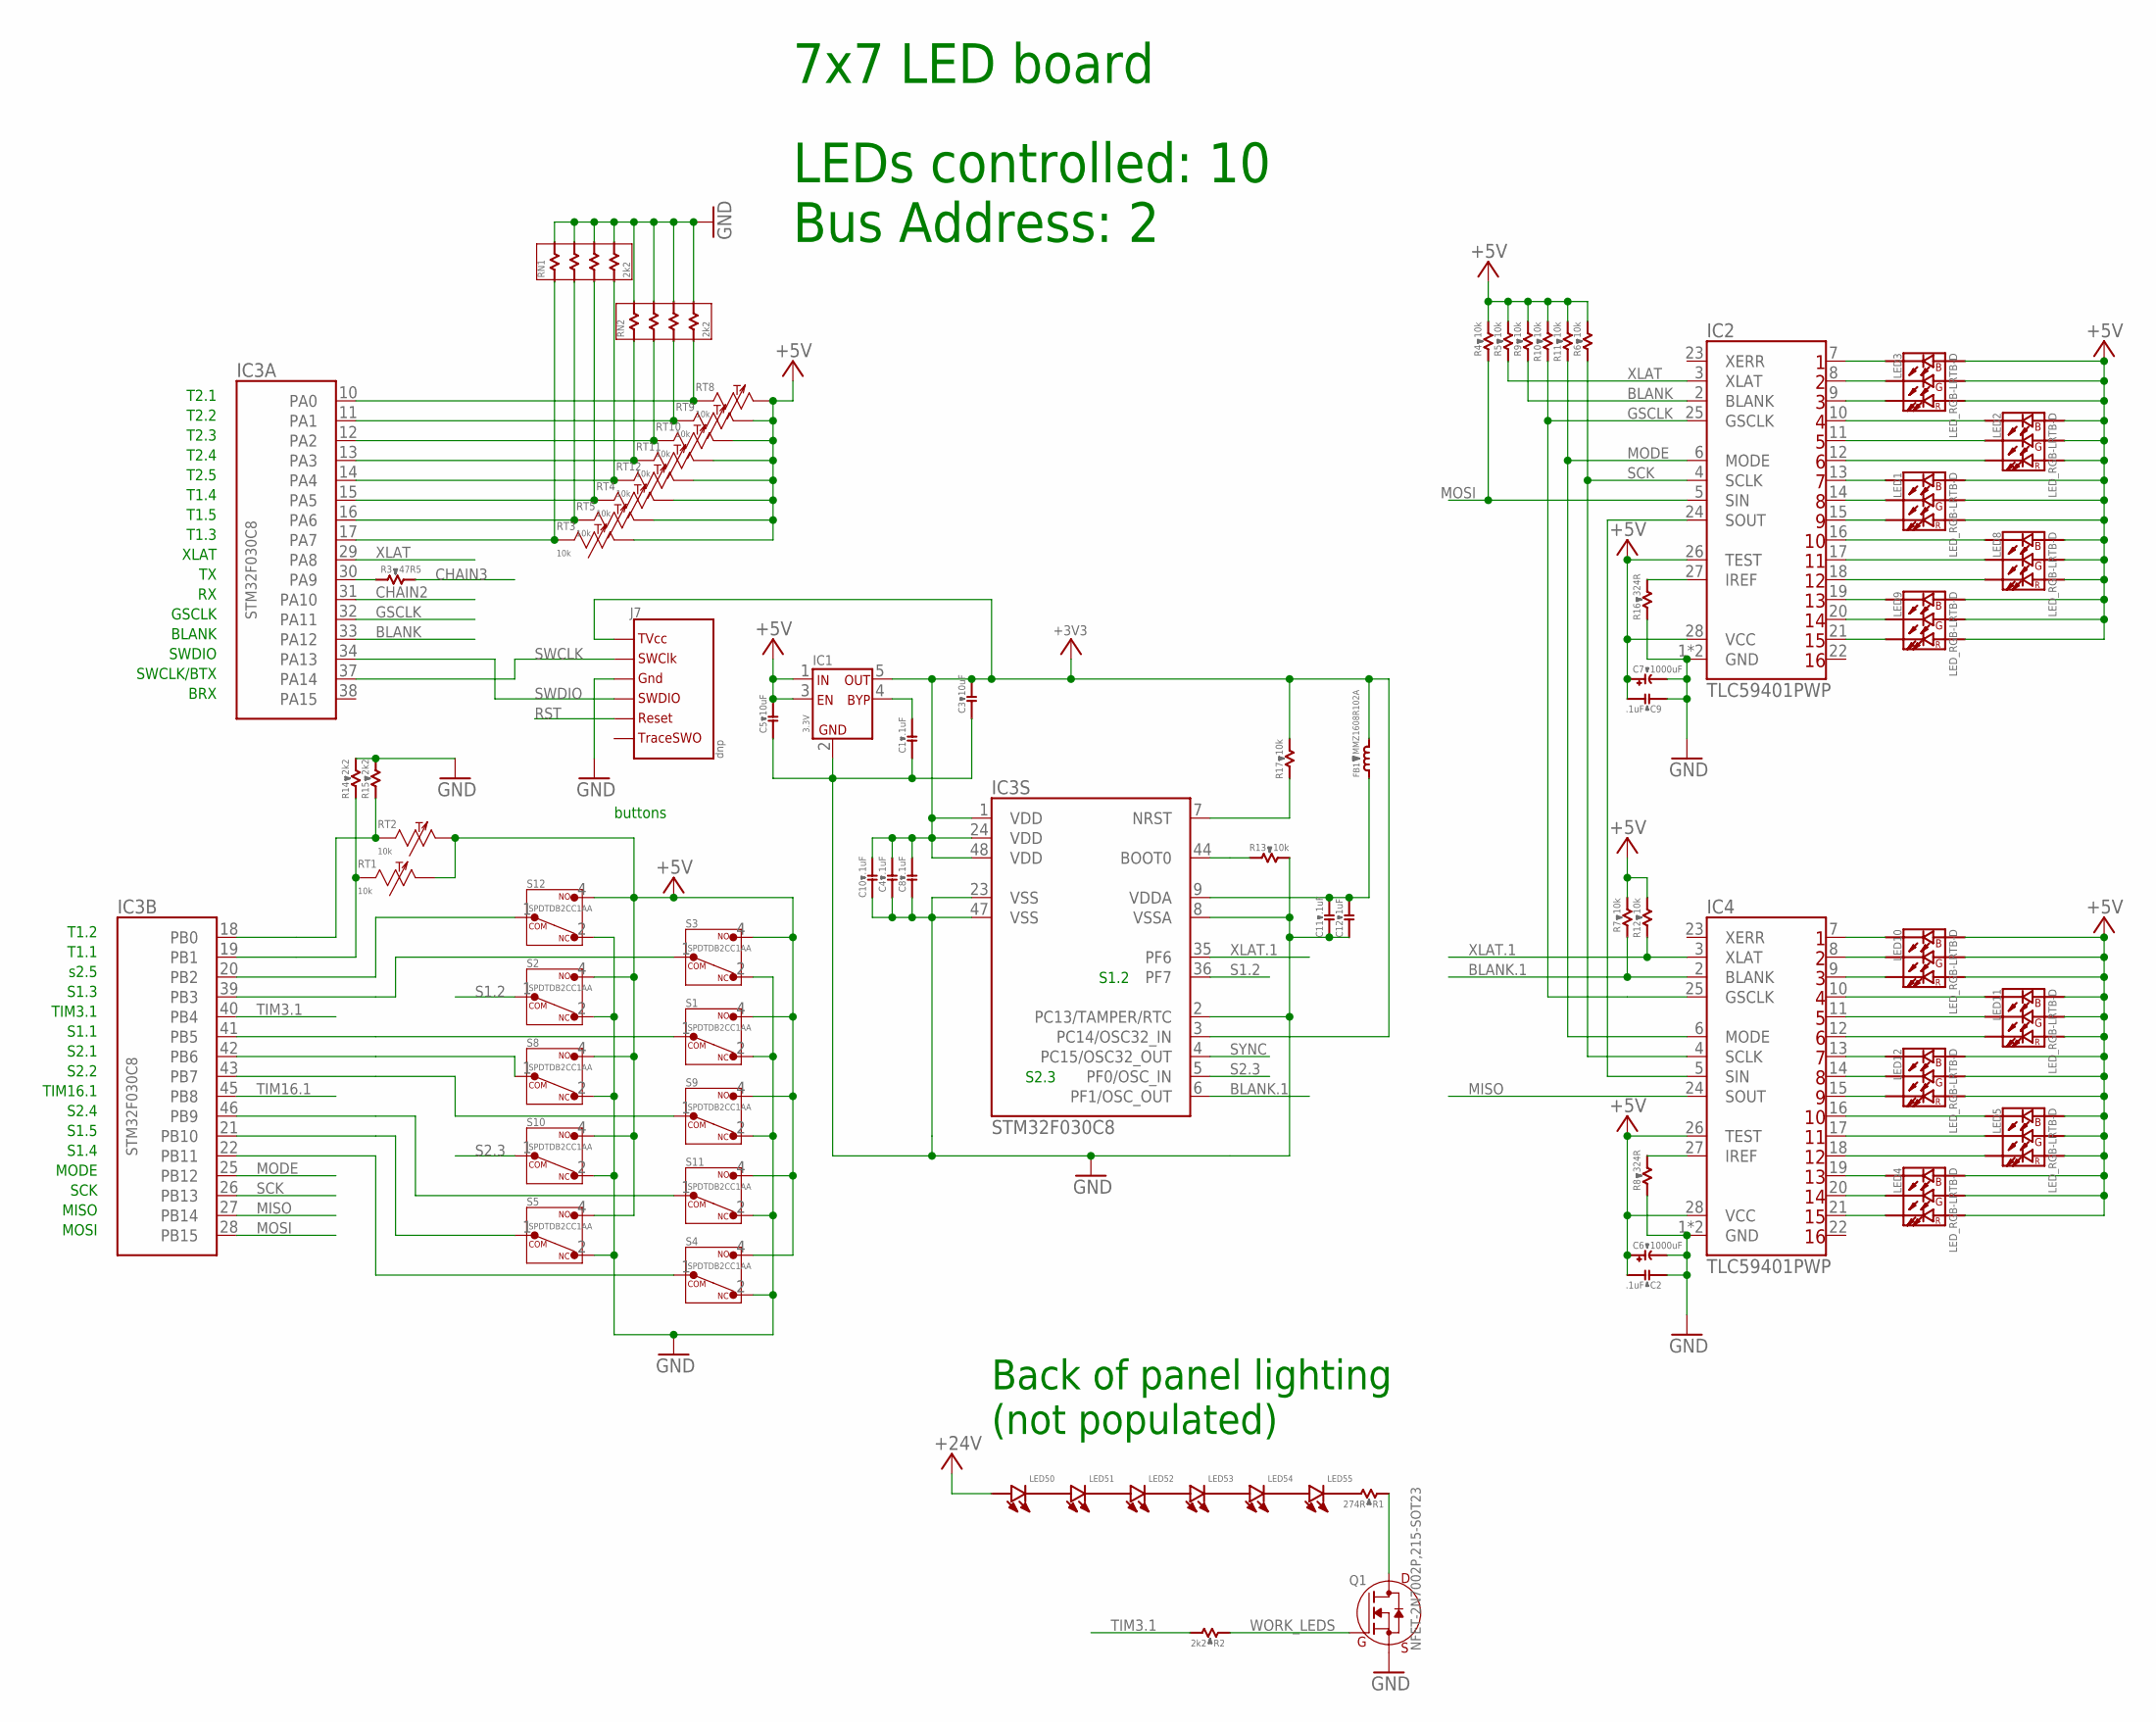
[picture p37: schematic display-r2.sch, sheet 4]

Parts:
C1, C2, C4, C8, C9, C10, C11: .1uF; C0603B; PARTNO CGA3E2X7R1H104K080AA
C3, C5: 10uF; C0603B; PARTNO C1608X6S1A106M080AC
C6, C7: 1000uF; E5-10,5; PARTNO EKZN160ELL102MJ16S
C12: 1uF; C0603B; PARTNO CGA3E3X5R1H105K080AB
FB1: MMZ1608R102A; R0603B; PARTNO MMZ1608R102A
IC1: 3.3V; SOT-23-5; PARTNO TC2185-3.3VCTTR
IC2, IC4: TLC59401PWP; TSSOP28_PAD; PARTNO TLC59401PWPR
IC3: STM32F030C8; LQFP-48; PARTNO STM32F030C8T6
J7: dnp; TC2030-IDC-NL
LED1, LED2, LED3, LED4, LED5, LED8, LED9, LED10, LED11, LED12: LED_RGB-LRTB-D; LRTB_C9TP-D; PARTNO LRTBC9TP-CWD5-1+D5E7-25+A
LED50, LED51, LED52, LED53, LED54, LED55: LED-LTW-006DCG; LTW-006DCG; PARTNO LTW-006DCG-E2
Q1: NFET-2N7002P,215-SOT23; SOT-23; PARTNO 2N7002P,215
R1: 274R; R0805B; PARTNO CRCW0805274RFKEA
R2, R14, R15: 2k2; R0603B; PARTNO CRCW06032K20FKEA
R3: 47R5; R0603B; PARTNO CRCW060347R5FKEA
R4, R5, R6, R7, R9, R10, R11, R12, R13, R17: 10k; R0603B; PARTNO CRCW060310K0FKEA
R8, R16: 324R; R0603B; PARTNO CRCW0603324RFKEA
RN1, RN2: 2k2; CAY16; PARTNO CAY16-2201F4LF
RT1, RT2, RT3, RT4, RT5, RT8, RT9, RT10, RT11, RT12: 10k; R0603Y; PARTNO NCP18XH103F03RB
S1, S2, S3, S4, S5, S8, S9, S10, S11, S12: SPDTDB2CC1AA; DB2CC1AA; PARTNO DB2CC1AA

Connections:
+3V3: C3.2, C4.2, C8.2, C10.2, FB1.2, IC1.5 (OUT), IC3.1 (VDD), IC3.3 (PC14/OSC32_IN), IC3.24 (VDD), IC3.48 (VDD), J7.1 (TVCC), R17.2
+5V: C2.2, C5.2, C6.+, C7.+, C9.2, IC1.1 (IN), IC1.3 (EN), IC2.26 (TEST), IC2.28 (VCC), IC4.26 (TEST), IC4.28 (VCC), LED1.A1 (ANODE_R), LED1.A2 (ANODE_G), LED1.A3 (ANODE_B), LED2.A1 (ANODE_R), LED2.A2 (ANODE_G), LED2.A3 (ANODE_B), LED3.A1 (ANODE_R), LED3.A2 (ANODE_G), LED3.A3 (ANODE_B), LED4.A1 (ANODE_R), LED4.A2 (ANODE_G), LED4.A3 (ANODE_B), LED5.A1 (ANODE_R), LED5.A2 (ANODE_G), LED5.A3 (ANODE_B), LED8.A1 (ANODE_R), LED8.A2 (ANODE_G), LED8.A3 (ANODE_B), LED9.A1 (ANODE_R), LED9.A2 (ANODE_G), LED9.A3 (ANODE_B), LED10.A1 (ANODE_R), LED10.A2 (ANODE_G), LED10.A3 (ANODE_B), LED11.A1 (ANODE_R), LED11.A2 (ANODE_G), LED11.A3 (ANODE_B), LED12.A1 (ANODE_R), LED12.A2 (ANODE_G), LED12.A3 (ANODE_B), R4.2, R5.2, R6.2, R7.2, R9.2, R10.2, R11.2, R12.2, RT1.2, RT2.2, RT3.2, RT4.2, RT5.2, RT8.2, RT9.2, RT10.2, RT11.2, RT12.2, S1.4 (NO), S2.4 (NO), S3.4 (NO), S4.4 (NO), S5.4 (NO), S8.4 (NO), S9.4 (NO), S10.4 (NO), S11.4 (NO), S12.4 (NO); also elsewhere on the board
+24V: LED50.A (ANODE); also elsewhere on the board
BLANK: IC2.2 (BLANK), IC3.33 (PA12), R9.1
BLANK.1: IC3.6 (PF1/OSC_OUT), IC4.2 (BLANK), R7.1
CHAIN2: IC3.31 (PA10); also elsewhere on the board
CHAIN3: R3.2; also elsewhere on the board
GND: C1.1, C2.1, C3.1, C4.1, C5.1, C6.-, C7.-, C8.1, C9.1, C10.1, C11.1, C12.1, IC1.2 (GND), IC2.1 (GND), IC2.PAD (GND), IC3.2 (PC13/TAMPER/RTC), IC3.8 (VSSA), IC3.23 (VSS), IC3.47 (VSS), IC4.1 (GND), IC4.PAD (GND), J7.5 (GND), Q1.2 (S), R8.1, R13.2, R14.2, R15.2, R16.1, RN1.A2, RN1.B2, RN1.C2, RN1.D2, RN2.A2, RN2.B2, RN2.C2, RN2.D2, S1.2 (NC), S2.2 (NC), S3.2 (NC), S4.2 (NC), S5.2 (NC), S8.2 (NC), S9.2 (NC), S10.2 (NC), S11.2 (NC), S12.2 (NC); also elsewhere on the board
GSCLK: IC2.25 (GSCLK), IC3.32 (PA11), IC4.25 (GSCLK), R10.1
MISO: IC3.27 (PB14), IC4.24 (SOUT)
MODE: IC2.6 (MODE), IC3.25 (PB12), IC4.6 (MODE), R11.1
MOSI: IC2.5 (SIN), IC3.28 (PB15), R4.1
unnamed: IC3.44 (BOOT0), R13.1
unnamed: IC2.7 (OUT1), LED3.C3 (CATHODE_B)
unnamed: C1.2, IC1.4 (BYPASS)
unnamed: C11.2, C12.2, FB1.1, IC3.9 (VDDA)
unnamed: IC2.8 (OUT2), LED3.C2 (CATHODE_G)
unnamed: IC2.24 (SOUT), IC4.5 (SIN)
unnamed: IC2.9 (OUT3), LED3.C1 (CATHODE_R)
unnamed: IC2.10 (OUT4), LED2.C3 (CATHODE_B)
unnamed: IC2.11 (OUT5), LED2.C2 (CATHODE_G)
unnamed: IC2.12 (OUT6), LED2.C1 (CATHODE_R)
unnamed: IC2.13 (OUT7), LED1.C3 (CATHODE_B)
unnamed: IC4.27 (IREF), R8.2
unnamed: IC2.14 (OUT8), LED1.C2 (CATHODE_G)
unnamed: IC2.15 (OUT9), LED1.C1 (CATHODE_R)
unnamed: IC2.27 (IREF), R16.2
unnamed: IC2.16 (OUT10), LED8.C3 (CATHODE_B)
unnamed: IC2.17 (OUT11), LED8.C2 (CATHODE_G)
unnamed: IC2.18 (OUT12), LED8.C1 (CATHODE_R)
unnamed: IC2.19 (OUT13), LED9.C3 (CATHODE_B)
unnamed: IC2.20 (OUT14), LED9.C2 (CATHODE_G)
unnamed: IC2.21 (OUT15), LED9.C1 (CATHODE_R)
unnamed: IC4.7 (OUT1), LED10.C3 (CATHODE_B)
unnamed: IC4.8 (OUT2), LED10.C2 (CATHODE_G)
unnamed: IC4.9 (OUT3), LED10.C1 (CATHODE_R)
unnamed: IC4.10 (OUT4), LED11.C3 (CATHODE_B)
unnamed: IC4.11 (OUT5), LED11.C2 (CATHODE_G)
unnamed: IC4.12 (OUT6), LED11.C1 (CATHODE_R)
unnamed: IC4.13 (OUT7), LED12.C3 (CATHODE_B)
unnamed: IC4.14 (OUT8), LED12.C2 (CATHODE_G)
unnamed: IC4.15 (OUT9), LED12.C1 (CATHODE_R)
unnamed: IC4.16 (OUT10), LED5.C3 (CATHODE_B)
unnamed: IC4.17 (OUT11), LED5.C2 (CATHODE_G)
unnamed: IC4.18 (OUT12), LED5.C1 (CATHODE_R)
unnamed: IC4.19 (OUT13), LED4.C3 (CATHODE_B)
unnamed: IC4.20 (OUT14), LED4.C2 (CATHODE_G)
unnamed: IC4.21 (OUT15), LED4.C1 (CATHODE_R)
unnamed: IC3.30 (PA9), R3.1
unnamed: Q1.3 (D), R1.1
unnamed: LED55.K (CATHODE), R1.2
unnamed: LED54.K (CATHODE), LED55.A (ANODE)
unnamed: LED53.K (CATHODE), LED54.A (ANODE)
unnamed: LED52.K (CATHODE), LED53.A (ANODE)
unnamed: LED51.K (CATHODE), LED52.A (ANODE)
unnamed: LED50.K (CATHODE), LED51.A (ANODE)
RST: IC3.7 (NRST), J7.3 (RESET), R17.1
S1.1: IC3.41 (PB5), S1.1 (COM)
S1.2: IC3.36 (PF7), S2.1 (COM)
S1.3: IC3.39 (PB3), S3.1 (COM)
S1.4: IC3.22 (PB11), S4.1 (COM)
S1.5: IC3.21 (PB10), S5.1 (COM)
S2.1: IC3.42 (PB6), S8.1 (COM)
S2.2: IC3.43 (PB7), S9.1 (COM)
S2.3: IC3.5 (PF0/OSC_IN), S10.1 (COM)
S2.4: IC3.46 (PB9), S11.1 (COM)
S2.5: IC3.20 (PB2), S12.1 (COM)
SCK: IC2.4 (SCLK), IC3.26 (PB13), IC4.4 (SCLK), R6.1
SWCLK: IC3.37 (PA14), J7.4 (SWCLK)
SWDIO: IC3.34 (PA13), J7.2 (SWDIO)
SYNC: IC3.4 (PC15/OSC32_OUT); also elsewhere on the board
T1: IC3.10 (PA0), RN2.D1, RT8.1
T2: IC3.11 (PA1), RN2.C1, RT9.1
T3: IC3.12 (PA2), RN2.B1, RT10.1
T4: IC3.13 (PA3), RN2.A1, RT11.1
T5: IC3.14 (PA4), RN1.D1, RT12.1
T6: IC3.15 (PA5), RN1.C1, RT4.1
T7: IC3.16 (PA6), RN1.B1, RT5.1
T8: IC3.17 (PA7), RN1.A1, RT3.1
T9: IC3.18 (PB0), R15.1, RT2.1
T10: IC3.19 (PB1), R14.1, RT1.1
TIM3.1: IC3.40 (PB4), R2.2
TIM16.1: IC3.45 (PB8)
WORK_LEDS: Q1.1 (G), R2.1
XLAT: IC2.3 (XLAT), IC3.29 (PA8), R5.1
XLAT.1: IC3.35 (PF6), IC4.3 (XLAT), R12.1

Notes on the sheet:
buttons
s2.5
S1.3
TIM3.1
S1.1
S2.1
S2.2
TIM16.1
S2.4
S1.5
S1.4
T1.1
T1.2
MODE
SCK
MISO
MOSI
T2.1
T2.2
T2.3
T2.4
T2.5
T1.4
T1.5
T1.3
XLAT
GSCLK
BLANK
SWDIO
SWCLK/BTX
BRX
S1.2
S2.3
LEDs controlled: 10 Bus Address: 2
Back of panel lighting (not populated)
7x7 LED board

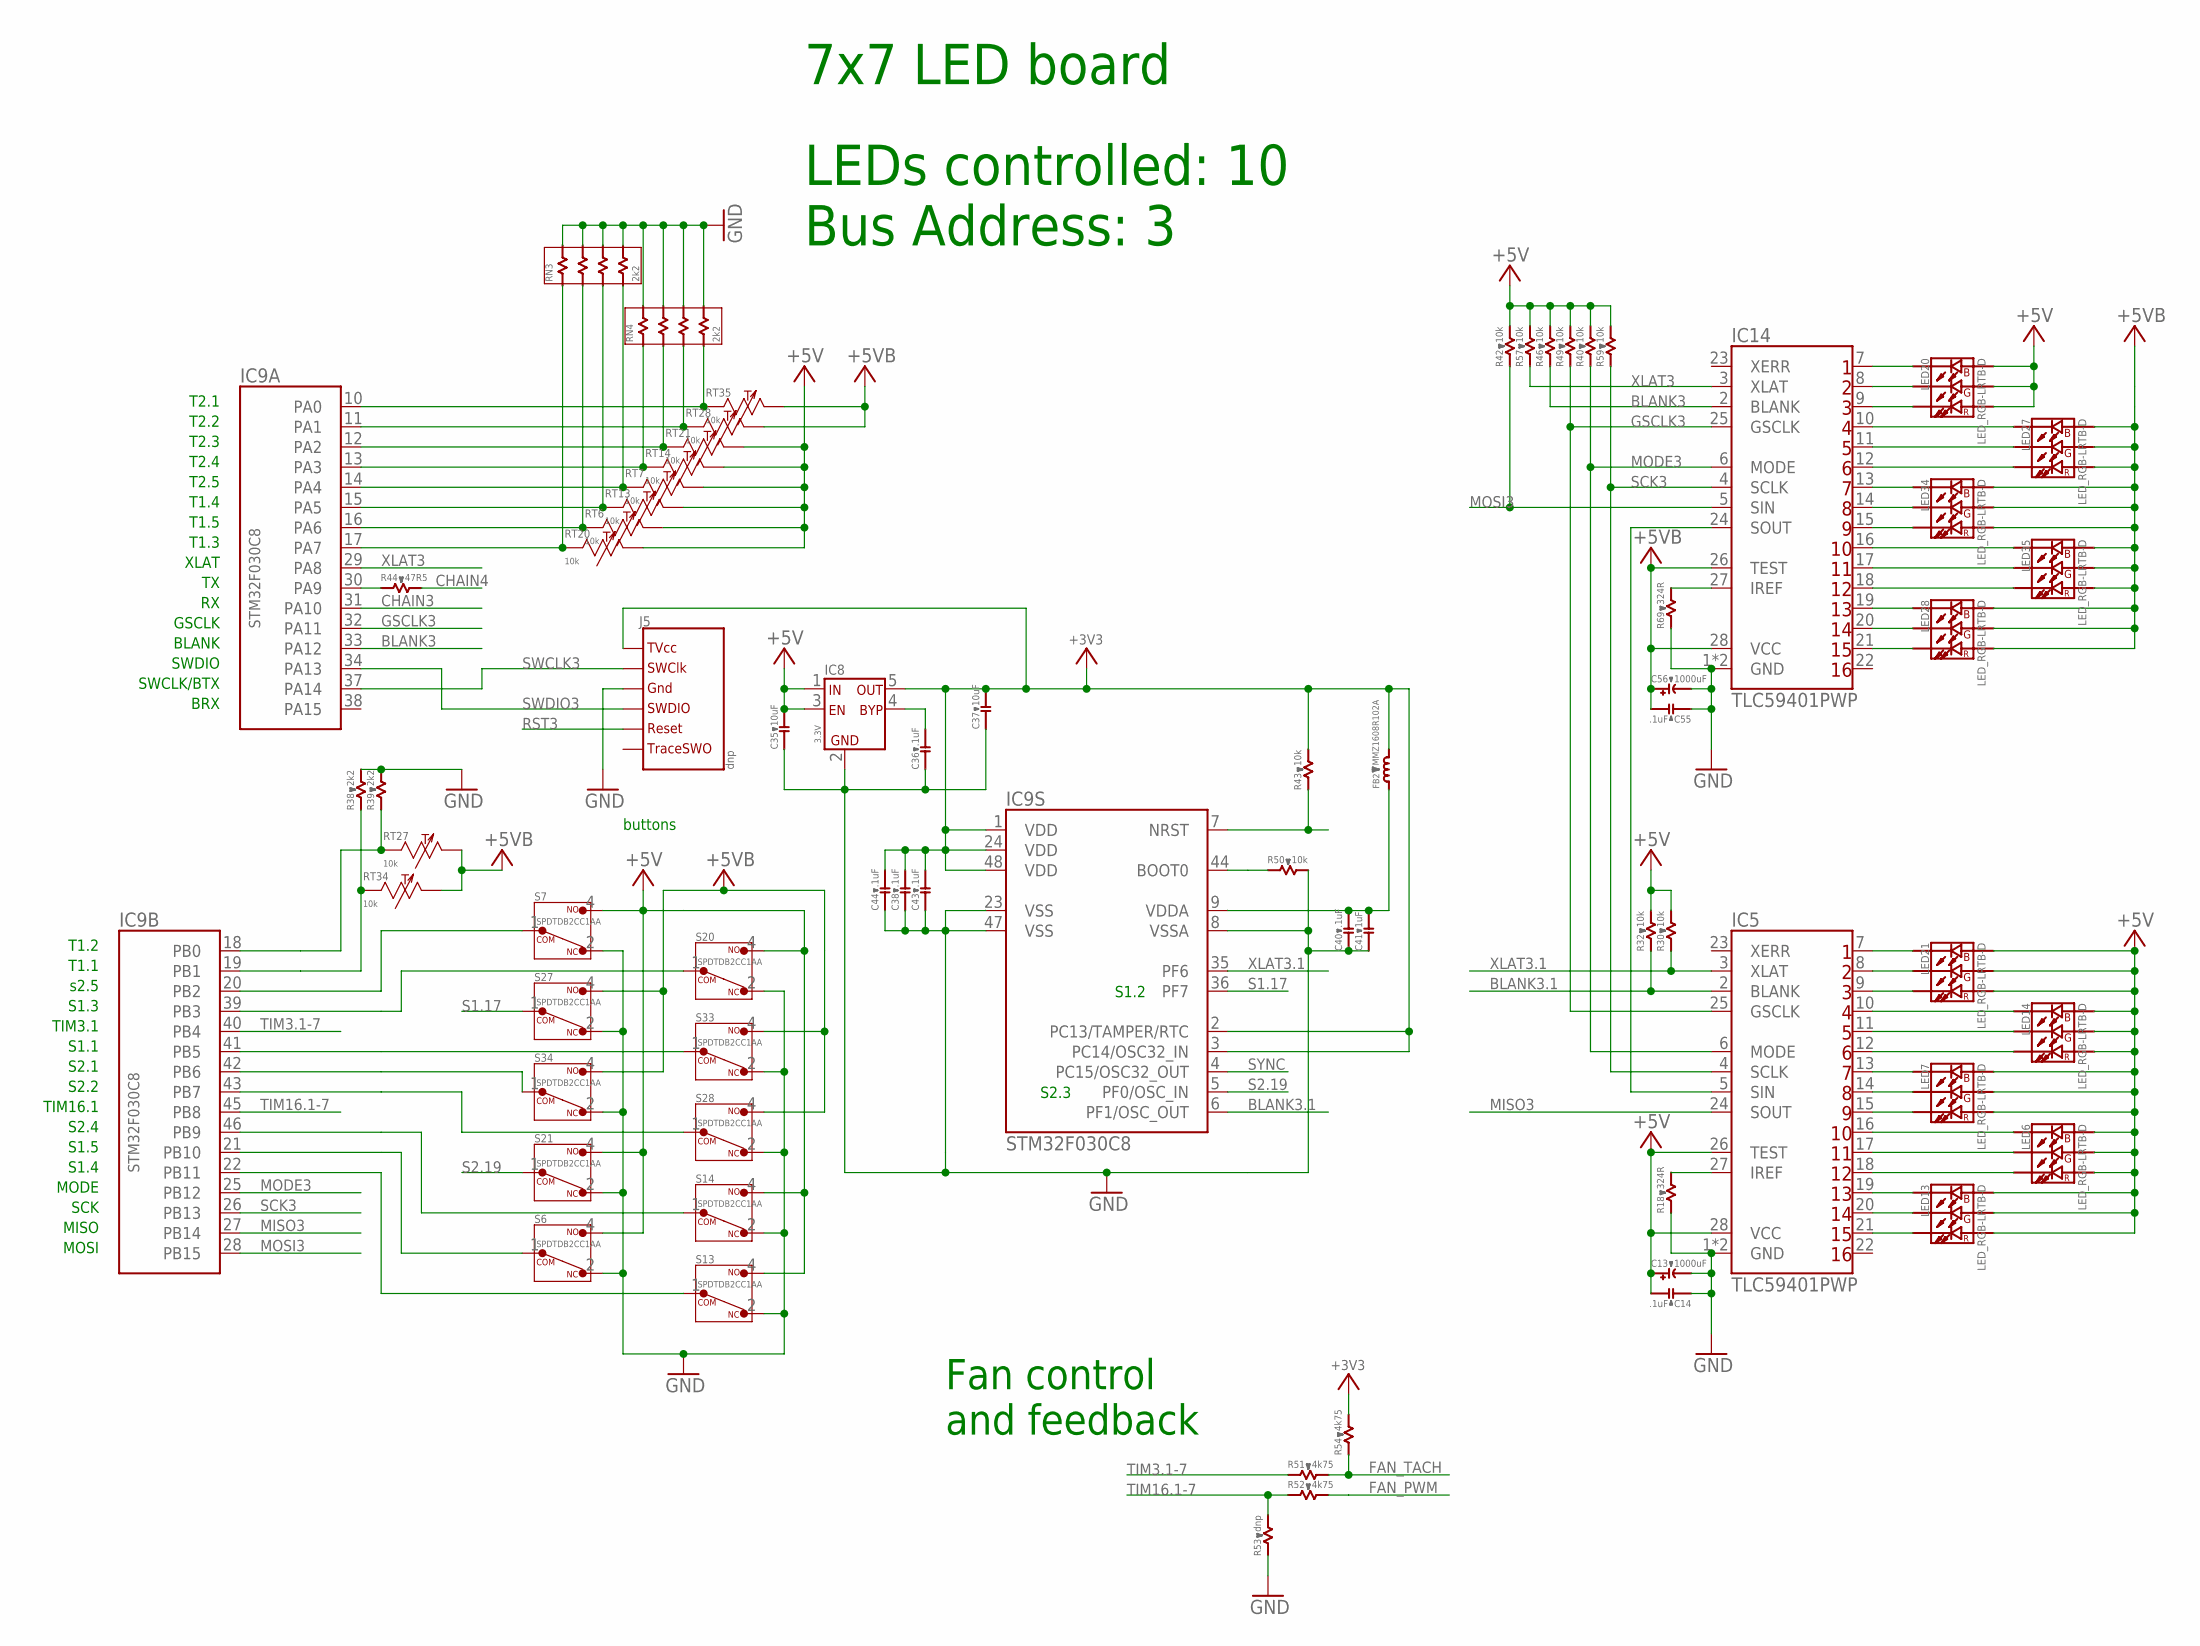
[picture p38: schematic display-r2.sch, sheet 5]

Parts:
C13, C56: 1000uF; E5-10,5; PARTNO EKZN160ELL102MJ16S
C14, C36, C38, C40, C43, C44, C55: .1uF; C0603B; PARTNO CGA3E2X7R1H104K080AA
C35, C37: 10uF; C0603B; PARTNO C1608X6S1A106M080AC
C41: 1uF; C0603B; PARTNO CGA3E3X5R1H105K080AB
FB2: MMZ1608R102A; R0603B; PARTNO MMZ1608R102A
IC5, IC14: TLC59401PWP; TSSOP28_PAD; PARTNO TLC59401PWPR
IC8: 3.3V; SOT-23-5; PARTNO TC2185-3.3VCTTR
IC9: STM32F030C8; LQFP-48; PARTNO STM32F030C8T6
J5: dnp; TC2030-IDC-NL
LED6, LED7, LED13, LED14, LED20, LED21, LED27, LED28, LED34, LED35: LED_RGB-LRTB-D; LRTB_C9TP-D; PARTNO LRTBC9TP-CWD5-1+D5E7-25+A
R18, R69: 324R; R0603B; PARTNO CRCW0603324RFKEA
R30, R32, R40, R42, R43, R46, R49, R50, R57, R59: 10k; R0603B; PARTNO CRCW060310K0FKEA
R38, R39: 2k2; R0603B; PARTNO CRCW06032K20FKEA
R44: 47R5; R0603B; PARTNO CRCW060347R5FKEA
R51, R52, R54: 4k75; R0603B; PARTNO CRCW06034K75FKEA
R53: dnp; R0603B; PARTNO *
RN3, RN4: 2k2; CAY16; PARTNO CAY16-2201F4LF
RT6, RT7, RT13, RT14, RT20, RT21, RT27, RT28, RT34, RT35: 10k; R0603Y; PARTNO NCP18XH103F03RB
S6, S7, S13, S14, S20, S21, S27, S28, S33, S34: SPDTDB2CC1AA; DB2CC1AA; PARTNO DB2CC1AA

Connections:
+3V3.D: C37.2, C38.2, C43.2, C44.2, FB2.2, IC8.5 (OUT), IC9.1 (VDD), IC9.2 (PC13/TAMPER/RTC), IC9.3 (PC14/OSC32_IN), IC9.24 (VDD), IC9.48 (VDD), J5.1 (TVCC), R43.2, R54.2
+5V: C13.+, C14.2, C35.2, IC5.26 (TEST), IC5.28 (VCC), IC8.1 (IN), IC8.3 (EN), LED6.A1 (ANODE_R), LED6.A2 (ANODE_G), LED6.A3 (ANODE_B), LED7.A1 (ANODE_R), LED7.A2 (ANODE_G), LED7.A3 (ANODE_B), LED13.A1 (ANODE_R), LED13.A2 (ANODE_G), LED13.A3 (ANODE_B), LED14.A1 (ANODE_R), LED14.A2 (ANODE_G), LED14.A3 (ANODE_B), LED20.A1 (ANODE_R), LED20.A2 (ANODE_G), LED20.A3 (ANODE_B), LED21.A1 (ANODE_R), LED21.A2 (ANODE_G), LED21.A3 (ANODE_B), R30.2, R32.2, R40.2, R42.2, R46.2, R49.2, R57.2, R59.2, RT6.2, RT7.2, RT13.2, RT14.2, RT20.2, RT21.2, S6.4 (NO), S7.4 (NO), S13.4 (NO), S14.4 (NO), S20.4 (NO), S21.4 (NO); also elsewhere on the board
+5VB: C55.2, C56.+, IC14.26 (TEST), IC14.28 (VCC), LED27.A1 (ANODE_R), LED27.A2 (ANODE_G), LED27.A3 (ANODE_B), LED28.A1 (ANODE_R), LED28.A2 (ANODE_G), LED28.A3 (ANODE_B), LED34.A1 (ANODE_R), LED34.A2 (ANODE_G), LED34.A3 (ANODE_B), LED35.A1 (ANODE_R), LED35.A2 (ANODE_G), LED35.A3 (ANODE_B), RT27.2, RT28.2, RT34.2, RT35.2, S27.4 (NO), S28.4 (NO), S33.4 (NO), S34.4 (NO); also elsewhere on the board
BLANK3: IC9.33 (PA12), IC14.2 (BLANK), R46.1
BLANK3.1: IC5.2 (BLANK), IC9.6 (PF1/OSC_OUT), R32.1
CHAIN3: IC9.31 (PA10); also elsewhere on the board
CHAIN4: R44.2; also elsewhere on the board
FAN_PWM: R52.2; also elsewhere on the board
FAN_TACH: R51.2, R54.1; also elsewhere on the board
GND: C13.-, C14.1, C35.1, C36.1, C37.1, C38.1, C40.1, C41.1, C43.1, C44.1, C55.1, C56.-, IC5.1 (GND), IC5.PAD (GND), IC8.2 (GND), IC9.8 (VSSA), IC9.23 (VSS), IC9.47 (VSS), IC14.1 (GND), IC14.PAD (GND), J5.5 (GND), R18.1, R38.2, R39.2, R50.2, R53.1, R69.1, RN3.A2, RN3.B2, RN3.C2, RN3.D2, RN4.A2, RN4.B2, RN4.C2, RN4.D2, S6.2 (NC), S7.2 (NC), S13.2 (NC), S14.2 (NC), S20.2 (NC), S21.2 (NC), S27.2 (NC), S28.2 (NC), S33.2 (NC), S34.2 (NC); also elsewhere on the board
GSCLK3: IC5.25 (GSCLK), IC9.32 (PA11), IC14.25 (GSCLK), R49.1
MISO3: IC5.24 (SOUT), IC9.27 (PB14)
MODE3: IC5.6 (MODE), IC9.25 (PB12), IC14.6 (MODE), R40.1
MOSI3: IC9.28 (PB15), IC14.5 (SIN), R42.1
unnamed: IC9.44 (BOOT0), R50.1
unnamed: C40.2, C41.2, FB2.1, IC9.9 (VDDA)
unnamed: C36.2, IC8.4 (BYPASS)
unnamed: IC5.5 (SIN), IC14.24 (SOUT)
unnamed: IC5.27 (IREF), R18.2
unnamed: IC14.27 (IREF), R69.2
unnamed: IC14.7 (OUT1), LED20.C3 (CATHODE_B)
unnamed: IC14.8 (OUT2), LED20.C2 (CATHODE_G)
unnamed: IC14.9 (OUT3), LED20.C1 (CATHODE_R)
unnamed: IC14.10 (OUT4), LED27.C3 (CATHODE_B)
unnamed: IC14.11 (OUT5), LED27.C2 (CATHODE_G)
unnamed: IC14.12 (OUT6), LED27.C1 (CATHODE_R)
unnamed: IC14.13 (OUT7), LED34.C3 (CATHODE_B)
unnamed: IC14.14 (OUT8), LED34.C2 (CATHODE_G)
unnamed: IC14.15 (OUT9), LED34.C1 (CATHODE_R)
unnamed: IC14.16 (OUT10), LED35.C3 (CATHODE_B)
unnamed: IC14.17 (OUT11), LED35.C2 (CATHODE_G)
unnamed: IC14.18 (OUT12), LED35.C1 (CATHODE_R)
unnamed: IC14.19 (OUT13), LED28.C3 (CATHODE_B)
unnamed: IC14.20 (OUT14), LED28.C2 (CATHODE_G)
unnamed: IC14.21 (OUT15), LED28.C1 (CATHODE_R)
unnamed: IC5.7 (OUT1), LED21.C3 (CATHODE_B)
unnamed: IC5.8 (OUT2), LED21.C2 (CATHODE_G)
unnamed: IC5.9 (OUT3), LED21.C1 (CATHODE_R)
unnamed: IC5.10 (OUT4), LED14.C3 (CATHODE_B)
unnamed: IC5.11 (OUT5), LED14.C2 (CATHODE_G)
unnamed: IC5.12 (OUT6), LED14.C1 (CATHODE_R)
unnamed: IC5.13 (OUT7), LED7.C3 (CATHODE_B)
unnamed: IC5.14 (OUT8), LED7.C2 (CATHODE_G)
unnamed: IC5.15 (OUT9), LED7.C1 (CATHODE_R)
unnamed: IC5.16 (OUT10), LED6.C3 (CATHODE_B)
unnamed: IC5.17 (OUT11), LED6.C2 (CATHODE_G)
unnamed: IC5.18 (OUT12), LED6.C1 (CATHODE_R)
unnamed: IC5.19 (OUT13), LED13.C3 (CATHODE_B)
unnamed: IC5.20 (OUT14), LED13.C2 (CATHODE_G)
unnamed: IC5.21 (OUT15), LED13.C1 (CATHODE_R)
unnamed: IC9.30 (PA9), R44.1
RST3: IC9.7 (NRST), J5.3 (RESET), R43.1
S1.16: IC9.39 (PB3), S20.1 (COM)
S1.17: IC9.36 (PF7), S27.1 (COM)
S1.18: IC9.41 (PB5), S33.1 (COM)
S1.19: IC9.21 (PB10), S6.1 (COM)
S1.20: IC9.22 (PB11), S13.1 (COM)
S2.16: IC9.20 (PB2), S7.1 (COM)
S2.17: IC9.42 (PB6), S34.1 (COM)
S2.18: IC9.43 (PB7), S28.1 (COM)
S2.19: IC9.5 (PF0/OSC_IN), S21.1 (COM)
S2.20: IC9.46 (PB9), S14.1 (COM)
SCK3: IC5.4 (SCLK), IC9.26 (PB13), IC14.4 (SCLK), R59.1
SWCLK3: IC9.37 (PA14), J5.4 (SWCLK)
SWDIO3: IC9.34 (PA13), J5.2 (SWDIO)
SYNC: IC9.4 (PC15/OSC32_OUT); also elsewhere on the board
T31: IC9.14 (PA4), RN3.D1, RT7.1
T32: IC9.15 (PA5), RN3.C1, RT13.1
T33: IC9.16 (PA6), RN3.B1, RT6.1
T34: IC9.17 (PA7), RN3.A1, RT20.1
T35: IC9.18 (PB0), R39.1, RT27.1
T36: IC9.19 (PB1), R38.1, RT34.1
T37: IC9.13 (PA3), RN4.A1, RT14.1
T38: IC9.12 (PA2), RN4.B1, RT21.1
T39: IC9.11 (PA1), RN4.C1, RT28.1
T40: IC9.10 (PA0), RN4.D1, RT35.1
TIM3.1-7: IC9.40 (PB4), R51.1
TIM16.1-7: IC9.45 (PB8), R52.1, R53.2
XLAT3: IC9.29 (PA8), IC14.3 (XLAT), R57.1
XLAT3.1: IC5.3 (XLAT), IC9.35 (PF6), R30.1

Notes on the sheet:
buttons
s2.5
S1.3
TIM3.1
S1.1
S2.1
S2.2
TIM16.1
S2.4
S1.5
S1.4
T1.1
T1.2
MODE
SCK
MISO
MOSI
T2.1
T2.2
T2.3
T2.4
T2.5
T1.4
T1.5
T1.3
XLAT
GSCLK
BLANK
SWDIO
SWCLK/BTX
BRX
S1.2
S2.3
LEDs controlled: 10 Bus Address: 3
Fan control and feedback
7x7 LED board

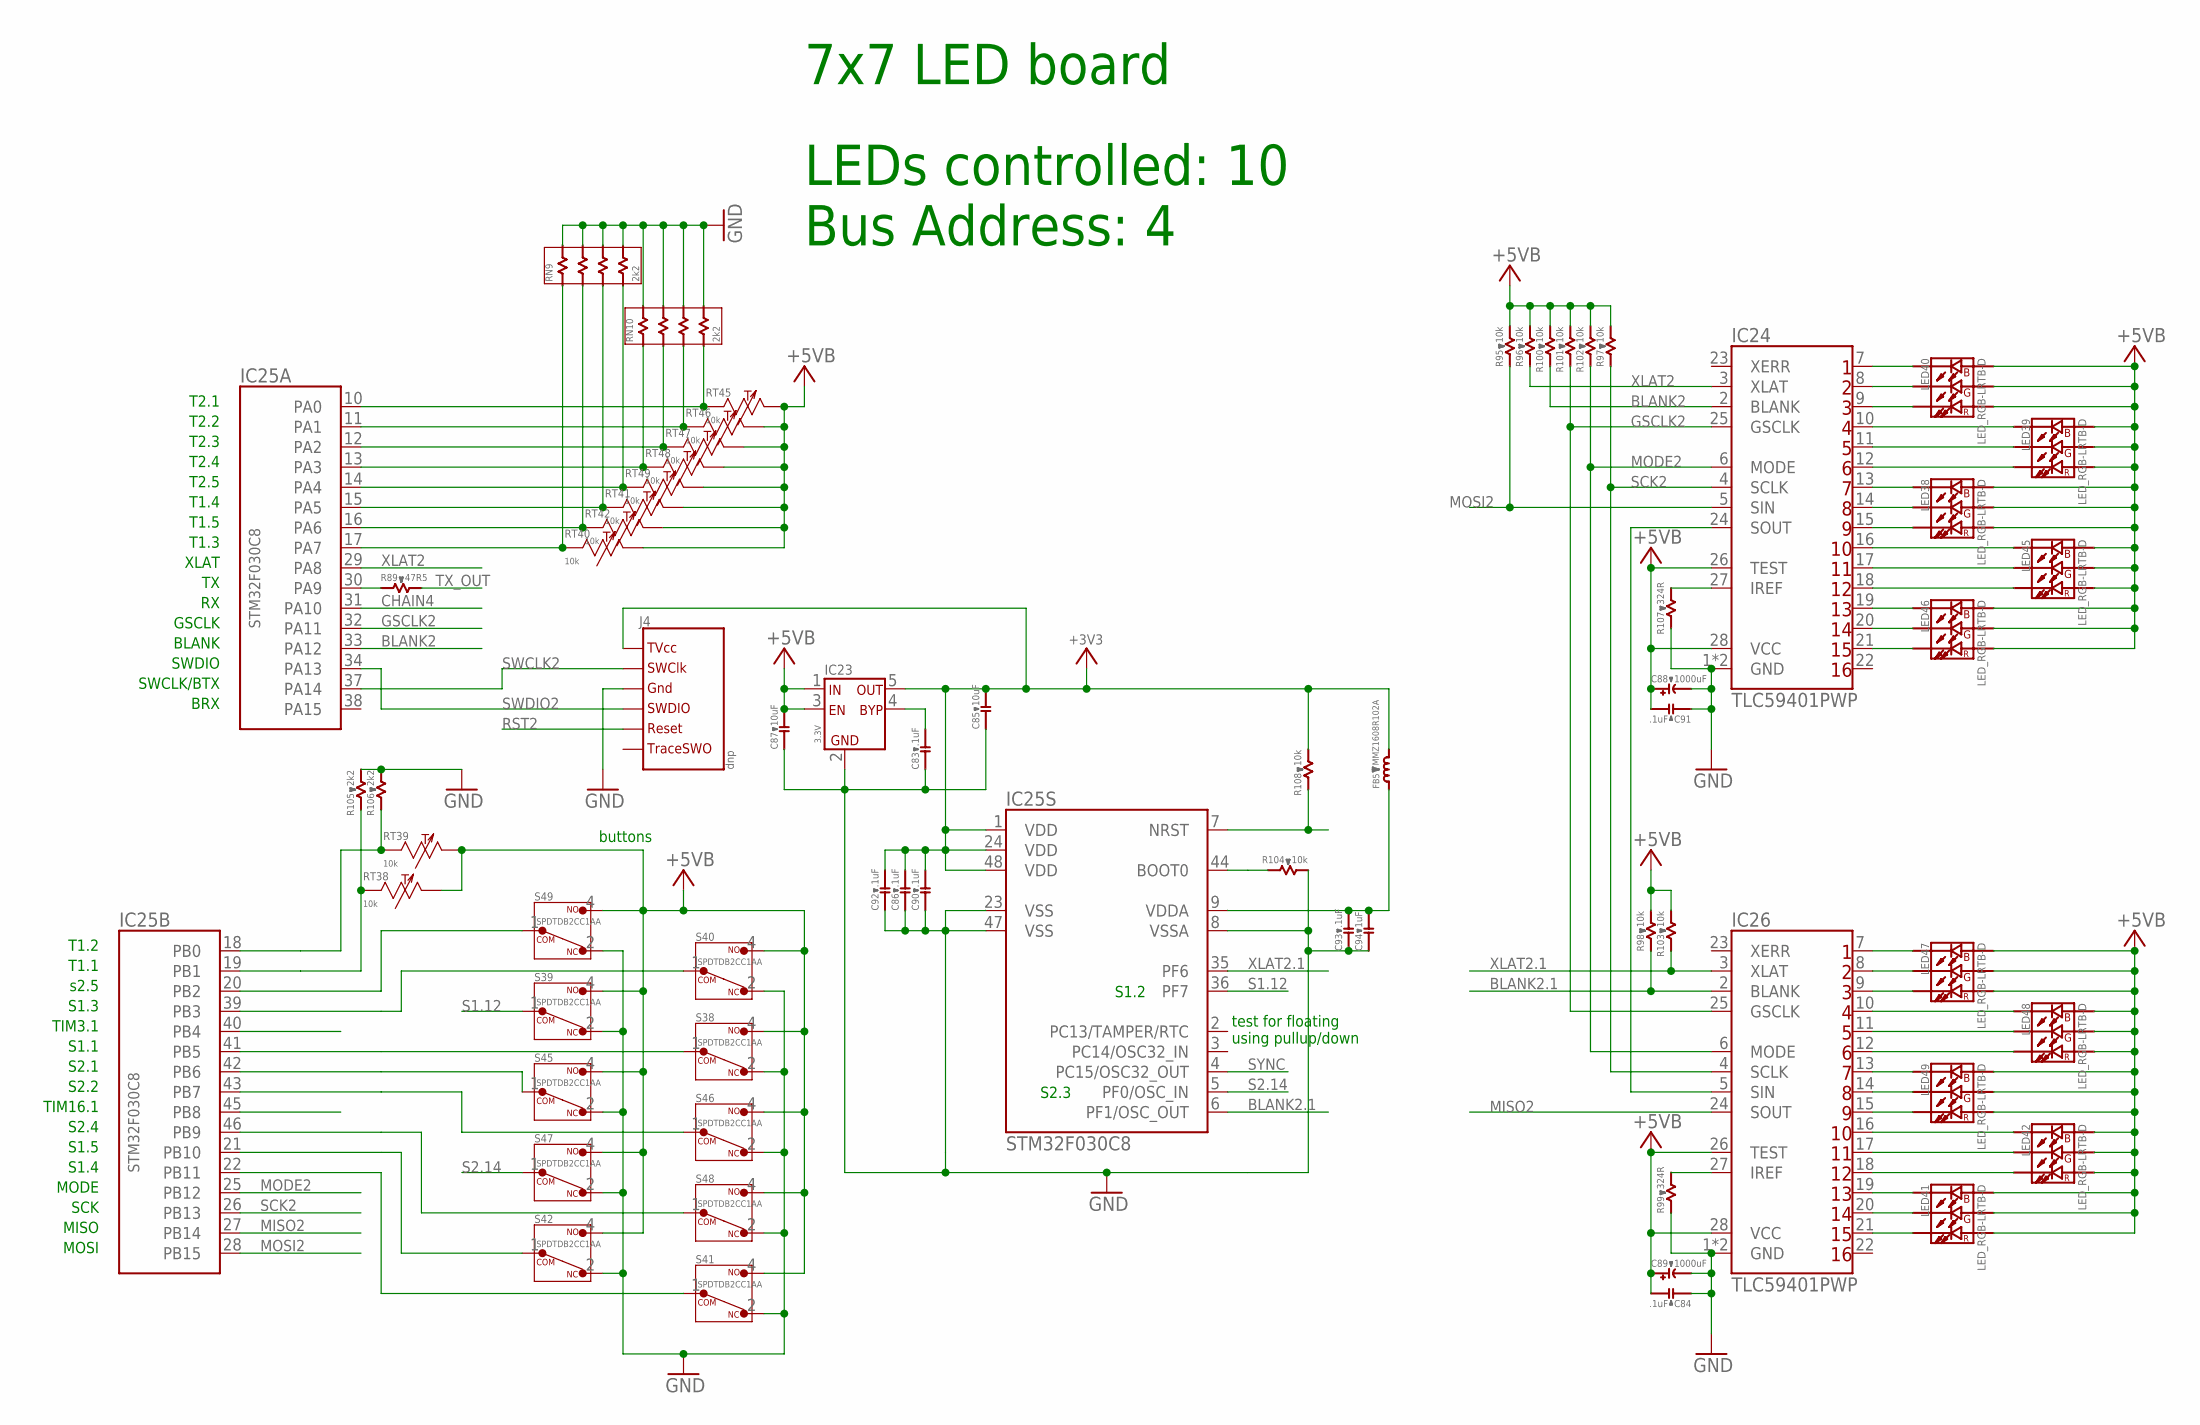
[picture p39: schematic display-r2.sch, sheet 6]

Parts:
C83, C84, C86, C90, C91, C92, C93: .1uF; C0603B; PARTNO CGA3E2X7R1H104K080AA
C85, C87: 10uF; C0603B; PARTNO C1608X6S1A106M080AC
C88, C89: 1000uF; E5-10,5; PARTNO EKZN160ELL102MJ16S
C94: 1uF; C0603B; PARTNO CGA3E3X5R1H105K080AB
FB5: MMZ1608R102A; R0603B; PARTNO MMZ1608R102A
IC23: 3.3V; SOT-23-5; PARTNO TC2185-3.3VCTTR
IC24, IC26: TLC59401PWP; TSSOP28_PAD; PARTNO TLC59401PWPR
IC25: STM32F030C8; LQFP-48; PARTNO STM32F030C8T6
J4: dnp; TC2030-IDC-NL
LED38, LED39, LED40, LED41, LED42, LED45, LED46, LED47, LED48, LED49: LED_RGB-LRTB-D; LRTB_C9TP-D; PARTNO LRTBC9TP-CWD5-1+D5E7-25+A
R89: 47R5; R0603B; PARTNO CRCW060347R5FKEA
R95, R96, R97, R98, R100, R101, R102, R103, R104, R108: 10k; R0603B; PARTNO CRCW060310K0FKEA
R99, R107: 324R; R0603B; PARTNO CRCW0603324RFKEA
R105, R106: 2k2; R0603B; PARTNO CRCW06032K20FKEA
RN9, RN10: 2k2; CAY16; PARTNO CAY16-2201F4LF
RT38, RT39, RT40, RT41, RT42, RT45, RT46, RT47, RT48, RT49: 10k; R0603Y; PARTNO NCP18XH103F03RB
S38, S39, S40, S41, S42, S45, S46, S47, S48, S49: SPDTDB2CC1AA; DB2CC1AA; PARTNO DB2CC1AA

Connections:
+3V3.C: C85.2, C86.2, C90.2, C92.2, FB5.2, IC23.5 (OUT), IC25.1 (VDD), IC25.24 (VDD), IC25.48 (VDD), J4.1 (TVCC), R108.2; also elsewhere on the board
+5VB: C84.2, C87.2, C88.+, C89.+, C91.2, IC23.1 (IN), IC23.3 (EN), IC24.26 (TEST), IC24.28 (VCC), IC26.26 (TEST), IC26.28 (VCC), LED38.A1 (ANODE_R), LED38.A2 (ANODE_G), LED38.A3 (ANODE_B), LED39.A1 (ANODE_R), LED39.A2 (ANODE_G), LED39.A3 (ANODE_B), LED40.A1 (ANODE_R), LED40.A2 (ANODE_G), LED40.A3 (ANODE_B), LED41.A1 (ANODE_R), LED41.A2 (ANODE_G), LED41.A3 (ANODE_B), LED42.A1 (ANODE_R), LED42.A2 (ANODE_G), LED42.A3 (ANODE_B), LED45.A1 (ANODE_R), LED45.A2 (ANODE_G), LED45.A3 (ANODE_B), LED46.A1 (ANODE_R), LED46.A2 (ANODE_G), LED46.A3 (ANODE_B), LED47.A1 (ANODE_R), LED47.A2 (ANODE_G), LED47.A3 (ANODE_B), LED48.A1 (ANODE_R), LED48.A2 (ANODE_G), LED48.A3 (ANODE_B), LED49.A1 (ANODE_R), LED49.A2 (ANODE_G), LED49.A3 (ANODE_B), R95.2, R96.2, R97.2, R98.2, R100.2, R101.2, R102.2, R103.2, RT38.2, RT39.2, RT40.2, RT41.2, RT42.2, RT45.2, RT46.2, RT47.2, RT48.2, RT49.2, S38.4 (NO), S39.4 (NO), S40.4 (NO), S41.4 (NO), S42.4 (NO), S45.4 (NO), S46.4 (NO), S47.4 (NO), S48.4 (NO), S49.4 (NO); also elsewhere on the board
BLANK2: IC24.2 (BLANK), IC25.33 (PA12), R100.1
BLANK2.1: IC25.6 (PF1/OSC_OUT), IC26.2 (BLANK), R98.1
CHAIN4: IC25.31 (PA10); also elsewhere on the board
GND: C83.1, C84.1, C85.1, C86.1, C87.1, C88.-, C89.-, C90.1, C91.1, C92.1, C93.1, C94.1, IC23.2 (GND), IC24.1 (GND), IC24.PAD (GND), IC25.8 (VSSA), IC25.23 (VSS), IC25.47 (VSS), IC26.1 (GND), IC26.PAD (GND), J4.5 (GND), R99.1, R104.2, R105.2, R106.2, R107.1, RN9.A2, RN9.B2, RN9.C2, RN9.D2, RN10.A2, RN10.B2, RN10.C2, RN10.D2, S38.2 (NC), S39.2 (NC), S40.2 (NC), S41.2 (NC), S42.2 (NC), S45.2 (NC), S46.2 (NC), S47.2 (NC), S48.2 (NC), S49.2 (NC); also elsewhere on the board
GSCLK2: IC24.25 (GSCLK), IC25.32 (PA11), IC26.25 (GSCLK), R101.1
MISO2: IC25.27 (PB14), IC26.24 (SOUT)
MODE2: IC24.6 (MODE), IC25.25 (PB12), IC26.6 (MODE), R102.1
MOSI2: IC24.5 (SIN), IC25.28 (PB15), R95.1
unnamed: IC25.44 (BOOT0), R104.1
unnamed: C93.2, C94.2, FB5.1, IC25.9 (VDDA)
unnamed: C83.2, IC23.4 (BYPASS)
unnamed: IC24.24 (SOUT), IC26.5 (SIN)
unnamed: IC26.27 (IREF), R99.2
unnamed: IC24.27 (IREF), R107.2
unnamed: IC24.7 (OUT1), LED40.C3 (CATHODE_B)
unnamed: IC24.8 (OUT2), LED40.C2 (CATHODE_G)
unnamed: IC24.9 (OUT3), LED40.C1 (CATHODE_R)
unnamed: IC24.10 (OUT4), LED39.C3 (CATHODE_B)
unnamed: IC24.11 (OUT5), LED39.C2 (CATHODE_G)
unnamed: IC24.12 (OUT6), LED39.C1 (CATHODE_R)
unnamed: IC24.13 (OUT7), LED38.C3 (CATHODE_B)
unnamed: IC24.14 (OUT8), LED38.C2 (CATHODE_G)
unnamed: IC24.15 (OUT9), LED38.C1 (CATHODE_R)
unnamed: IC24.16 (OUT10), LED45.C3 (CATHODE_B)
unnamed: IC24.17 (OUT11), LED45.C2 (CATHODE_G)
unnamed: IC24.18 (OUT12), LED45.C1 (CATHODE_R)
unnamed: IC24.19 (OUT13), LED46.C3 (CATHODE_B)
unnamed: IC24.20 (OUT14), LED46.C2 (CATHODE_G)
unnamed: IC24.21 (OUT15), LED46.C1 (CATHODE_R)
unnamed: IC26.7 (OUT1), LED47.C3 (CATHODE_B)
unnamed: IC26.8 (OUT2), LED47.C2 (CATHODE_G)
unnamed: IC26.9 (OUT3), LED47.C1 (CATHODE_R)
unnamed: IC26.10 (OUT4), LED48.C3 (CATHODE_B)
unnamed: IC26.11 (OUT5), LED48.C2 (CATHODE_G)
unnamed: IC26.12 (OUT6), LED48.C1 (CATHODE_R)
unnamed: IC26.13 (OUT7), LED49.C3 (CATHODE_B)
unnamed: IC26.14 (OUT8), LED49.C2 (CATHODE_G)
unnamed: IC26.15 (OUT9), LED49.C1 (CATHODE_R)
unnamed: IC26.16 (OUT10), LED42.C3 (CATHODE_B)
unnamed: IC26.17 (OUT11), LED42.C2 (CATHODE_G)
unnamed: IC26.18 (OUT12), LED42.C1 (CATHODE_R)
unnamed: IC26.19 (OUT13), LED41.C3 (CATHODE_B)
unnamed: IC26.20 (OUT14), LED41.C2 (CATHODE_G)
unnamed: IC26.21 (OUT15), LED41.C1 (CATHODE_R)
unnamed: IC25.30 (PA9), R89.1
RST2: IC25.7 (NRST), J4.3 (RESET), R108.1
S1.11: IC25.39 (PB3), S40.1 (COM)
S1.12: IC25.36 (PF7), S39.1 (COM)
S1.13: IC25.41 (PB5), S38.1 (COM)
S1.14: IC25.21 (PB10), S42.1 (COM)
S1.15: IC25.22 (PB11), S41.1 (COM)
S2.11: IC25.20 (PB2), S49.1 (COM)
S2.12: IC25.42 (PB6), S45.1 (COM)
S2.13: IC25.43 (PB7), S46.1 (COM)
S2.14: IC25.5 (PF0/OSC_IN), S47.1 (COM)
S2.15: IC25.46 (PB9), S48.1 (COM)
SCK2: IC24.4 (SCLK), IC25.26 (PB13), IC26.4 (SCLK), R97.1
SWCLK2: IC25.37 (PA14), J4.4 (SWCLK)
SWDIO2: IC25.34 (PA13), J4.2 (SWDIO)
SYNC: IC25.4 (PC15/OSC32_OUT); also elsewhere on the board
T21: IC25.14 (PA4), RN9.D1, RT49.1
T22: IC25.15 (PA5), RN9.C1, RT41.1
T23: IC25.16 (PA6), RN9.B1, RT42.1
T24: IC25.17 (PA7), RN9.A1, RT40.1
T25: IC25.18 (PB0), R106.1, RT39.1
T26: IC25.19 (PB1), R105.1, RT38.1
T27: IC25.13 (PA3), RN10.A1, RT48.1
T28: IC25.12 (PA2), RN10.B1, RT47.1
T29: IC25.11 (PA1), RN10.C1, RT46.1
T30: IC25.10 (PA0), RN10.D1, RT45.1
TIM3.3: IC25.40 (PB4)
TIM16.3: IC25.45 (PB8)
TX_OUT: R89.2; also elsewhere on the board
XLAT2: IC24.3 (XLAT), IC25.29 (PA8), R96.1
XLAT2.1: IC25.35 (PF6), IC26.3 (XLAT), R103.1

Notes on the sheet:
buttons
s2.5
S1.3
TIM3.1
S1.1
S2.1
S2.2
TIM16.1
S2.4
S1.5
S1.4
T1.1
T1.2
MODE
SCK
MISO
MOSI
T2.1
T2.2
T2.3
T2.4
T2.5
T1.4
T1.5
T1.3
XLAT
GSCLK
BLANK
SWDIO
SWCLK/BTX
BRX
S1.2
S2.3
test for floating using pullup/down
LEDs controlled: 10 Bus Address: 4
7x7 LED board

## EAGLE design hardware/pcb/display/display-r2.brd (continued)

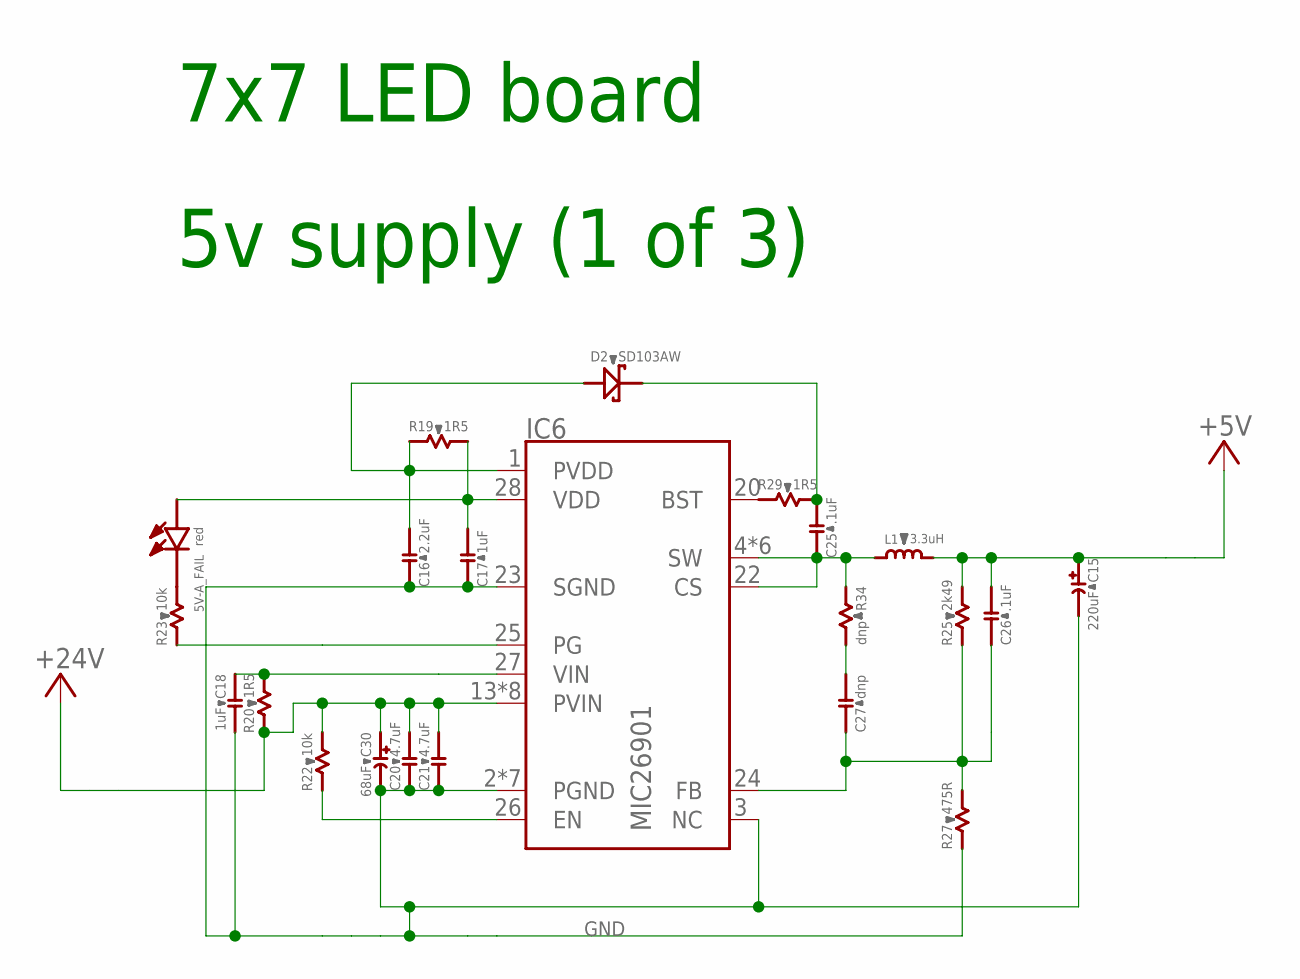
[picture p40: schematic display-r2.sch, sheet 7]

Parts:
5V-A_FAIL: red; CHIPLED_0603; PARTNO LTST-C190KRKT
C15: 220uF; E3,5-8; PARTNO 16SEPC220MD
C16: 2.2uF; C0603B; PARTNO C1608X5R1V225K080AC
C17, C18: 1uF; C0603B; PARTNO CGA3E3X5R1H105K080AB
C20, C21: 4.7uF; C1206NT; PARTNO UMK316AB7475KL-T
C25: .1uF; C0603B; PARTNO CGA3E2X7R1H104K080AA
C26: .1uF; C0603B; PARTNO *
C27: dnp; C0603B; PARTNO *
C30: 68uF; E5-10,5; PARTNO PLV1H680MDL1
D2: SD103AW; SOD-323; PARTNO SD103AWS-7-F
IC6: MIC26901; MLF28_5X6; PARTNO MIC26901YJL-TR
L1: 3.3uH; SRP1265A; PARTNO SRP1265A-3R3M
R19, R20, R29: 1R5; R0603B; PARTNO CRCW06031R50FKEA
R22, R23: 10k; R0603B; PARTNO CRCW060310K0FKEA
R25: 2k49; R0603B; PARTNO CRCW06032K49FKEA
R27: 475R; R0603B; PARTNO CRCW0603475RFKEA
R34: dnp; R0603B; PARTNO *

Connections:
+5V: C15.+, C26.2, L1.2, R25.2; also elsewhere on the board
+24V: C20.2, C21.2, C30.+, IC6.13 (PVIN), IC6.14 (PVIN), IC6.15 (PVIN), IC6.16 (PVIN), IC6.17 (PVIN), IC6.18 (PVIN), IC6.19 (PVIN), IC6.PVIN, R20.1, R22.2; also elsewhere on the board
GND: C15.-, C16.1, C17.1, C18.2, C20.1, C21.1, C30.-, IC6.2 (PGND), IC6.3 (NC), IC6.5 (PGND), IC6.6 (PGND), IC6.7 (PGND), IC6.8 (PGND), IC6.21 (PGND), IC6.23 (SGND), IC6.PGND, R27.1; also elsewhere on the board
unnamed: C25.2, D2.C (K), R29.2
unnamed: IC6.25 (PG), R23.1
unnamed: 5V-A_FAIL.C (CATHODE), R23.2
unnamed: C16.2, D2.A, IC6.1 (PVDD), R19.1
unnamed: 5V-A_FAIL.A (ANODE), C17.2, IC6.28 (VDD), R19.2
unnamed: C18.1, IC6.27 (VIN), R20.2
unnamed: IC6.26 (EN), R22.1
unnamed: C27.2, R34.2
unnamed: C26.1, C27.1, IC6.24 (FB), R25.1, R27.2
unnamed: IC6.20 (BST), R29.1
SW: C25.1, IC6.4 (SW), IC6.9 (SW), IC6.10 (SW), IC6.11 (SW), IC6.12 (SW), IC6.22 (CS), IC6.SW, L1.1, R34.1

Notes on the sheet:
5v supply (1 of 3)
7x7 LED board


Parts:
5V-B_FAIL: red; CHIPLED_0603; PARTNO LTST-C190KRKT
C70: 220uF; E3,5-8; PARTNO 16SEPC220MD
C72: 2.2uF; C0603B; PARTNO C1608X5R1V225K080AC
C73, C75: 1uF; C0603B; PARTNO CGA3E3X5R1H105K080AB
C76, C77: 4.7uF; C1206NT; PARTNO UMK316AB7475KL-T
C78: .1uF; C0603B; PARTNO CGA3E2X7R1H104K080AA
C80: .1uF; C0603B; PARTNO *
C81: dnp; C0603B; PARTNO *
C82: 68uF; E5-10,5; PARTNO PLV1H680MDL1
D3: SD103AW; SOD-323; PARTNO SD103AWS-7-F
IC21: MIC26901; MLF28_5X6; PARTNO MIC26901YJL-TR
L3: 3.3uH; SRP1265A; PARTNO SRP1265A-3R3M
R84, R86, R92: 1R5; R0603B; PARTNO CRCW06031R50FKEA
R87, R88: 10k; R0603B; PARTNO CRCW060310K0FKEA
R90: 2k49; R0603B; PARTNO CRCW06032K49FKEA
R91: 475R; R0603B; PARTNO CRCW0603475RFKEA
R93: dnp; R0603B; PARTNO *

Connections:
+5VB: C70.+, C80.2, L3.2, R90.2; also elsewhere on the board
+24V: C76.2, C77.2, C82.+, IC21.13 (PVIN), IC21.14 (PVIN), IC21.15 (PVIN), IC21.16 (PVIN), IC21.17 (PVIN), IC21.18 (PVIN), IC21.19 (PVIN), IC21.PVIN, R86.1, R87.2; also elsewhere on the board
GND: C70.-, C72.1, C73.1, C75.2, C76.1, C77.1, C82.-, IC21.2 (PGND), IC21.3 (NC), IC21.5 (PGND), IC21.6 (PGND), IC21.7 (PGND), IC21.8 (PGND), IC21.21 (PGND), IC21.23 (SGND), IC21.PGND, R91.1; also elsewhere on the board
unnamed: C78.2, D3.C (K), R92.2
unnamed: IC21.25 (PG), R88.1
unnamed: 5V-B_FAIL.C (CATHODE), R88.2
unnamed: C72.2, D3.A, IC21.1 (PVDD), R84.1
unnamed: 5V-B_FAIL.A (ANODE), C73.2, IC21.28 (VDD), R84.2
unnamed: C75.1, IC21.27 (VIN), R86.2
unnamed: IC21.26 (EN), R87.1
unnamed: C81.2, R93.2
unnamed: C80.1, C81.1, IC21.24 (FB), R90.1, R91.2
unnamed: IC21.20 (BST), R92.1
SW1: C78.1, IC21.4 (SW), IC21.9 (SW), IC21.10 (SW), IC21.11 (SW), IC21.12 (SW), IC21.22 (CS), IC21.SW, L3.1, R93.1

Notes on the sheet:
5v supply (2 of 3)
7x7 LED board

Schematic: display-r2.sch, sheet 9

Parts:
5V-C_FAIL: red; CHIPLED_0603; PARTNO LTST-C190KRKT
C19: 68uF; E5-10,5; PARTNO PLV1H680MDL1
C22: dnp; C0603B; PARTNO *
C23: .1uF; C0603B; PARTNO *
C24: .1uF; C0603B; PARTNO CGA3E2X7R1H104K080AA
C28, C29: 4.7uF; C1206NT; PARTNO UMK316AB7475KL-T
C31, C32: 1uF; C0603B; PARTNO CGA3E3X5R1H105K080AB
C33: 2.2uF; C0603B; PARTNO C1608X5R1V225K080AC
C34: 220uF; E3,5-8; PARTNO 16SEPC220MD
D1: SD103AW; SOD-323; PARTNO SD103AWS-7-F
IC7: MIC26901; MLF28_5X6; PARTNO MIC26901YJL-TR
L2: 3.3uH; SRP1265A; PARTNO SRP1265A-3R3M
R21: dnp; R0603B; PARTNO *
R24, R36, R37: 1R5; R0603B; PARTNO CRCW06031R50FKEA
R26: 475R; R0603B; PARTNO CRCW0603475RFKEA
R28: 2k49; R0603B; PARTNO CRCW06032K49FKEA
R31, R33: 10k; R0603B; PARTNO CRCW060310K0FKEA

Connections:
+5VC: C23.2, C34.+, L2.2, R28.2; also elsewhere on the board
+24V: C19.+, C28.2, C29.2, IC7.13 (PVIN), IC7.14 (PVIN), IC7.15 (PVIN), IC7.16 (PVIN), IC7.17 (PVIN), IC7.18 (PVIN), IC7.19 (PVIN), IC7.PVIN, R33.2, R36.1; also elsewhere on the board
GND: C19.-, C28.1, C29.1, C31.2, C32.1, C33.1, C34.-, IC7.2 (PGND), IC7.3 (NC), IC7.5 (PGND), IC7.6 (PGND), IC7.7 (PGND), IC7.8 (PGND), IC7.21 (PGND), IC7.23 (SGND), IC7.PGND, R26.1; also elsewhere on the board
unnamed: C24.2, D1.C (K), R24.2
unnamed: IC7.25 (PG), R31.1
unnamed: 5V-C_FAIL.C (CATHODE), R31.2
unnamed: C33.2, D1.A, IC7.1 (PVDD), R37.1
unnamed: 5V-C_FAIL.A (ANODE), C32.2, IC7.28 (VDD), R37.2
unnamed: C31.1, IC7.27 (VIN), R36.2
unnamed: IC7.26 (EN), R33.1
unnamed: C22.2, R21.2
unnamed: C22.1, C23.1, IC7.24 (FB), R26.2, R28.1
unnamed: IC7.20 (BST), R24.1
SW2: C24.1, IC7.4 (SW), IC7.9 (SW), IC7.10 (SW), IC7.11 (SW), IC7.12 (SW), IC7.22 (CS), IC7.SW, L2.1, R21.1

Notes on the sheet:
5v supply (3 of 3)
7x7 LED board



Board: 4 copper layers, 333.0 x 333.0 mm, 439 parts (28 on the bottom side), 412 nets.

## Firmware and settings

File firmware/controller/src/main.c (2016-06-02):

/*
 * Copyright 2016 Google Inc. All Rights Reserved.
 *
 * Licensed under the Apache License, Version 2.0 (the "License");
 * you may not use this file except in compliance with the License.
 * You may obtain a copy of the License at
 *
 *     http://www.apache.org/licenses/LICENSE-2.0
 *
 * Unless required by applicable law or agreed to in writing, software
 * distributed under the License is distributed on an "AS IS" BASIS,
 * WITHOUT WARRANTIES OR CONDITIONS OF ANY KIND, either express or implied.
 * See the License for the specific language governing permissions and
 * limitations under the License.
 */

/* Includes ------------------------------------------------------------------*/
#include "project_config.h"
#include "stm32f4x7_eth.h"
#include "netconf.h"
#include "main.h"
#include <stdio.h>
#include <string.h>
#include "fifo.h"
#include "textfuncs.h"
#include "buttons.h"
#include "LEDproto.h"
#include "uart.h"
#include "pins.h"
#include <math.h>

#include "lwip/udp.h"
#include "lwip/debug.h"

/* Private typedef -----------------------------------------------------------*/
/* Private define ------------------------------------------------------------*/
#define SYSTEMTICK_PERIOD_MS  1
#define PANEL_NW 0
#define USART_NW 3

#define PANEL_NE 1
#define USART_NE 0

#define PANEL_SW 2
#define USART_SW 2

#define PANEL_SE 3
#define USART_SE 1

#define POWER_ROW 3

#define BL_MODE_INACTIVE 0
#define BL_MODE_WAITING 1
#define BL_MODE_ACTIVE 2

//#define TEST_MODES

/* Private macro -------------------------------------------------------------*/
/* Private variables ---------------------------------------------------------*/
__IO uint32_t LocalTime = 0; /* this variable is used to create a time reference incremented by 1ms */
uint32_t timingdelay;

int activePacketIdx = 0;
int readingPacketIdx = 1;
int32_t packets[2][128];
uint32_t lastPacketTime = 0;
uint32_t lastUDPReceivePacketTime = 0;
uint32_t lastButtonPacketTime = 0;
uint32_t lastStatusPacketTime = 0;
uint32_t debugRebootTime = 0;
int debugRebootVal = 1;

int maxPacketDelay = 33;  // at a minimum send a packet every 33ms
int minPacketDelay = 12;  // don't send packets any faster than this to the LED board
int minButtonPacketDelay = 33;
int minStatusPacketDelay = 250;

int activeValveCount = 0;

// these are actually defined as extern in main.h
int IP_lastOctet;
int mac_last_octet;

struct udp_pcb * global_pcb;
struct ip_addr udp_dest;

int global_row = -1;
int global_column = -1;


int bootloaderMode = BL_MODE_INACTIVE;
int bootloaderTimeout = 5000;

const uint8_t panelLEDmap[] = { 87, 88, 89,  90, 91, 92,  93, 94, 95,  65, 66, 67,  68, 69, 70, 100,101,102, 103,104,105,
                                84, 85, 86,  81, 82, 83,  77, 78, 79,  74, 75, 76,  71, 72, 73,  97, 98, 99, 106,107,108,
                                55, 56, 57,  58, 59, 60,  61, 62, 63,  33, 34, 35,  36, 37, 38, 125,126,127, 109,110,111,
                                52, 53, 54,  49, 50, 51,  45, 46, 47,  42, 43, 44,  39, 40, 41, 122,123,124, 113,114,115,
                                23, 24, 25,  26, 27, 28,  29, 30, 31,   1,  2,  3,   4,  5,  6, 119,120,121, 116,117,118,
                                20, 21, 22,  17, 18, 19, 151,152,153, 154,155,156, 157,158,159, 129,130,131, 132,133,134,
                                13, 14, 15,  10, 11, 12, 148,149,150, 145,146,147, 141,142,143, 138,139,140, 135,136,137 };

const uint8_t panelButtonMap[] = { 96, 97, 98, 99,100,148,153,
                                  101,102,103,104,105,147,152,
                                   48, 49, 50, 51, 52,146,151,
                                   53, 54, 55, 56, 57,145,150,
                                    0,  1,  2,  3,  4,144,149,
                                    5,  6,192,193,194,195,196,
                                    7,  8,197,198,199,200,201 };

ledPacket_type ledpackets[4];

// default fixed point 30.0==7680
uint16_t fan_slope[4] = {7680,7680,7680,7680}; // 8 bits fractional component
uint16_t fan_intercept[4] = {800,800,800,800}; // duty cycle at 80 degrees F
uint16_t fan_min[4] = {300,300,300,300};       // minimum fan duty cycle
uint16_t fan_duty[4] = {1024,1024,1024,1024};  // active fan duty cycle
uint16_t fan_setpoint[4] = {1024,1024,1024,1024}; // initial fan setpoint
uint8_t fan_mode[4] = {1,1,1,1};               // fan mode 0->setpoint mode, 1->temperature based auto mode
uint8_t fan_tach[4][9];                        // fan speed window filter.  First 8 entries are readings, 9th entry is index where next reading will be stored within the 8 entries.
uint8_t serialNum[4][6];                       // serial number values retrieved from the LED boards
uint32_t uptimes[20];                          // uptimes for the 5 processors on each of the 4 LED boards

uint8_t buttonpacket[29] = {32,0,0,0,
                            0,0,0,0,0, 0,0,0,0,0, 0,0,0,0,0, 0,0,0,0,0, 0,0,0,0,0};
uint8_t temperatures[196];
uint8_t panel_avg_temp[4];

/* Private function prototypes -----------------------------------------------*/

/* Private functions ---------------------------------------------------------*/

/**
 * Set the 12bit PWM value for an LED channel based on full panel(4 LED PCBs) addressing
 * @param index row * 3(RGB) * 14(LEDs/row) + column
 * @param value the new value to assign to the indexed entry
 */
void globalSet(int index, int value) {
    int global_row = index / 3 / 14;
    int global_column = (index / 3) % 14;
    int channel = index % 3;
    int panel_row = global_row % 7;
    int panel_column = global_column % 7;
    int panel_index = (global_row / 7)*2+(global_column / 7);
    pack12bit(ledpackets[panel_index].s.payload, panelLEDmap[(panel_row*7+panel_column)*3+channel], value);
}
/**
 * Set the 8bit PWM value for an LED channel based on full panel(4 LED PCBs) addressing
 * @param index row * 3(RGB) * 14(LEDs/row) + column
 * @param value the new value to assign to the indexed entry
 */
void globalSet8bit(int index, uint8_t value) {
    int global_row = index / 3 / 14;
    int global_column = (index / 3) % 14;
    int channel = index % 3;
    int panel_row = global_row % 7;
    int panel_column = global_column % 7;
    int panel_index = (global_row / 7)*2+(global_column / 7);
    int addr = panelLEDmap[(panel_row*7+panel_column)*3+channel];
    addr += (addr>>5)*16;   // make sure things are in the correct places for the 5 LED board CPUs to find them
    ledpackets[panel_index].s.payload[addr] = value;
}
/**
 * Update the bit in the button packet corresponding to a specific button.  Addressing is based on row/column on a specific LED board
 * @param boardButtonIndex The index of the button within a specific LED board (row*7+column)
 * @param value The state of the button
 * @param panel The quadrant of the panel which the specific board occupies
 */
void globalButtonSet(int boardButtonIndex, int value, int panel) {
    int col = boardButtonIndex % 7;
    int row = boardButtonIndex / 7;
    int bitAddr;

    switch(panel) {
        case PANEL_NW:
            bitAddr = row * 14 + col;
            break;
        case PANEL_NE:
            bitAddr = row * 14 + col + 7;
            break;
        case PANEL_SW:
            bitAddr = (row + 7) * 14 + col;
            break;
        case PANEL_SE:
            bitAddr = (row + 7) * 14 + col + 7;
            break;
    }
    int byteAddr = bitAddr / 8;
    int bitOffset = 7-(bitAddr - (byteAddr*8));

    if(value)
        buttonpacket[4+byteAddr] |= (1 << bitOffset);
    else
        buttonpacket[4+byteAddr] &= ~(1 << bitOffset);
}
/**
 * Read the bit in the button packet corresponding to a specific button.  Addressing is based on row/column on a specific LED board
 * @param boardButtonIndex The index of the button within a specific LED board (row*7+column)
 * @param panel The quadrant of the panel which the specific board occupies
 * @return true if the button is pressed, otherwise false
 */
 bool globalGetButtonState(int boardButtonIndex, int panel) {
    int col = boardButtonIndex % 7;
    int row = boardButtonIndex / 7;
    int bitAddr;

    switch(panel) {
        case PANEL_NW:
            bitAddr = row * 14 + col;
            break;
        case PANEL_NE:
            bitAddr = row * 14 + col + 7;
            break;
        case PANEL_SW:
            bitAddr = (row + 7) * 14 + col;
            break;
        case PANEL_SE:
            bitAddr = (row + 7) * 14 + col + 7;
            break;
    }
    int byteAddr = bitAddr / 8;
    int bitOffset = 7-(bitAddr - (byteAddr*8));
    if( buttonpacket[4+byteAddr] & (1 << bitOffset) )
        return true;
    return false;
}

/**
 * Checks for data from one of the LED boards and if a full packet is available it is read from the FIFO
 * and processed to update fan speed, temperatures and average temperature, serial number, and uptimes
 * @param usart_idx Index of the USART struct to read data from
 * @param panel_idx location of the board within the panel connected to this USART
 */
void handle_feedback(int usart_idx, int panel_idx) {
    int i, r, c;
    int row_offset, col_offset;
    int workTemp, avgTemp;
    ledPacket_type inPkt;
    DEBUGPIN_SET(1);
    i = UART_RX_frame_available(&usarts[usart_idx]);
    //printf("avail=%d ",i);
    switch(panel_idx) {
        case PANEL_NW:
            row_offset = 0; col_offset = 0; break;
        case PANEL_NE:
            row_offset = 0; col_offset = 7; break;
        case PANEL_SW:
            row_offset = 7; col_offset = 0; break;
        case PANEL_SE:
            row_offset = 7; col_offset = 7; break;
    }

    if(i == LED_PACKET_LEN) { // got valid packet length so process
        UART_RX_read(&usarts[usart_idx], inPkt.a, i);
        avgTemp = 0;

        if(inPkt.s.type >= 0x20)
            return;

        for(r = 0; r < 7; r++) {
            for(c = 0; c < 7; c++) {
                // update button state in global map
                globalButtonSet(7*r+c, inPkt.s.payload[ panelButtonMap[7*r+c] ], panel_idx);
                // update temperatures
                workTemp = inPkt.s.payload[ panelButtonMap[7*r+c] + 10 ];
                temperatures[14*(r+row_offset)+c+col_offset] = workTemp;
                avgTemp += workTemp;
            }
        }
        avgTemp /= 49;
        panel_avg_temp[panel_idx] = avgTemp;

        // calculate new fan speed if in auto mode
        if(fan_mode[panel_idx] == 1)
            fan_duty[panel_idx] = ((fan_slope[panel_idx]*(avgTemp-80)) >> 8) + fan_intercept[panel_idx];
            if(fan_duty[panel_idx] < fan_min[panel_idx])
                fan_duty[panel_idx] = fan_min[panel_idx];

        // update fan status
        uint32_t workVal = 0;
        for(i = 0; i < 4; i++) {
            workVal <<= 8;
            workVal |= inPkt.s.payload[48*3+20+i];
        }
        if(workVal == 65535)
            workVal = 0;
        else
            workVal = 360000/workVal;

        if(workVal == 0 || (workVal > 7 && workVal < 250)) {
            fan_tach[panel_idx][fan_tach[panel_idx][8]&0x07] = (uint8_t)workVal;
            fan_tach[panel_idx][8]++;
        }

        // update serial number
        for(i = 0; i < 6; i++)
            serialNum[panel_idx][i] = inPkt.s.payload[20+i];

        // update uptimes (5 per panel)
        uptimes[panel_idx] = 0;
        for(i = 0; i < 4; i++) {
            uptimes[panel_idx] <<= 8;
            uptimes[panel_idx] |= inPkt.s.payload[48*3+32+i];
        }
    } else {
        if(i > 0) { // got unexpected length packet so flush buffer
            char buf[512];
            if(i > 512)
                i = 512;
            UART_RX_read(&usarts[usart_idx], buf, i);
        }
    }
    DEBUGPIN_CLR(1);
}

/**
 * handle responses from last packets and send out new packets to each of the 4 LED boards
 */
void sendLEDpackets(void) {
    // read before writing so there was enough time to get things back
    handle_feedback(USART_NW, PANEL_NW);
    handle_feedback(USART_SW, PANEL_SW);
    handle_feedback(USART_SE, PANEL_SE);
    handle_feedback(USART_NE, PANEL_NE);

    UART_SendBytes(&usarts[3], ledpackets[PANEL_NW].a, sizeof(ledPacket_type));
    UART_SendBytes(&usarts[2], ledpackets[PANEL_SW].a, sizeof(ledPacket_type));
    UART_SendBytes(&usarts[1], ledpackets[PANEL_SE].a, sizeof(ledPacket_type));
    UART_SendBytes(&usarts[0], ledpackets[PANEL_NE].a, sizeof(ledPacket_type));
    lastPacketTime = LocalTime;
}
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
int main(void)
{
  /*!< At this stage the microcontroller clock setting is already configured to
       168 MHz, this is done through SystemInit() function which is called from
       startup file (startup_stm32f4xx.s) before to branch to application main.
       To reconfigure the default setting of SystemInit() function, refer to
       system_stm32f4xx.c file
     */
    int i;

    struct pbuf *p;

    NVIC_PriorityGroupConfig(NVIC_PriorityGroup_4);

    /* configure ethernet (GPIOs, clocks, MAC, DMA) */
    printf("about to start ethernet config\n");
    ETH_BSP_Config();

    // Determine the IP address based on dip switch position
    BUTTONS_Config();
    PIN_Config();
    CONFIG_pins(pins_powerctrl, PWRCTRL_NUM_PINS);
    PIN_Num(pins_debug, 0, DEBUGPIN_NUM);

    PIN_Low(pins_powerctrl, PWR_CTRL_AC_0);
    PIN_Low(pins_powerctrl, PWR_CTRL_AC_1);

    Delay(10);
    i = BUTTONS_Read_All();
    #ifdef TEST_MODES
        i = 2;
    #endif
    global_row = (i >> 4) & 0xF;
    global_column = i & 0xF;
    IP_lastOctet = 20+global_row*10+global_column;
    mac_last_octet = 20+global_row*10+global_column;
    printf("IP: 192.168.0.%d", IP_lastOctet);

    IP4_ADDR(&udp_dest, IP_ADDR0, IP_ADDR1, IP_ADDR2, 10);

    /* Initilaize the LwIP stack */
    LwIP_Init();

    // Initialize, bind, and setup callback for UDP
    udp_recv_init();

    if(global_row != POWER_ROW) {
        // this is a normal panel (not a power box)
        UART_Config(&usarts[0]);
        UART_Config(&usarts[1]);
        UART_Config(&usarts[2]);
        UART_Config(&usarts[3]);

        Delay(10);

        //startBootloader();
        //doBootloaderTest();

        // Wait for initialization of LED board firmware and debug display
        Delay(7000);

        // run through sequence of setting dot correction
        int dotval = 58;
        while(dotval <= 63) {
            Delay(50);
            // set dot correction
            ledPacket_type pkt;
            memset(pkt.a, 0, sizeof(ledPacket_type));
            pkt.s.type = PKT_TYPE_DOTCORRECT_PACK12;
            for(i = 0; i < 49; i++) {
                pack12bit(pkt.s.payload, panelLEDmap[i*3+1], dotval);
                #ifdef TEST_MODES
                    pack12bit(pkt.s.payload, panelLEDmap[i*3], dotval*12/16);
                    pack12bit(pkt.s.payload, panelLEDmap[i*3+2], dotval*12/16);
                #else
                    pack12bit(pkt.s.payload, panelLEDmap[i*3  ], dotval/2);
                    pack12bit(pkt.s.payload, panelLEDmap[i*3+2], dotval/2);
                #endif
            }
            UART_SendBytes(&usarts[0], pkt.a, sizeof(ledPacket_type));
            UART_SendBytes(&usarts[1], pkt.a, sizeof(ledPacket_type));
            UART_SendBytes(&usarts[2], pkt.a, sizeof(ledPacket_type));
            UART_SendBytes(&usarts[3], pkt.a, sizeof(ledPacket_type));
            Delay(50);
            ledpackets[PANEL_NW].s.type = PKT_TYPE_GSVALS;
            for(i = 0; i <7*3; i++)
                pack12bit(ledpackets[PANEL_NW].s.payload, panelLEDmap[i], 800);
            for(; i <49*3; i++)
                pack12bit(ledpackets[PANEL_NW].s.payload, panelLEDmap[i], 0);
            UART_SendBytes(&usarts[3], ledpackets[PANEL_NW].a, sizeof(ledpackets[PANEL_NW].a));
            UART_SendBytes(&usarts[2], ledpackets[PANEL_NW].a, sizeof(ledpackets[PANEL_NW].a));
            UART_SendBytes(&usarts[1], ledpackets[PANEL_NW].a, sizeof(ledpackets[PANEL_NW].a));
            UART_SendBytes(&usarts[0], ledpackets[PANEL_NW].a, sizeof(ledpackets[PANEL_NW].a));
            dotval++;
            Delay(30);
        }
        // set calibration to a 2.2 gamma curve
        {
            int j;
            float value;
            uint16_t iValue;
            ledpackets[PANEL_NW].s.type = PKT_TYPE_SET_LOOKUP;
            for(i = 0; i < 65; i++) {
                value = 4000*pow( (float)i/65.0, 2.2);
                iValue = ((uint16_t)value) & 0xFFF;
                for(j = 0; j < 49*3; j++) {
                    pack12bit(ledpackets[PANEL_NW].s.payload, panelLEDmap[j], iValue);
                }
                ledpackets[PANEL_NW].s.param1 = i;
                UART_SendBytes(&usarts[3], ledpackets[PANEL_NW].a, sizeof(ledpackets[PANEL_NW].a));
                UART_SendBytes(&usarts[2], ledpackets[PANEL_NW].a, sizeof(ledpackets[PANEL_NW].a));
                UART_SendBytes(&usarts[1], ledpackets[PANEL_NW].a, sizeof(ledpackets[PANEL_NW].a));
                UART_SendBytes(&usarts[0], ledpackets[PANEL_NW].a, sizeof(ledpackets[PANEL_NW].a));
                Delay(30);
            }
        }
        // turn off all channels
        ledpackets[PANEL_NW].s.type = PKT_TYPE_GSVALS;
        for(i = 0; i <49*3; i++) {
            pack12bit(ledpackets[PANEL_NW].s.payload, panelLEDmap[i], 0);
        }
        UART_SendBytes(&usarts[3], ledpackets[PANEL_NW].a, sizeof(ledpackets[PANEL_NW].a));
        UART_SendBytes(&usarts[2], ledpackets[PANEL_NW].a, sizeof(ledpackets[PANEL_NW].a));
        UART_SendBytes(&usarts[1], ledpackets[PANEL_NW].a, sizeof(ledpackets[PANEL_NW].a));
        UART_SendBytes(&usarts[0], ledpackets[PANEL_NW].a, sizeof(ledpackets[PANEL_NW].a));

        // Startup sequence that lights all the LEDs one at a time
        ledpackets[PANEL_NW].s.type = PKT_TYPE_GSVALS;
        for(i = 0; i <49*3+1; i++) {
            if(i < 49*3)
                pack12bit(ledpackets[PANEL_NW].s.payload, panelLEDmap[i], 800);
            if(i > 0)
                pack12bit(ledpackets[PANEL_NW].s.payload, panelLEDmap[i-1], 0);
            UART_SendBytes(&usarts[3], ledpackets[PANEL_NW].a, sizeof(ledpackets[PANEL_NW].a));
            UART_SendBytes(&usarts[2], ledpackets[PANEL_NW].a, sizeof(ledpackets[PANEL_NW].a));
            UART_SendBytes(&usarts[1], ledpackets[PANEL_NW].a, sizeof(ledpackets[PANEL_NW].a));
            UART_SendBytes(&usarts[0], ledpackets[PANEL_NW].a, sizeof(ledpackets[PANEL_NW].a));

            Delay(10);
        }

        #ifdef TEST_MODES
            test_modes();
        #endif

        //buttonTest();
    }

    // Normal execution infinite while loop
    while(1) {
        if (ETH_CheckFrameReceived()) {
            /* process received ethernet packet*/
            LwIP_Pkt_Handle();
        }

        // for normal panels send packet to LED boards if overdue and not in bootloader mode
        if(global_row != POWER_ROW && LocalTime - lastPacketTime >= maxPacketDelay && bootloaderMode == BL_MODE_INACTIVE) {
            sendLEDpackets();
            DEBUGPIN_TGL(8);
        }

        if(global_row == POWER_ROW) {
            // This is a power box controller
            if(LocalTime-lastStatusPacketTime >= minStatusPacketDelay) {
                lastStatusPacketTime = LocalTime;
                p = pbuf_alloc(PBUF_TRANSPORT, 4+6+2+2, PBUF_RAM);
                i = 0;
                ((uint8_t*)p->payload)[i++] = 0x22;
                ((uint8_t*)p->payload)[i++] = 0x0;
                ((uint8_t*)p->payload)[i++] = 0x0;
                ((uint8_t*)p->payload)[i++] = 0x0;
                ((uint8_t*)p->payload)[i++] = PIN_State(pins_powerctrl, PWR_MON_0_0);
                ((uint8_t*)p->payload)[i++] = PIN_State(pins_powerctrl, PWR_MON_0_1);
                ((uint8_t*)p->payload)[i++] = PIN_State(pins_powerctrl, PWR_MON_0_2);
                ((uint8_t*)p->payload)[i++] = PIN_State(pins_powerctrl, PWR_MON_1_0);
                ((uint8_t*)p->payload)[i++] = PIN_State(pins_powerctrl, PWR_MON_1_1);
                ((uint8_t*)p->payload)[i++] = PIN_State(pins_powerctrl, PWR_MON_1_2);
                ((uint8_t*)p->payload)[i++] = !PIN_State(pins_powerctrl, PWR_MON_AC_0);
                ((uint8_t*)p->payload)[i++] = !PIN_State(pins_powerctrl, PWR_MON_AC_1);
                ((uint8_t*)p->payload)[i++] = PIN_State(pins_powerctrl, PWR_CTRL_AC_0);
                ((uint8_t*)p->payload)[i++] = PIN_State(pins_powerctrl, PWR_CTRL_AC_1);
                udp_sendto(global_pcb, p, &udp_dest, 27482);
                /* free the pbuf */
                pbuf_free(p);
            }
        } else {
            // This is an LED panel controller
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

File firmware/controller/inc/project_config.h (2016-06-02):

/*
 * Copyright 2016 Google Inc. All Rights Reserved.
 *
 * Licensed under the Apache License, Version 2.0 (the "License");
 * you may not use this file except in compliance with the License.
 * You may obtain a copy of the License at
 *
 *     http://www.apache.org/licenses/LICENSE-2.0
 *
 * Unless required by applicable law or agreed to in writing, software
 * distributed under the License is distributed on an "AS IS" BASIS,
 * WITHOUT WARRANTIES OR CONDITIONS OF ANY KIND, either express or implied.
 * See the License for the specific language governing permissions and
 * limitations under the License.
 */

#ifndef __PROJECT_CONFIG_H
#define __PROJECT_CONFIG_H

#include "stm32f4xx.h"
#include "core_cm4.h"
#include <stdbool.h>
#include <stdint.h>
#include <stddef.h>
#include <assert.h>
#include "fifo.h"

typedef struct {
	GPIO_TypeDef* GPIOx;
	uint16_t pin;
	GPIOSpeed_TypeDef speed;
	GPIOMode_TypeDef mode;
	GPIOOType_TypeDef otype;
	GPIOPuPd_TypeDef PuPd;
	uint8_t pinsource;
	uint8_t af;
} CONFIG_Pin_TypeDef;

typedef struct {
	ADC_TypeDef* ADCx;
	uint8_t channel;
	uint8_t rank;
	uint8_t sampleTime;
} CONFIG_ADC_TypeDef;

typedef struct {
    uint32_t channel;
    DMA_Stream_TypeDef * stream;
    uint32_t flag;
} CONFIG_DMA_Channel;

typedef struct {
    // buffers and fifo
    const uint32_t tx_buf_size;
    const uint32_t rx_buf_size;
    uint8_t *tx_buf;
    uint8_t *rx_buf;
    FIFO_Data_TypeDef *rx_fifo;
    // pins
    CONFIG_Pin_TypeDef *pins;
    const uint32_t num_pins;
    // hardware initialization
    const uint32_t ahb1;
    const uint32_t apb1;
    const uint32_t apb2;
    const uint32_t IRQn;
    const uint32_t DR_ADDR; // TX data register address for DMA transfer
    const uint32_t DMA_channel;
    DMA_Stream_TypeDef *DMA_stream;
    DMA_TypeDef *DMAx;
    USART_TypeDef * USARTx;
    const uint32_t DMA_IntFlags;
    // state
    uint32_t baud;
    bool TX_active;
    bool configured;
    uint16_t frame_available;    // used to keep track of how many bytes were available at the start of the most recent idle bus condition
} CONFIG_USART_ConfigState;

void CONFIG_Setup(void);
void CONFIG_pins(const CONFIG_Pin_TypeDef *pins, int num_pins);

#define DISABLE_SLEEP 0
#define ENABLE_SLEEP_DEBUG 1

//////////////// ITEMS NOT DEPENDENT ON BOARD LAYOUT ////////////


//////////////////////////////////////////////////////////////////////////////
//////////////////// REV 1 ///////////////////////////////////////////////////
//////////////////////////////////////////////////////////////////////////////

#ifdef REV1
	#ifdef REV_SELECTED
		#error Already selected a board revision
	#else
		#define REV_SELECTED
	#endif

	////////////////////////// LED_MATRIX ///////////////////////////////
	#define LED_MATRIX_PINS (3)
	#define LED_MATRIX_USARTx (USART1)
	#define LED_MATRIX_AHB1 (RCC_AHB1Periph_DMA2 | RCC_AHB1Periph_GPIOA)
	#define LED_MATRIX_APB1 (0)
	#define LED_MATRIX_APB2 (RCC_APB2Periph_USART1)
	#define LED_MATRIX_BAUD 1000000
	#define LED_MATRIX_TX_BUFFER_SIZE 3
	#define LED_MATRIX_NVIC_CHAN USART1_IRQn
	#define LED_MATRIX_IRQ_HANDLER LEDmatrix_handler
	extern const CONFIG_Pin_TypeDef pin_led_matrix[];
    // this is the index into the pins array for the latching line
	#define LED_MATRIX_PIN_LATCH 2
	extern const CONFIG_DMA_Channel dma_led_matrix_tx;

	//////////////////////////// BUTTONS //////////////////////////////////
	// actually hex switch
	#define BUTTONS_POWER_AHB1  (RCC_AHB1Periph_GPIOD)
	#define BUTTONS_NUM 8
	#define BUTTONS_POLARITY 0
	extern const CONFIG_Pin_TypeDef pin_buttons[];

	/////////////////////////// DEBUG PINS ////////////////////////
    #define DEBUGPIN_POWER_AHB1 (RCC_AHB1Periph_GPIOE)
    extern const CONFIG_Pin_TypeDef pins_debug[];
    #define DEBUGPIN_NUM 13


	////////////////////////// SPI_SHIFT_REG //////////////////////////////
	#define SPI_SHIFT_REG_PINS (5)
	#define SPI_SHIFT_REG_SPIx (SPI2)
	#define SPI_SHIFT_REG_BITS 192
	#define SPI_SHIFT_REG_CHANS 128
	#define SPI_SHIFT_REG_BUFSIZE 32
	#define SPI_SHIFT_REG_AHB1  (RCC_AHB1Periph_DMA1 | RCC_AHB1Periph_GPIOB | RCC_AHB1Periph_GPIOD)
	#define SPI_SHIFT_REG_APB1 (RCC_APB1Periph_SPI2)
	#define SPI_SHIFT_REG_APB2 (0)
	extern const CONFIG_Pin_TypeDef pin_spi_shift_reg[];
	#define SPI_SHIFT_REG_PIN_CS 3
	#define SPI_SHIFT_REG_PIN_RST 4
	extern const CONFIG_DMA_Channel dma_spi_shift_tx;
	extern const CONFIG_DMA_Channel dma_spi_shift_rx;

	///////////////////////// I2C /////////////////////////////////
	#define I2CDEV_POWER_APB1 (RCC_APB1Periph_I2C1)
	#define I2CDEV_POWER_APB2 (RCC_APB2Periph_GPIOB)
	#define I2CDEV_ADDRESS (0x00)
	#define I2CDEV_CLOCK (400000)
	#define I2CDEV_SHORT_TIMEOUT (0x2000)
	#define I2CDEV_START_TIMEOUT (10*I2CDEV_SHORT_TIMEOUT)
	#define I2CDEV_I2Cx (I2C1)
	extern const CONFIG_Pin_TypeDef pin_i2c_scl;
	extern const CONFIG_Pin_TypeDef pin_i2c_sda;

	uint32_t I2CDEV_TIMEOUT_Callback(void);	// defined in main.c
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

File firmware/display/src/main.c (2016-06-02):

/*
 * Copyright 2016 Google Inc. All Rights Reserved.
 *
 * Licensed under the Apache License, Version 2.0 (the "License");
 * you may not use this file except in compliance with the License.
 * You may obtain a copy of the License at
 *
 *     http://www.apache.org/licenses/LICENSE-2.0
 *
 * Unless required by applicable law or agreed to in writing, software
 * distributed under the License is distributed on an "AS IS" BASIS,
 * WITHOUT WARRANTIES OR CONDITIONS OF ANY KIND, either express or implied.
 * See the License for the specific language governing permissions and
 * limitations under the License.
 */

#include "project_config.h"
#include "uart.h"
#include "debugpin.h"
#include "TLC59401.h"
#include "buttons.h"
#include "LEDproto.h"
#include "11AA02E48.h"
#include "analog.h"

__IO uint32_t LocalTime = 0; /* this variable is used to create a time reference incremented every 1ms */
uint32_t timingdelay;

#define TICKS_PER_MS 12
#define BLACK_TIMEOUT 5000

static uint32_t busAddress = 0;
static bool packetStarted = false;
//static bool busIdleDetected = true;
static int lastByteTime = 0;
static int packetIdx = 0;
static int fan_pwm = 2048;
static int led_pwm = 0;

static ledPacket_type inPacket;
static ledPacket_type outPacket;

static uint8_t MACaddr[6];

// mapping from thermistor index to analog channel
static const uint8_t analog_map[] = {9,8,7,5,6,0,1,2,3,4};

uint16_t FanCapture = 0;
uint32_t FanLastIrq = 0;

uint16_t captures[32];
uint16_t captureCounter = 0;

/**
 * interrupt handler for fan speed input timer
 */
void TIM3_IRQHandler(void) {
    static uint16_t CaptureNumber = 0;
    static uint16_t inval1, inval2;
    if(TIM_GetITStatus(TIM3, TIM_IT_CC1) == SET) {
        captures[captureCounter++ % 32] = TIM_GetCapture1(TIM3);
        // clear the CC interrupt pending bit
        TIM_ClearITPendingBit(TIM3, TIM_IT_CC1);
        if(CaptureNumber == 0) {
            inval1 = TIM_GetCapture1(TIM3);
            CaptureNumber = 1;
        }
        else if(CaptureNumber == 1) {
            inval2 = TIM_GetCapture1(TIM3);
            if(inval2 < inval1)
                FanCapture = (0xFFFF - inval1) - inval2;
            else
                FanCapture = inval2 - inval1;
            CaptureNumber = 0;
        }
        FanLastIrq = LocalTime;
    }
}

/**
 * Configures timers for fan tachometer monitoring and PWM output
 */
void fan_setup() {
    TIM_TimeBaseInitTypeDef tbis;
    TIM_OCInitTypeDef ocis;
    NVIC_InitTypeDef nvis;
    TIM_ICInitTypeDef icis;

    // Turn on peripherals
    RCC_AHBPeriphClockCmd(FAN_POWER_AHB, ENABLE);
    RCC_APB1PeriphClockCmd(FAN_POWER_APB1, ENABLE);
	RCC_APB2PeriphClockCmd(FAN_POWER_APB2, ENABLE);

    CONFIG_pins(pins_pwm, PWM_PINS_NUM);

    // First configure the PWM output
    tbis.TIM_Prescaler = 0;
    tbis.TIM_ClockDivision = TIM_CKD_DIV1;
    tbis.TIM_CounterMode = TIM_CounterMode_Up;
    tbis.TIM_Period = 1920;
    tbis.TIM_RepetitionCounter = 0;
    TIM_TimeBaseInit(TIM16, &tbis);

    ocis.TIM_OCMode = TIM_OCMode_PWM1;
    ocis.TIM_OutputState = TIM_OutputState_Enable;
    ocis.TIM_OutputNState = TIM_OutputNState_Disable;
    ocis.TIM_Pulse = 1000;
    ocis.TIM_OCPolarity = TIM_OCPolarity_High;
    ocis.TIM_OCNPolarity = TIM_OCNPolarity_High;
    ocis.TIM_OCIdleState = TIM_OCIdleState_Set;
    ocis.TIM_OCNIdleState = TIM_OCNIdleState_Reset;
    TIM_OC1Init(TIM16, &ocis);

    TIM_Cmd(TIM16, ENABLE);
    TIM_CtrlPWMOutputs(TIM16, ENABLE);

    // Now configure the Tach PWM input to measure rising edge to rising edge time
    icis.TIM_Channel = TIM_Channel_1;
    icis.TIM_ICPolarity = TIM_ICPolarity_Rising;
    icis.TIM_ICSelection = TIM_ICSelection_DirectTI;
    icis.TIM_ICPrescaler = TIM_ICPSC_DIV1;
    icis.TIM_ICFilter = 0x0;

    TIM_TimeBaseStructInit(&tbis);
    tbis.TIM_Prescaler = 199;
    tbis.TIM_ClockDivision = TIM_CKD_DIV4;
    tbis.TIM_CounterMode = TIM_CounterMode_Up;
    tbis.TIM_RepetitionCounter = 0;
    TIM_TimeBaseInit(TIM3, &tbis);

    TIM_ICInit(TIM3, &icis);
    TIM_Cmd(TIM3, ENABLE);
    TIM_ITConfig(TIM3, TIM_IT_CC1, ENABLE);

    nvis.NVIC_IRQChannel = TIM3_IRQn;
    nvis.NVIC_IRQChannelPriority = 0;
    nvis.NVIC_IRQChannelCmd = ENABLE;
    NVIC_Init(&nvis);
}

/**
 * Set the fan control PWM signal duty cycle
 * @param value 0-1920 range for the PWM duty cycle
 */
void fan_set_duty(uint16_t value) {
    TIM16->CCR1 = value;
}
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

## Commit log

2016-06-02 clean commit
    [GBW-003.DWG, GBW-300-1.DWG, GBW-300-2.DWG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]
2016-06-02 added GBW-200 assembly drawing
2016-06-02 added extra sheet to show the display board assembly procedure
2016-06-03 README.md: add syntax highlighting for code sample
2016-06-03 added pdfs for pcb bill of materials

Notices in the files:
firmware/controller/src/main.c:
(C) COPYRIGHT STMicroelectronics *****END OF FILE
